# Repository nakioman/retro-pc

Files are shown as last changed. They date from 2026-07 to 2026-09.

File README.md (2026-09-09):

# RetroBox

RetroBox is a self-contained retro computer: a Debian appliance that boots
straight into [86Box](https://86box.net/) fullscreen and lets you choose
between three virtual PCs. It is designed to feel like a physical computer
from the 1980s and 1990s, with the flexibility of a modern emulator.

 Front  | Rear
:------------------:|:------------------:
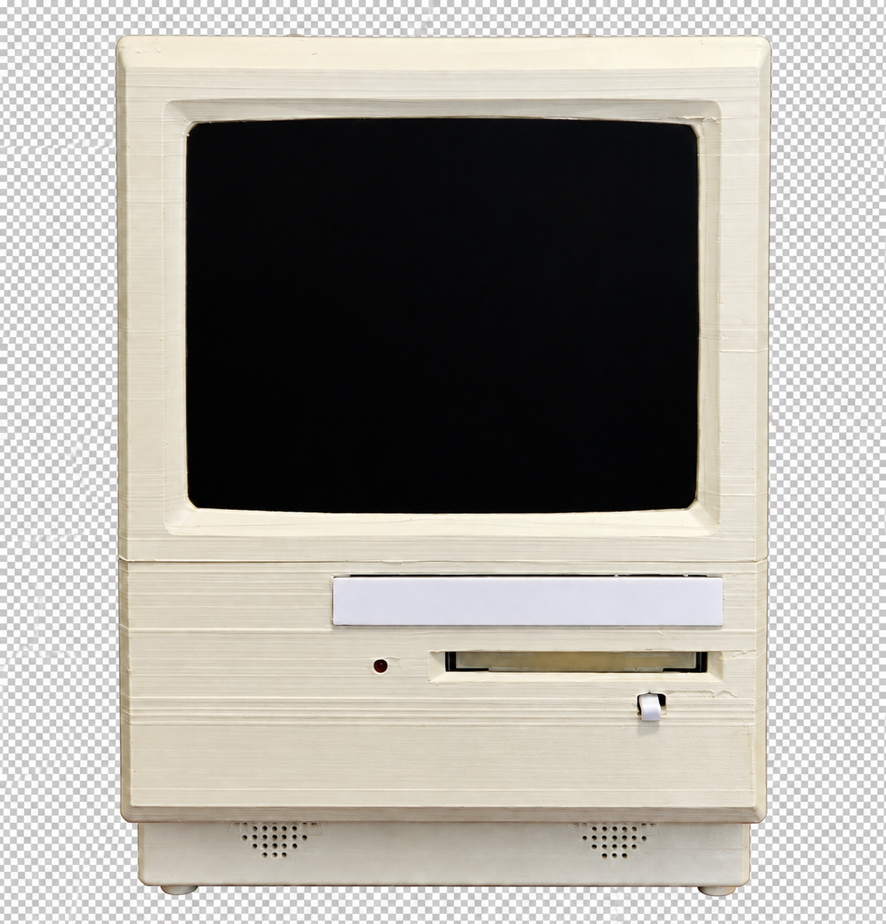
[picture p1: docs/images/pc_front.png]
RetroBox front view
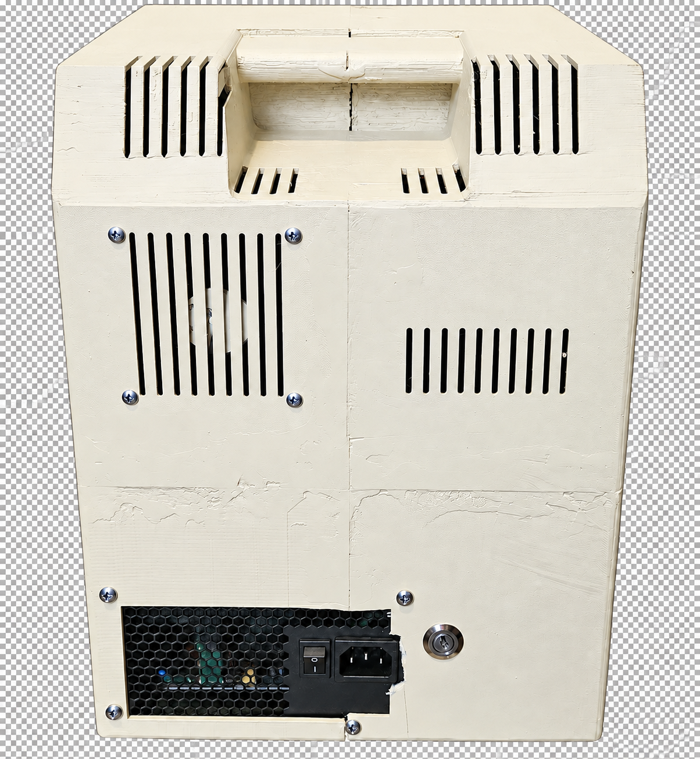
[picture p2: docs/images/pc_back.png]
RetroBox rear view
 | 

## The project at a glance

The reference build uses an Intel Core i3-14100, 8 GB of RAM, integrated
graphics, and an MSI PRO H610M-S DDR4 motherboard. Everything is installed in
a 3D-printed Macintosh Classic-style case, together with a real floppy drive,
an optical drive, and an LCD panel.

The appliance includes three 86Box profiles:

| Profile | Intended use |
| --- | --- |
| 386SX-16 | DOS and early software; 54 MB blank disk. |
| Pentium 100 | Mid-1990s games, Sound Blaster, and CD-ROM. |
| Pentium II 350 | Windows 98 SE, Voodoo3 3000 AGP, AWE64 Gold, and an approximately 20 GB disk. |

On startup, RetroBox launches the default VM fullscreen. Press F12 to open a
text-based selector and switch machines without rebooting. The modified floppy
drive uses an ESP8266 and a PN532 reader: each floppy contains an NFC tag with
the image identifier, so inserting it automatically mounts the matching image
in 86Box. The physical CD-ROM can also be passed through to the VMs.

Left | Right 
:----:|:----:
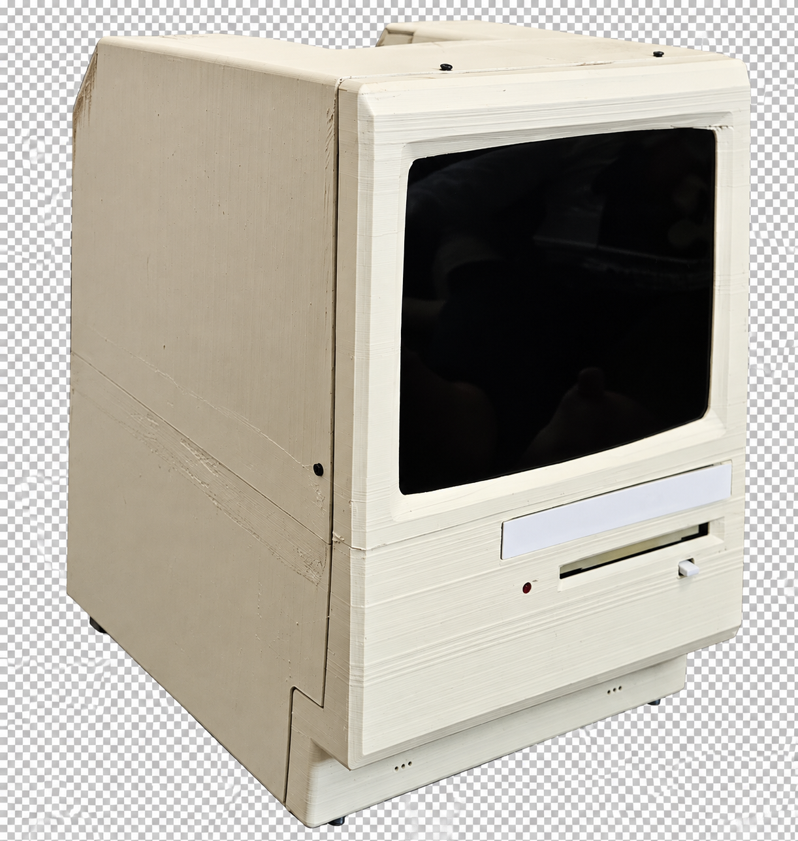
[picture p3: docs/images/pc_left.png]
Left side
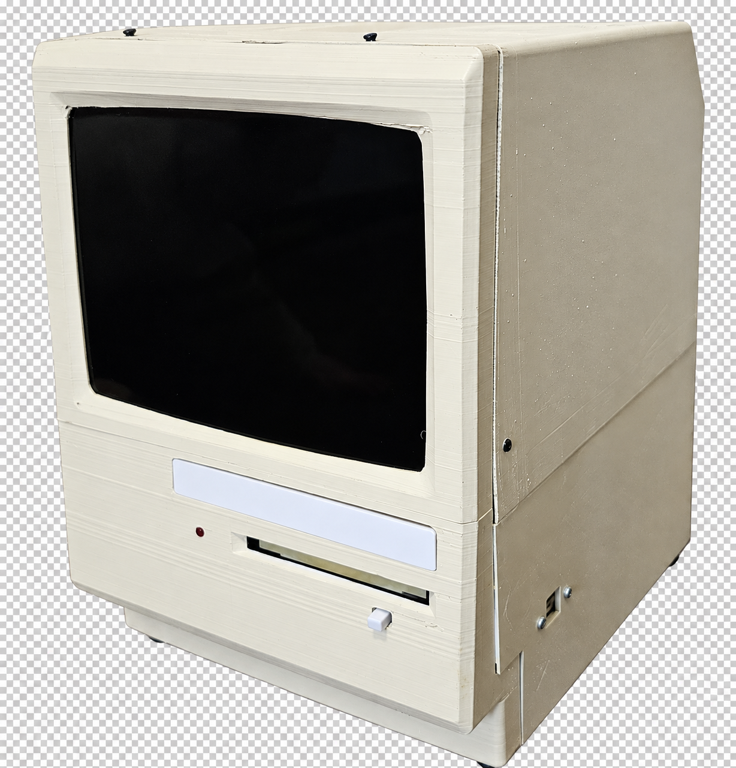
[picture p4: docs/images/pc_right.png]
Right side
 |  

## Use a prepared installation

Download the installer ISO from the [GitHub Releases](https://github.com/nakioman/retro-pc/releases)
page. Each release contains a hybrid installer that supports legacy BIOS and
UEFI.

1. Download `retropc-installer-*.iso` from the selected release.
2. Flash it to a USB drive with Raspberry Pi Imager, balenaEtcher, or an equivalent tool.
3. Boot the target computer from the USB drive and follow the installer.
4. Remove the USB drive and reboot when installation is complete.

The installer configures Wi-Fi when a compatible adapter is available and
detects the optical drive. The installed system uses a read-only root and
stores VMs, catalogs, and persistent configuration under `/data`.

> The installer may erase or repartition the selected disk. Use it on a
> dedicated machine and verify the target disk before confirming.

## Web panel

The appliance includes a web panel for managing the floppy library and game
catalog. Once the appliance is running, open this address from a computer on
the same network:

```text
http://<appliance-hostname-or-ip>:8080
```

The panel's main library view and cover-art workflow:

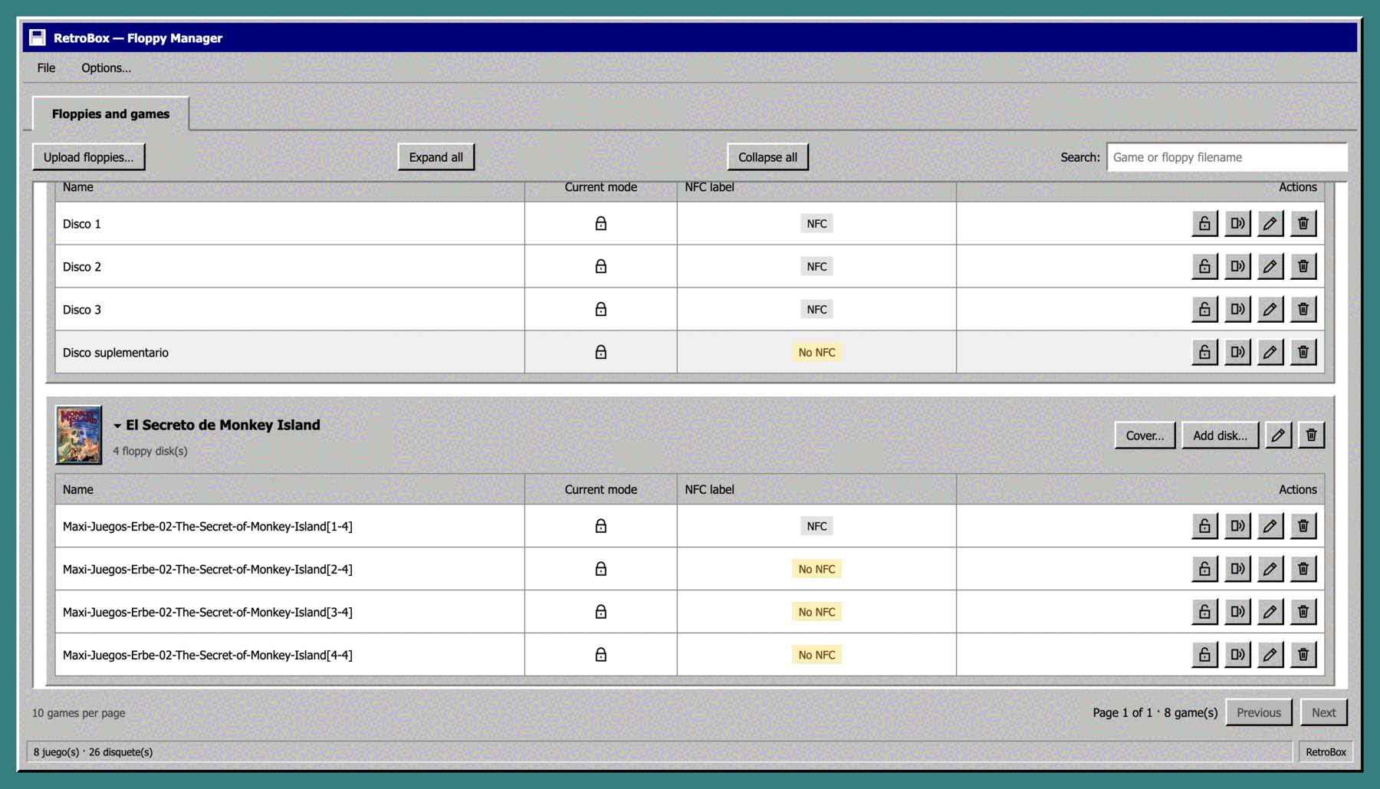
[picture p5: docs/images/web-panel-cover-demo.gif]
RetroBox web panel — cover art workflow


The panel can list, upload, rename, re-mode, group, and delete floppy images.
It also turns ZIP archives of DOS files into a 1.44 MiB FAT12 floppy image;
archives that exceed one disk or contain unsafe paths are rejected.
With the NFC controller connected, it can also show the current drive state and
write a catalog entry to the tag inside a floppy. The panel is hosted by the
daemon and remains available even when the floppy controller is disconnected;
the NFC actions are simply disabled in that case.

The default port is `8080` and can be changed with the daemon's `--web-port`
option. Set `WEB_PORT=0` in `/etc/retrobox/daemon.env` to disable the panel.
The panel intentionally has no authentication or TLS and is designed for a
trusted home LAN. Do not expose it directly to the internet.

## Build your own RetroBox

This repository contains the source code, 86Box profiles, and fabrication files
needed to reproduce the project. You can build the reference system or adapt
the motherboard, display, power supply, and floppy drive to your own hardware.

### Macintosh Classic case

[`hardware/mac-classic-case/`](hardware/mac-classic-case/) contains the
parametric OpenSCAD model, rendered STLs, bill of materials, assembly guide,
and parameters for adapting the motherboard, power supply, LCD, drives, and
floppy drive. Every part fits on a 250 × 250 × 250 mm print bed.

```bash
mise run case-stl                 # all parts
mise run case-stl -- front-upper  # one part
```

### NFC floppy

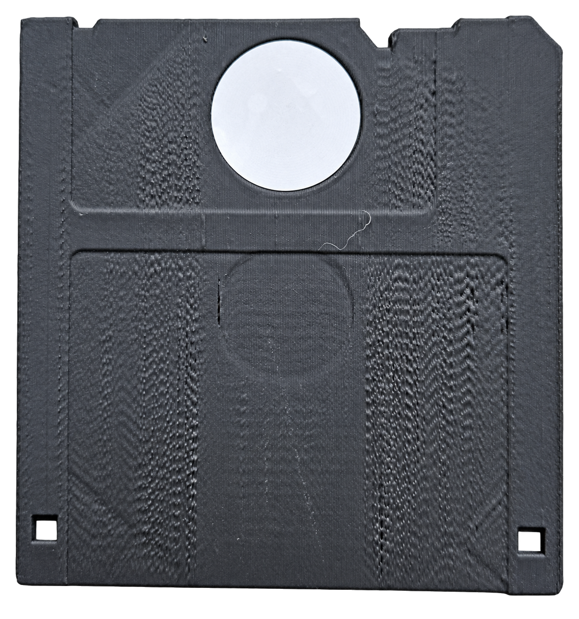
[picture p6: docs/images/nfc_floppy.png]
NFC Floppy


[`hardware/floppy-nfc-blank/`](hardware/floppy-nfc-blank/) contains the
printable floppy model, NFC tag seat, bill of materials, parameters, and read
tests. The tag stores raw bytes in the `<id>,<mode>` format; it does not use
NDEF.

```bash
mise run floppy-stl
```

The reader electronics and firmware are in
[`firmware/retrofloppy-esp8266/`](firmware/retrofloppy-esp8266/README.md).

## Development

### Requirements and commands

- [mise](https://mise.jdx.dev/), which pins the project tools.
- Docker to build the ISO on macOS or Linux.
- An ESP8266 connected when compiling or flashing firmware.

```bash
mise install
mise run restore
mise run test
mise run format-check
```

You do not need to invoke `dotnet` directly; supported workflows go through
`mise`.

| Area | Location | Responsibility |
| --- | --- | --- |
| Core | [`src/RetroBox.Core`](src/RetroBox.Core) | YAML catalogs, VM selection, NFC, serial, and the 86Box socket. |
| CLI | [`src/RetroBox.Cli`](src/RetroBox.Cli) | `boot`, `daemon`, `vm`, `floppy`, `import`, and `nfc` commands. |
| Daemon/web | [`src/RetroBox.Daemon`](src/RetroBox.Daemon) | Floppy events, 86Box mounting, and the web panel. |
| Frontend | [`src/frontend`](src/frontend) | React/Vite panel, packaged by `RetroBox.Web`. |
| Firmware | [`firmware/retrofloppy-esp8266`](firmware/retrofloppy-esp8266) | NFC read/write over USB serial. |
| Appliance | [`appliance`](appliance/README.md) | Debian 13, systemd, read-only root, and USB installer. |
| Tests | [`tests/RetroBox.Tests`](tests/RetroBox.Tests) | xUnit tests. |

### Development loop

```bash
mise run frontend-install
mise run frontend-lint
mise run frontend-format-check
mise run frontend-build
mise run test
mise run format-check
```

Build the Linux x64 runtime and firmware:

```bash
mise run publish-linux-x64
mise run firmware-compile
mise run firmware-upload -- /dev/cu.usbserial-XXXX
```

### Build the installer ISO

```bash
docker build --platform linux/amd64 -t retropc-builder appliance/installer
docker run --rm --platform linux/amd64 --privileged \
  -v "$PWD:/work" retropc-builder \
  /work/appliance/installer/build-usb-installer.sh
```

The result is written to `appliance/installer/out/retropc-installer.iso`. The
GitHub Actions workflow performs the same build, publishes the artifact, and
attaches the ISO to each release. See
[`appliance/installer/README.md`](appliance/installer/README.md) for detailed
flashing, installation, and validation instructions.

## Technical documentation

- [`docs/architecture.md`](docs/architecture.md) — architecture and runtime flow.
- [`docs/vm-profiles.md`](docs/vm-profiles.md) — the three VM configurations.
- [`docs/floppy-controller-wiring.md`](docs/floppy-controller-wiring.md) — electronics.
- [`docs/cdrom-passthrough.md`](docs/cdrom-passthrough.md) — physical CD-ROM.
- [`docs/86box-floppy-control-socket-contract.md`](docs/86box-floppy-control-socket-contract.md) — 86Box protocol.
- [`hardware/mac-classic-case/README.md`](hardware/mac-classic-case/README.md) — case fabrication.
- [`hardware/floppy-nfc-blank/README.md`](hardware/floppy-nfc-blank/README.md) — NFC floppy fabrication.
- [`CONTRIBUTING.md`](CONTRIBUTING.md) — contribution and style guidelines.

## Contributing

Create a branch, add or update tests, run `mise run test` and
`mise run format-check`, and follow Conventional Commits. Important
architectural decisions are recorded in [`docs/decisions/`](docs/decisions/).

## License

The code is licensed under MIT; see [`LICENSE`](LICENSE). The case and floppy
also include the attributions and licenses for their original models.

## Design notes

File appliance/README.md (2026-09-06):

# Retro PC Debian Appliance Base

This directory documents the base operating-system layout for the Retro PC
appliance. The target is Debian 13 (trixie), installed as a minimal physical
system and extended with the runtime packages listed in
[`debian/packages.txt`](debian/packages.txt).

The official `debian:13-slim` image is used as a reference for keeping the
package set small. It is not the appliance image: a container does not model
the physical machine's systemd boot, audio, USB/serial, CD-ROM, input, or
graphics devices. The final deployment is a normal Debian installation on the
appliance hardware.

## Runtime shape

The normal user experience is 86Box in fullscreen. Linux remains an
implementation detail and does not provide a desktop environment. 86Box is
deployed as `/opt/86Box/86box.AppImage` with ROMs in `/opt/86Box/roms`, while
`/opt/retrobox/retrobox` is the self-contained Native AOT Linux x64 binary
produced by the repository's publish task. Versions and checksums are pinned in
[`86box.env`](86box.env).
This document defines the base layout. The bootable USB installer that turns it
into an installed, read-only-root system on the appliance disk lives under
[`installer/`](installer/README.md); the installer is the authoritative source
for the systemd units, read-only-root enforcement, and account
setup described below until the standalone child issues (#28, #29, #30) land.

## Machine selector

Press F12 during the boot window to open the plain-text machine selector. Press
the VM's displayed number to start it, or press `D` and then a number to set
that VM as the default and start it immediately. `Esc` cancels; when a default
already exists, cancellation starts that default.

When a VM is closed, the selector returns so another VM can be started without
rebooting the appliance. `Esc` on that returned selector ends the session and
returns to the tty1 login; it does not restart the previous VM.

The Plymouth boot splash stays on screen until 86Box's first frame: `retrobox
boot` retains it right before launching a VM (so no boot or 86Box loading text
is visible) and quits it whenever the terminal selector is shown.

The floppy daemon re-syncs the drive whenever a VM starts: once the 86Box
floppy-control socket is ready it asks the floppy controller for the current
physical floppy (`STATUS` over serial) and applies it, so floppy swaps made
while the VM was off are loaded when it powers on.

## Web panel

The appliance hosts an unauthenticated floppy management panel on the LAN at
`http://<appliance>:8080`. The panel lists, uploads, renames, re-modes, and
deletes cataloged floppies, and creates, edits, and deletes game groups; it
runs whether or not the floppy controller is attached. A group records an
ordered set of cataloged floppies in `/data/retrobox/games.yaml`; a floppy can
be in one group or remain ungrouped. Deleting a group never deletes its
floppies or image files. Disable the panel by setting `WEB_PORT=0` in
`/etc/retrobox/daemon.env`; an unusable value there (empty, or not a port
number) disables the panel too and says so in the journal, rather than stopping
the daemon.

A floppy uploaded through the panel is listed but cannot be inserted until an
NFC tag is written for it: uploads always land untagged, and the daemon refuses
to mount an untagged floppy. The panel shows those with a "No NFC" badge.
Assigning a tag means putting the physical disk in the drive and using the
panel's drive section: it reads whatever tag is currently seated, offers the
catalog to assign it to, and writes it over the same serial connection the
daemon already holds — no stopping the service, no console command.

## Accounts and permissions

The appliance uses a single account, `retrobox`.

`root` is locked (`passwd -l root`): there is no interactive root login on the
console or over SSH. `retrobox` is both the service runtime user (it owns the
application state under `/data/retrobox`) and the maintenance login. It is a
member of the `sudo` and `gpio` groups. The installer creates the `gpio` group
and installs a udev rule granting `retrobox` access to GPIO chip devices.
There is no separate administrator account.

The `retrobox` password is set during installation (the installer prompts for
it) and is required for SSH login and `sudo`. Maintenance is performed over SSH
as `retrobox`; `PermitRootLogin` is disabled.

## WiFi

The appliance detects a `wl*` interface at boot (`retrobox-wifi-firstboot`).
With no WiFi NIC, wired DHCP is the only network path. When a WiFi NIC is
present the first boot prompts for the SSID and password on tty1 with
`dialog`, persists them to `/data/system/wifi.conf` (root:root, 0600), and
materializes wpa_supplicant + systemd-networkd config into `/run` so the
read-only root is never written at runtime. The prompt runs once; later
boots reconnect from the saved credentials.

Reconfiguring WiFi is manual: edit `/data/system/wifi.conf` and remove
`/data/system/wifi-configured`, then reboot. `firmware-realtek` is bundled
(from the `non-free-firmware` component), so Realtek USB dongles — including
the TP-Link 2.4GHz and similar rtw88/rtl8188/rtl8192 devices — work out of
the box without extra packages. `wpasupplicant` is the association backend
because systemd-networkd has no native `[WiFi]` support.

## Persistent and immutable state

The intended appliance model is a read-only root filesystem with persistent
application state below `/data`. This document records the target contract; it
does not implement the mounts or the required tmpfs/overlay configuration.

Persistent application data lives in the layout described in
[`filesystem-layout.md`](filesystem-layout.md). Runtime-generated state such as
`/run/retrobox/86box-floppy.sock`, logs, PID files, and temporary files must be
handled by the eventual systemd/read-only-root design rather than written into
the immutable application tree.

## Maintenance checklist

An administrator connecting over SSH should be able to:

1. Inspect `retrobox` YAML catalogs under `/data/retrobox`.
2. Use the web panel to upload and manage floppy images.
3. Inspect VM directories and snapshots without changing the base OS.
5. Collect service and hardware diagnostics once the systemd units exist.

No DOS, Windows, drivers, games, floppy images, or other copyrighted media are
included by this base layout.

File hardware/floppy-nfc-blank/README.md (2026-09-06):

# Floppy NFC disk (3D printable)

A printable 3.5" floppy for the RetroBox floppy controller: two shell halves
(`top.stl` + `base.stl`, made in Shapr3D) joined into one part, with a round
NFC tag seated in the middle of the head-window zone so the PN532 reads the
`<id>,<mode>` payload on insert.

Source: [`floppy-nfc.scad`](floppy-nfc.scad). The shells (`top.stl` +
`base.stl`) are ["3.5" Floppy Disk" by polymatt](https://www.printables.com/model/1380130-35-floppy-disk)
(CC BY 4.0), made for [this video](https://www.youtube.com/watch?v=TBiFGhnXsh8),
and are committed here under that licence. They arrive already positioned as an
assembly — the base's walls rise to z = 2.4 and the top sits exactly on that
plane — so the union produces the closed disk with no repositioning. The
rendered `floppy-nfc.stl` is committed; regenerate it with
`mise run floppy-stl` after changing the source.

## What the model does

- **Joins the halves as designed.** Head window (open, cut through), leading
  edge notches, write-protect/ID holes, hub recess, walls: all exactly as the
  source shells define them. Nothing is cut into the outline.
- **Adds the NFC tag seat, opening on the top face.** The shells are too thin
  in the window zone for a blind seat, so a short pedestal hangs from the top
  plate and the ⌀25.4 mm × 1.2 mm seat is sunk into it from above. The sticker
  ends up 0.4 mm below the label field with a 0.6 mm floor behind it, and the
  pedestal reaches no further down than that floor — its underside stays a full
  millimetre inside the bottom face, so nothing shows on the back: through the
  open window you only see it deep inside, like the media of a real disk. Seat
  centre is 16 mm behind the leading edge on the disk centreline — the
  placement the bench validated. `tag_face = "bottom"` mirrors the seat onto
  the back face; `tag_seat = false` gives the raw union.

## Bill of materials

| Part | Notes |
| --- | --- |
| Round NTAG21x / MIFARE Ultralight sticker, 25 mm | Payload is raw `<id>,<mode>` bytes in pages 4–11 (ADR 0004). |
| ~10 g of PLA or PETG | **Not** carbon-filled or metallic filament — the filler shields the antenna and the tag stops reading. |

## Render and print

```bash
mise run floppy-stl
```

- Flat on the bed, tag seat up (back face on the bed), no supports, 0.15 mm
  layers.
- The shell is hollow like a real floppy (1.2 mm internal gap), so the top
  plate prints as a bridge anchored on the walls and the pedestal. Enable good
  bridging/cooling; a slight sag inside is cosmetic only.
- Elephant-foot compensation on — a splayed first layer is the usual reason a
  print that measures right still binds in the slot.

## First print

The seat is blind, so it matters which face the antenna looks at. Stick the tag
in, insert the disk, and watch the firmware:

```bash
mise run nfc-test -- monitor
```

`INSERT <id>,<mode>` is a good read; `ERROR TAG not read` is not. If it does
not read, set `tag_face = "bottom"` and print again — the seat mirrors onto the
back face.

Fit checklist:

- [ ] Slides in and out by hand; the tag reads only once the blank is fully
      seated (`INSERT` fires), and stops reading when it is pulled out
      (`EJECT` follows after the ~⅓ s polling hysteresis).
- [ ] The drive's shutter mechanism runs free through the open window band.
- [ ] `mise run nfc-test -- cycles 10` reports 10 ok, 0 missed.

## Programming the tag

On the appliance, program the tag from the web panel: put the blank in the
drive and use the panel's drive section, which writes it over the serial
connection the daemon already holds and records the tag's UID in the catalog
alongside `nfc: true`.

The commands below are for a bench rig with no daemon running — they need the
serial port to themselves, and neither of them records the tag's UID, so a
floppy tagged this way is left without the UID the panel uses to spot a tag
that already belongs to another disk.

```bash
mise run cli -- nfc write <id>            # looks the id up in floppies.yaml
mise run nfc-test -- write <id>,<mode>    # raw payload, no catalog lookup
```

The id must be lowercase letters, digits, and single hyphens; the mode is `ro`
or `rw` — `RetroBoxArduinoSerialProtocol` rejects anything else on insert.

## Parameters worth knowing

| Parameter | Default | Why you would change it |
| --- | --- | --- |
| `tag_diameter` | `25` | Match your sticker. |
| `tag_offset_from_leading_edge` | `16` | Re-aim the tag at the antenna if the module is not over the head window. |
| `tag_face` | `"top"` | Which face the seat opens on — the face the antenna looks at. |
| `tag_seat` | `true` | `false` renders the raw union of the two shells. |
| `pedestal_margin` | `2` | How far the solid backing extends beyond the seat. |

## Known constraint: shielding

The drive chassis is all-metal and blocks the antenna, which is why the bench
unit runs with the drive's outer cover removed and the tag placed at the head
opening (`docs/floppy-controller-wiring.md`). This disk keeps that geometry.
Reinstalling the metal cover will break reads no matter how the disk is printed.

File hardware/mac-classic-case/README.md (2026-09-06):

# Macintosh Classic case (3D printable)

A full-size (1:1) Macintosh Classic style case that houses the RetroBox PC:
a micro-ATX motherboard, a standard ATX power supply, a real 3.5" floppy
drive and a slim tray-load DVD drive behind the classic front slots, a 9.7"
retina LCD behind the screen window, and a 2.5" drive on the rear wall.

Source: [`mac-classic-case.scad`](mac-classic-case.scad). The shell geometry
is Jeroen Domburg's 1:6 [mini Mac](https://spritesmods.com/?art=minimac)
(beer-ware license, notice retained in the file), rescaled to 1:1 and
reworked into a working PC case. Every part fits a 250 × 250 × 250 mm bed:
the shell splits into front/back halves (original design), each half splits
horizontally, and the back pieces additionally split vertically.

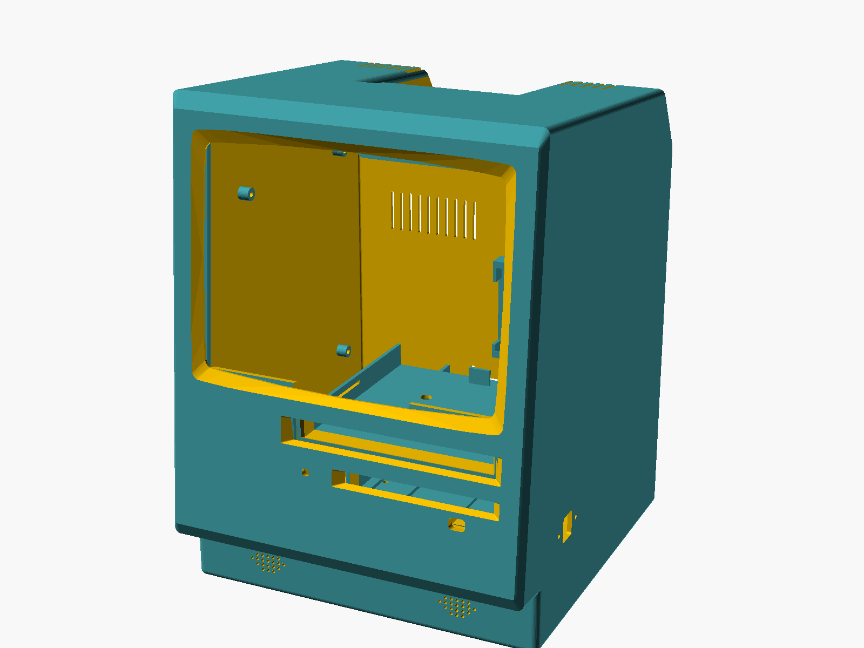
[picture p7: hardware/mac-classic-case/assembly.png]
Assembled case


## Layout

- **Motherboard** — micro-ATX (244 × 200) standing on edge against the left
  wall, components inward, IO shield facing the case front: IO block ends up
  top-front, expansion slots at the bottom. Printed standoffs with M3
  heat-set inserts.
- **PSU** — ATX (PS/2) on the floor, bottom right, tail against the rear
  wall: rear cutout + the real (asymmetric) ATX screw pattern. Floor stops
  keep it from shifting.
- **Drives** — a printed cage holds the floppy below and the slim DVD above,
  standing on two pedestals screwed to floor bosses. The drives slide in from
  the front and separate guide funnels bridge the gap to the sloped front
  slots. A printed cap replaces the floppy's eject button and a funnel-shaped
  cover glues to the DVD tray, with an invisible press-to-eject membrane.
- **Screen** — a 9.7" iPad 3/4 retina panel rests against the front's inner
  face, clamped by a printed frame that doubles as the structural bridge
  between the two front pieces. The HDMI driver board mounts on the right
  wall; its OSD button strip hides under the front chin, buttons pointing
  down.
- **Rear wall** — 2.5" drive in a printed cradle with a clip finger, 80 mm
  exhaust fan, passive vent slots, 16 mm power button.
- **Front details** — HDD activity LED next to the floppy slot, speaker
  grilles in the recessed bottom band (speakers glue behind them), dual USB-A
  on the right wall.

## Bill of materials

| Part | Notes |
| --- | --- |
| micro-ATX motherboard, 244 × 200 | Verified: Biostar H55 HD and MSI PRO H610M-S DDR4 (i3-14100, stock cooler). Check your board's holes against `mobo_hole_on`. |
| ATX (PS/2) power supply | Default fits up to 140 mm deep (`psu_depth` accepts more). Verified: EVGA 600W. |
| 3.5" PC floppy drive | Modeled on the NEC FD1231T **with its eject button removed** — the printed cap grips the bare eject lever (`fdd_latch`). |
| Slim SATA optical drive, 12.7 mm tray-load | Plus a slimline-SATA to SATA adapter cable. |
| 2.5" drive | HDD or SSD; the cradle takes 7–9.5 mm heights. |
| 9.7" iPad 3/4 retina panel (2048 × 1536) | Verified: Sharp LQ097L1JY01Z; LG LP097QX1 dimensions are the defaults. Measure `lcd_w/lcd_h/lcd_th/lcd_bottom_border` against your panel. |
| HDMI driver board kit for the LP097QX1 | The generic eDP kit with OSD button strip (107 × 16.5) and speaker output. |
| 2 × oval speakers, 20 × 30 mm | Driven by the LCD kit. Glued behind the front grilles. |
| 80 × 80 × 25 mm fan | Rear exhaust, 4 self-tapping M4 from outside. |
| Dual USB-A panel-mount connector | 30 mm screw centers; wired to a motherboard header. |
| 16 mm momentary panel-mount button | Power, wired to F_PANEL. |
| 5 mm red LED | HDD activity, wired to F_PANEL; press-fit + CA from behind. |
| 46 × M3 heat-set inserts | d4.0 × ≥6.5 (Ruthex/Voron standard). |
| M3 screws | ~24 pan head (cage, split joints, LCD frame), ~12 countersunk (front floor, HDD cradle, seam flaps), 2–4 into the floppy's threaded side holes. |
| M2 screws | 4, into the DVD drive's threaded side holes. |
| M2.5 self-tapping screws | 2–3 for the OSD strip. |
| #6-32 screws | 4 for the PSU (usually included with it). |
| Cyanoacrylate glue | Funnels, eject cap, DVD tray cover, speakers, LED, TPU feet, front seam. |
| PETG filament | Case parts. |
| TPU filament | The 4 feet. |

## Printed parts

Rendered STLs are committed under [`stl/`](stl/) — these are the exact files
the reference build was printed from. Regenerate any of them from the source
with `mise run case-stl -- <part> [...]` (no arguments renders all; the shell
pieces take a long time on OpenSCAD's CGAL backend).

Every part renders already oriented for printing. Reference build: PETG on an
Anycubic Kobra S1 (feet in TPU).

| Part | Piece | Print notes |
| --- | --- | --- |
| `front-lower` | Front shell, floor to z=146 | Supports: local, under the side-flap plates. |
| `front-upper` | Front shell with screen window and handle | Supports: local, under the top-flap plates (12 × 28, two spots) and the high side-flap plates. |
| `back-lower-left` / `back-lower-right` | Rear shell quarters with PSU cutout, floor bosses | Printed upright as rendered. |
| `back-upper-left` / `back-upper-right` | Rear shell quarters with vents, fan mount, handle | Lying on the flat rear wall. |
| `drive-cage` | Floppy + DVD bays | On its left face, no roof — bridges over the bays. |
| `cage-pedestals` | Both cage supports | Flat, no supports. |
| `fdd-funnel` / `dvd-funnel` | Front slot guides | Mouth down; supports touching the outside only, so the guiding interior stays clean. |
| `hdd-cradle` | 2.5" drive carrier with clip | Flat, no supports. |
| `lcd-frame` | Panel clamp frame | Flat, no supports. |
| `dvd-tray-cover` | Tray plug with eject membrane | Face down; the membrane prints as the first layers of the recess, no supports. |
| `eject-cap` | Floppy eject button | As rendered; the hook slot prints as an internal bridge. |
| `tpu-feet` | 4 floor feet | TPU, desk face on the bed. |

The `assembly`, `cutaway` and `cage-assembly` values of the `part` variable
are viewing modes for inspection (set `show_hardware = true` to preview ghost
hardware in place).

## Assembly

1. **Inserts.** Melt the 46 M3 inserts into every boss: motherboard
   standoffs, cage floor bosses, pedestal flanges, LCD frame bosses, split
   joints, seam flaps, HDD bosses, HDMI standoffs, front floor tabs.
2. **Back shell.** Join left/right lower quarters (vertical tongue + M3),
   the upper quarters the same way, then upper onto lower: the overlap ring
   seats and the L-tabs screw horizontally into the bosses from inside.
3. **Rear hardware.** Motherboard onto its standoffs, PSU (4 rear screws,
   floor stops locate it), fan, power button. Screw the HDD cradle over the
   split seam — it bridges the two rear pieces — and clip the drive in,
   SATA to the left.
4. **Drive cage.** Screw the pedestals to the floor bosses, then the cage
   base onto the pedestal flanges through the access holes in the DVD shelf.
   Slide both drives in from the front and fix them with their side screws
   (sliding slots let you set the depth). Glue the DVD funnel, then the
   floppy funnel, onto the bay mouths by their hug plates. With a diskette
   inserted, press the eject cap onto the bare eject lever and glue it. Glue
   the tray cover to the DVD tray by its two pads.
5. **Front shell.** Glue the two front pieces at the seam. Drop the panel
   into the LCD frame's centering pocket and screw the frame to the 6 bosses
   — it clamps the panel and bridges the front seam (the press bar also
   flattens any cage warp). Screw the OSD strip under the chin, glue the LED
   and the speakers.
6. **Close.** Route the PSU harness and USB cable through the left pedestal
   window, connect the panel, seat the front (the retainers center the cage)
   and screw it: 2 countersunk M3 from under the floor into the tabs, then
   the 6 seam flap screws (2 top, 2 low sides, 2 high sides).
7. **Feet.** Glue the TPU feet under the floor; the front pair pockets hide
   the floor screw heads.

## Parameters worth knowing

| Parameter | Default | Why you would change it |
| --- | --- | --- |
| `mobo_hole_on` | hole S off | Match your board's actual mounting holes. |
| `psu_depth` | `140` | Deeper PSUs exist (125–180). |
| `lcd_w/lcd_h/lcd_th/lcd_bottom_border` | LQ097L1JY01Z | Measure your panel before printing the front. |
| `hdd_sata_off` / `hdd_sata_from_bottom` | `10` / `true` | Align the cradle window with your drive's SATA block. |
| `fdd_latch` | FD1231T | Eject lever position; re-measure for another drive. |
| `odd_cover_gap` | `9.96` | Outer skin to DVD tray face; tune if the cover sits proud or sunken. |
| `odd_nub_gap` | `0.25` | Eject nub reach; lower if it doesn't click, raise if it self-triggers. |

## License

The case geometry derives from Jeroen Domburg's mini Mac and keeps its
beer-ware license notice in the source file.

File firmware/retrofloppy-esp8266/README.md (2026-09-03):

# retrofloppy-esp8266

ESP8266 firmware for the modified floppy drive: reads and writes the NFC tag
glued inside a floppy shell with a PN532 over I2C, and reports insert/eject
events to the Retro PC over USB serial.

The tag doubles as the disk-present sensor: the firmware polls the PN532
continuously, so a tag entering the field means a floppy was inserted and a
tag leaving the field means it was ejected. There is no mechanical
disk-present switch.

Target board: NodeMCU v2 (`esp8266:esp8266:nodemcuv2`).

## Hardware

### PN532 board mode

The firmware talks to the PN532 over **I2C only**, at 7-bit address `0x24`
(`0x48` shifted right by one). Set the board's mode selector to I2C before
wiring it up:

- Adafruit-style breakout: `SEL0 = ON`, `SEL1 = OFF`.
- Elechouse-style module: set the two DIP switches to the row silkscreened as
  I2C. Labels vary between clones, so follow the silkscreen rather than a
  remembered switch order.

Some boards ship with I2C pull-ups populated and some do not. If reads are
flaky, add 4.7 kΩ pull-ups from SDA and SCL to 3.3 V.

### Wiring

```text
NodeMCU 3V3       -> PN532 VCC
NodeMCU GND       -> PN532 GND
NodeMCU D1 (GPIO5) -> PN532 SCL
NodeMCU D2 (GPIO4) -> PN532 SDA
```

D1/D2 are the ESP8266 default `Wire` pins; the firmware calls `Wire.begin()`
with no arguments, so the pins are not configurable without a code change.

**Reset pin: not used.** The PN532 `RSTPD_N` / `RST` pad is left unconnected and
the module is reset only by power cycling the NodeMCU. This keeps every
boot-sensitive GPIO free and avoids the `D0`/GPIO16 limitations. If a hard reset
line turns out to be necessary on the bench, pick a pin from the safe list below
and update this section.

`IRQ` is also unconnected — the firmware polls the PN532 instead.

### Disk-present detection

There is no disk-present switch. The firmware polls the PN532 with fast-fail
activation (`setPassiveActivationRetries(0x01)`), and presence of the tag in
the field is what defines the drive state. The poll rate is asymmetric: every
100 ms while a disk is seated (`POLL_INTERVAL_INSERTED_MS`, a cheap presence
check) and every 250 ms while the drive is empty (`POLL_INTERVAL_EMPTY_MS`, a
full detect+read):

- A tag becoming readable emits `INSERT <payload>` — so the event fires only
  once the disk is seated well enough to actually read, never mid-insertion.
- A tag that is coupled but whose payload cannot be read for 4 consecutive
  polls (~1 s) emits `ERROR TAG not read` once.
- A seated tag missing **3 consecutive polls** (~300–400 ms) emits `EJECT`.
  The hysteresis absorbs the occasional single missed read of a seated tag.

The consequence to be aware of: a floppy without a tag (or with a dead tag
that does not couple at all) is indistinguishable from an empty drive.

### Pins to avoid

Do not move the PN532 onto these without checking boot behaviour:

| Pin | GPIO | Why |
| --- | --- | --- |
| `D0` | 16 | No interrupt and no internal pull-up; wired to RST for deep sleep. |
| `D3` | 0 | Must be HIGH at boot; LOW selects flash programming mode. |
| `D4` | 2 | Must be HIGH at boot; also the onboard LED. |
| `D8` | 15 | Must be LOW at boot; a module pulling it up blocks booting. |
| `TX`/`RX` | 1 / 3 | The USB serial link to the Retro PC. |

## Tag layout

Tags are NTAG21x / MIFARE Ultralight. The payload is written as **raw bytes into
pages 4 through 11** — 8 pages × 4 bytes = **32 bytes maximum** — zero-padded to
the end of the last page.

This is deliberately *not* an NDEF record, so the tags are not phone-readable as
text. Reads stop at the first `0x00` byte and trim trailing whitespace.

## Build and upload

The toolchain, the ESP8266 core, and every library are pinned in `sketch.yaml`
(profile `esp8266`), so no separate bootstrap step is needed — `arduino-cli`
installs what the profile asks for on the first compile. The PN532 and PN532_I2C
libraries are vendored under `lib/`.

```bash
mise install
mise run firmware-compile
```

Compile and upload in one command, replacing the port with the one used by the
connected board:

```bash
mise run firmware-upload -- /dev/cu.usbserial-XXXX
```

On macOS the port usually looks like `/dev/cu.usbserial-XXXX` or
`/dev/cu.SLAB_USBtoUART`.

## Serial protocol

115200 baud, 8N1, newline-terminated lines. On boot the firmware prints its
protocol version:

```text
INIT 1
```

### Commands accepted from the host

| Command | Success | Failure |
| --- | --- | --- |
| `WRITE <payload>` | `OK` | `ERROR not written` |
| `TAGID` | `Tag ID: <uid-hex>` | `ERROR no-tag-detected` |
| `STATUS` | `INSERT <payload>` (floppy present) / `EJECT` (drive empty) | `ERROR no-tag-detected` |

`WRITE` takes the payload verbatim — for RetroBox that is `<id>,<mode>`, e.g.
`WRITE monkey1-disk1,ro`. The firmware only rejects payloads longer than 32
bytes; it does not validate the `<id>,<mode>` shape, so the host is responsible
for sending a well-formed payload.

`STATUS` reports the drive's current state on demand, reusing the same event
lines as the unsolicited insert/eject notifications so the daemon can re-sync
a VM that just started without extra parsing. It answers from the state the
NFC polling loop already tracks — `INSERT <payload>` with the cached payload,
`EJECT` when empty, and `ERROR no-tag-detected` when a tag is coupled but
unreadable — so it costs no extra tag read.

Any other non-empty line is echoed back as `ERROR <line>`.

### Events emitted by the firmware

These are unsolicited, driven by the NFC presence-polling loop:

| Event | Meaning |
| --- | --- |
| `INSERT <payload>` | A tag entered the field and its payload read successfully. |
| `ERROR TAG not read` | A tag is coupled but stayed unreadable for ~1 s. |
| `EJECT` | The tag left the field for ~1 s (floppy removed). |

`INSERT`, `EJECT`, and `ERROR <message>` are the three lines the `retrobox`
daemon parses (`RetroBoxArduinoSerialProtocol`).

## Serial monitor test

```bash
arduino-cli monitor -p /dev/cu.usbserial-XXXX --config baudrate=115200
```

If `arduino-cli` is not on the shell path, run it through mise:

```bash
mise exec -- arduino-cli monitor -p /dev/cu.usbserial-XXXX --config baudrate=115200
```

Press the board's reset button after opening the monitor if the boot line does
not appear. Expected interaction with a tag held against the antenna:

```text
INIT 1
TAGID
Tag ID: 04A2B3C4D5E6F7
WRITE monkey1-disk1,ro
OK
HELLO
ERROR HELLO
```

And inserting/removing a tagged floppy (or just moving the tag in and out of
the antenna's range by hand):

```text
INSERT monkey1-disk1,ro
EJECT
```

The `EJECT` line arrives a few hundred milliseconds after the tag leaves the
field — that is the polling hysteresis, not a fault.

Use `Ctrl+C` to exit the monitor. Close it before running
`mise run firmware-upload`, since both need exclusive access to the port.

## Scripted bench test

`scripts/retrofloppy-nfc-test.sh` drives the same protocol from a plain shell,
which is the quickest way to tell a firmware/NFC problem apart from a daemon
problem: it warns when `retrobox-daemon` already owns the port, and it tallies
results instead of leaving them to be eyeballed in a monitor.

```bash
mise run nfc-test -- ping            # link and firmware alive
mise run nfc-test -- status          # on-demand read of the seated disk
mise run nfc-test -- tagid           # PN532 sees the tag at all
mise run nfc-test -- soak 30 0.5     # 30 on-demand reads, tallied
mise run nfc-test -- cycles 10       # 10 physical inserts, tallied
mise run nfc-test -- write monkey1-disk1,ro
```

The port is autodetected (`/dev/serial/by-id/*`, then `ttyUSB*`/`ttyACM*`, then
the macOS `cu.*` names); override it with `--port`.

`soak` and `cycles` measure two different paths: `soak` asks `STATUS`
repeatedly with the disk already seated (answered from the firmware's cached
state), while `cycles` exercises the unsolicited insert/eject events the
daemon consumes, driven by the NFC presence polling. A lossy `cycles` run now
points at antenna coupling — the tag not becoming readable in the seated
position — rather than at a timing race, since `INSERT` only fires once the
payload actually reads.

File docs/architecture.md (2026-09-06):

# RetroBox Architecture

## Overview

RetroBox is a retro PC appliance: a minimal Debian 13 host that boots into a
fullscreen 86Box virtual machine so it feels like a DOS-era console. Physical
hardware integrates through two channels:

- A **modified floppy drive** — a NodeMCU (ESP8266) reads/writes an NFC tag
  glued inside each floppy shell and reports insert/eject to the host over USB
  serial.
- A **physical CD-ROM** — passed through to the guest via `ioctl://` device
  paths configured at install time.

Everything else (Linux, systemd, the emulator) is an implementation detail the
user should never notice.

## Runtime flow

```text
power on
  -> Plymouth splash
  -> retrobox boot
       F12 pressed? -> terminal VM selector (start / set default / cancel)
       otherwise    -> default VM
  -> 86Box fullscreen (SDL, CRT shader)
       VM exit -> selector returns, so another VM can start without rebooting
  -> 86Box exits -> tty1 login
```

On the first boot with a USB WiFi NIC attached, `retrobox-wifi-firstboot`
prompts for the network credentials on tty1 before `retrobox boot` takes over;
every boot it materializes the wpa_supplicant config and a slim networkd
`/run/systemd/network/30-wifi.network` from `/data/system/wifi.conf`. The
supplicant does the WPA2-PSK association (systemd-networkd has no native
support); `firmware-realtek` (from the `non-free-firmware` component) is
bundled so Realtek USB dongles work without extra packages (see `0005`).

A long-lived daemon (`retrobox daemon`) supervises floppy hardware during the
session:

```text
NodeMCU/PN532 (USB serial, 115200)
  -> INSERT <id>,<mode> | EJECT | ERROR <msg>
  -> RetroBoxDaemon (RetroBox.Daemon)
  -> RetroBoxFloppyControlClient (RetroBox.Core)
  -> 86Box floppy control socket (JSON Lines over Unix socket)
```

When a VM starts, the daemon re-syncs the drive: it asks the firmware for the
current physical floppy (`STATUS` over serial) and applies it as soon as the
86Box socket is ready, so swaps made while the VM was off are loaded on power-on.

## Components

### src/RetroBox.Core (domain)

Flat, file-per-concern `RetroBox*` classes. No external dependencies except
YamlDotNet.

- `RetroBoxConfigStore` — reads/writes `config.yaml`, `vms.yaml`,
  `floppies.yaml`, and `games.yaml` under the catalog root (default
  `/data/retrobox`), with
  validation and backup-then-restore on failed saves.
- `RetroBoxCatalogModels` / `RetroBoxCatalogValidation` / `RetroBoxCatalogRules`
  — YAML data shapes and ID/mode/size validation rules.
- `RetroBoxBoot` / `RetroBoxBootSelector` / `RetroBoxBootHotkey` — resolve and
  launch the target VM; detect the F12 boot-window hotkey.
- `RetroBoxFloppyControlClient` / `RetroBoxEchoTransportStream` — client for the
  86Box floppy control socket; echo transport for `--echo`.
- `RetroBoxFloppyImporter` — moves scratch images into the catalog and updates
  `floppies.yaml`.
- `RetroBoxArduinoSerialProtocol` — parses `INSERT`/`EJECT`/`ERROR`/`INIT` and
  builds host commands (`WRITE`, `TAGID`, `PING`, `STATUS`); parses controller
  replies (`OK`, `PONG`, `Tag ID: <uid>`, `ERROR <msg>`).
- `RetroBoxNfcClient` / `RetroBoxNfcWriter` — `PING`/`PONG` connectivity and
  tag writing for a cataloged floppy.
- `RetroBoxVmSelection` — list VMs, get/set the default VM.

### src/RetroBox.Cli

System.CommandLine root command (`Program.cs` → `CliCommandFactory.cs`).
Subcommands: `boot`, `daemon`, `vm`, `floppy`, `import`, `nfc`. The factory
accepts injected runners/UIs so tests can drive commands in-process.

### src/RetroBox.Daemon

`RetroBoxDaemon` runs the event loop: it opens the serial device
(`RetroBoxSerialDeviceRunner`), watches the floppy controller, probes for the
86Box socket (`RetroBoxVmSocketProbe`), and applies floppy events through
`RetroBoxFloppyEventHandler`. Since a command reply and a floppy event can
arrive on the same serial line in either order, `RetroBoxSerialLineRouter`
splits the two apart; `RetroBoxSerialNfcCommandChannel` sits on top of it to
serialize controller commands (`WRITE`/`TAGID`/`STATUS`) behind a timeout, so
every caller on the one physical line — today the socket-poll loop, later a
web layer writing tags — shares one gate instead of racing each other on the
wire. `RetroBoxDriveStateTracker` tracks what is currently in the drive from
the events it observes.

### src/RetroBox.Web

The daemon hosts a floppy management panel (Minimal API with embedded static
assets, preserved in the AOT single-file binary) on the port specified by
`WEB_PORT` (default 8080), listening on every interface. It is hosted inside the
daemon process because the daemon owns the serial port exclusively. The panel
runs without a floppy controller attached, allowing catalog management with no
hardware dependencies. It is **unauthenticated and openly writable**: anyone on
the LAN can list, upload, rename, re-mode, and delete floppies, and create,
edit, or delete game groups. Authentication and TLS are explicitly out of
scope, consistent with the appliance being a LAN-trusted device and
the principle that the appliance is a LAN-trusted device.

Uploads always land untagged (`nfc: false`), and the daemon refuses to mount an
untagged floppy, so a floppy uploaded through the panel is listed but cannot be
inserted until a tag is written for it. The panel marks those with a "No NFC"
badge carrying that explanation; assigning one means putting the disk in the
drive and using the panel's drive section, which reads the tag through
`GET /api/drive`/`/api/drive/events` and writes it through `POST /api/nfc/write`
over the same serial connection the daemon already holds — no stopping the
service.

The panel uses `RetroBoxWatchingCatalogSource` to keep its catalog in sync with
the daemon: edits from the panel or over
SSH are picked up without restarting. A malformed catalog file at startup no
longer blocks the daemon — it starts with an empty catalog and reports the
validation error, allowing the panel to fix it. A catalog reload that fails
validation during runtime is discarded, leaving the daemon running with the
previous valid state.

### firmware/retrofloppy-esp8266

ESP8266 (NodeMCU v2) Arduino firmware. Talks to a PN532 over I2C (address
`0x24`), detects disk presence by polling the PN532 for the tag itself (no
mechanical switch), and reports events over 115200 baud serial. NFC tags carry raw `<id>,<mode>` bytes in pages
4–11 (32 bytes max), deliberately not NDEF. Vendored PN532 libraries are pinned
in `sketch.yaml`. See the
[firmware README](../firmware/retrofloppy-esp8266/README.md) and
[floppy controller wiring](floppy-controller-wiring.md).

### appliance/

Debian 13 base layout: read-only root, persistent `/data` for VMs, floppies,
catalogs, and snapshots; a single `retrobox` account (root locked, `sudo`
available. The bootable USB installer builds
a live installer rootfs plus the target appliance rootfs and installs offline.
See [`appliance/README.md`](../appliance/README.md) and
[`appliance/installer/README.md`](../appliance/installer/README.md).

## Key contracts

| Contract | Where | Notes |
| --- | --- | --- |
| Arduino serial protocol | `RetroBoxArduinoSerialProtocol` | `INIT`, `INSERT <id>,<mode>`, `EJECT`, `ERROR`; host `WRITE`/`TAGID`/`STATUS`/`PING`. |
| 86Box floppy control socket | `docs/86box-floppy-control-socket-contract.md` | JSON Lines over Unix socket; `floppy.insert/eject/status`. |
| VM hardware source of truth | `docs/vm-profiles.md` | The 86Box `.cfg` defines hardware; YAML is metadata only. |
| CD-ROM passthrough | `docs/cdrom-passthrough.md` | First active optical slot bound to `ioctl://<device>` at install. |

## Data model

The catalog is YAML metadata; it never duplicates emulator hardware state.

```yaml
# config.yaml
defaultVm: pentium100
floppyControlSocketPath: /run/retrobox/86box-floppy.sock
serialPort: /dev/ttyUSB0
serialBaud: 115200
```

```yaml
# vms.yaml
vms:
  pentium100:
    label: "Pentium 100"
    path: "/data/vms/pentium100"
```

```yaml
# floppies.yaml
floppies:
  monkey1-disk1:
    label: "Monkey Island 1 (disk 1)"
    image: /data/floppies/cataloged/monkey1-disk1.img
    mode: ro
    size: 3.5-1.44M
    nfc: true
```

```yaml
# games.yaml
games:
  monkey-island:
    label: "Monkey Island"
    floppyIds:
      - monkey1-disk1
```

`games.yaml` is optional; an absent file means there are no groups. A game
contains display metadata and an ordered list of floppy IDs. Each referenced
floppy must exist and may belong to only one game; floppies may remain
ungrouped. Covers and ScreenScraper IDs are metadata only in this phase and are
not served or validated. Deleting a game also removes its floppy entries and then attempts to
remove their image files. The catalog is saved first, so an image-cleanup failure leaves only an
orphaned file and does not fail the delete.

The panel exposes `GET /api/catalog`, which returns each game with its floppy
views and a separate `ungroupedFloppies` list. `POST /api/games` creates a game
from `{ id, label }`; `PATCH /api/games/{id}` replaces its label and/or complete
floppy membership with `{ label, floppyIds }`; `DELETE /api/games/{id}` removes
the group and its floppies. Game mutations save the catalog atomically and reload the
watching source before the next catalog response.

The `nfc` field tracks whether a physical NFC tag has been assigned to this floppy. When `true`, the daemon accepts inserts for this floppy ID. When `false`, the daemon refuses any insert attempt (without touching the 86Box socket) because no tag has been written for this catalog entry yet. Assign one by putting the floppy in the drive and using the web panel's drive section, which writes the tag over serial.

## Deployment model

- The `retrobox` binary is published as a **Native AOT Linux x64** single file
  (`mise run publish-linux-x64`) and installed at `/opt/retrobox/retrobox`.
- 86Box runs as `/opt/86Box/86box.AppImage` with ROMs in `/opt/86Box/roms`.
- Systemd units under `appliance/installer/payload/units/` supervise boot and
  the daemon; the daemon runs whether or not the floppy controller is attached,
  serving the LAN panel in either case.
- Root filesystem is read-only; `/data` is the persistent, writable partition.

## Releases

The USB installer workflow tags releases `appliance-YYYYMMDD-<run>` and
generates release notes from `git log --no-merges <previous-tag>..HEAD`, grouped
by conventional-commit type. See `CONTRIBUTING.md` and the release job in
`.github/workflows/build-usb-installer.yml`.

## Architectural decisions

Recorded in [`docs/decisions/`](decisions/README.md). Notable entries:

- `0001` — publish the CLI as a single Native AOT binary.
- `0002` — appliance uses a read-only root with persistent `/data`.
- `0003` — the 86Box `.cfg` is the hardware source of truth; YAML is metadata.
- `0004` — NFC tags carry raw bytes, not NDEF.
- `0005` — appliance supports WiFi via `wpa_supplicant` + systemd-networkd (DHCP) and a first-boot dialog.

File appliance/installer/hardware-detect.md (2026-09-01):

# Hardware detection contract

The installer detects appliance-specific hardware while installing to the target
disk and records what it found (or did not find) in the install report at
`/data/retrobox/install-report.txt`. Detection never aborts the install: when a
device is absent, the installer writes a clearly marked placeholder and a
`status=NOT_DETECTED` line so a technician can fix it later without reinstalling.

Implemented by [`lib/hardware-detect.sh`](lib/hardware-detect.sh).

## Target disks

- Enumerated with `lsblk -J -o NAME,TYPE,SIZE,MODEL,TRAN` (type `disk` only).
- The live USB installer device is **excluded by default** — its parent block
  device is resolved from the live medium mount (`/run/live/medium`) and removed
  from the candidate list. See [`lib/disk-select.sh`](lib/disk-select.sh).
- Removable/USB-transport disks are de-prioritised but still listed, so an
  install to a USB SSD is possible with explicit confirmation.
- The chosen disk is referenced by `/dev/disk/by-id/*` where available and by
  filesystem **UUID** in `/etc/fstab` — never by a transient `/dev/sdX` name.

## CD-ROM

Probed in this order; the first stable match wins:

1. `/dev/disk/by-id/*` entries whose name contains `cd`/`dvd` (preferred, stable).
2. `/dev/sr0`.
3. `/dev/cdrom` symlink.

When a drive is detected, the installer updates every installed
`/data/vms/**/86box.cfg` that has an active optical slot. It selects the
lowest-numbered enabled `cdrom_XX_parameters` entry whose bus is not `none`,
then writes `cdrom_XX_image_path = ioctl://<detected-device>`. Other optical
slots are left untouched. A malformed or unreadable profile is warned about and
skipped without failing installation.

When no drive is found, installed profiles are unchanged. `/dev/sr0` remains
only the diagnostic placeholder in `hardware.env` and the install report;
it is never written into a profile. Payload profile templates are likewise
host-neutral. Follow [the physical CD-ROM validation procedure](../../docs/cdrom-passthrough.md)
on the target appliance.

## ESP8266 / NodeMCU floppy controller (serial)

Probed in this order:

1. `/dev/serial/by-id/*` (preferred, stable across reboots and USB ports).
2. Fallback: `/dev/ttyUSB*` then `/dev/ttyACM*` — **only** used when no
   `by-id` link exists, and recorded as a fallback in the report because these
   names are not stable.

The resolved path and baud rate are written to the RetroBox daemon config. When
no serial device is present the daemon config keeps a placeholder
(`serial_device=/dev/ttyUSB0`, `baud=115200`) and the report records
`serial.status=NOT_DETECTED`. Electronics validation is out of scope (tracked in
#22 / #35); the installer only records/consumes the path and baud.

## HDMI audio

Audio is configured at boot by `retrobox-audio-setup.service`, after the
runtime ALSA devices and connected HDMI endpoints are available. The installer
does not detect or configure audio.

## Install report format

`/data/retrobox/install-report.txt` is a simple `key=value` text file, for
example:

```text
generated=install-retropc.sh
target.disk=/dev/sda
target.disk.by_id=/dev/disk/by-id/ata-CT500MX500SSD1_...
target.root.uuid=...
target.data.uuid=...
cdrom.device=/dev/sr0
cdrom.status=DETECTED
serial.device=/dev/serial/by-id/usb-1a86_USB_Serial-if00-port0
serial.baud=115200
serial.status=DETECTED
retrobox.binary=installed
box86.appimage=installed
```

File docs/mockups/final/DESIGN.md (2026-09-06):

# RetroBox mockup visual reference

This document applies only to `docs/mockups/final`. The approved Windows 3.1 mockups are the visual authority for this artifact. The repository-root `DESIGN.md` describes the existing dark frontend and must not override this mockup's explicitly confirmed appearance.

The surface is an operational desktop utility: compact task controls, readable tables, an observable running-VM state, and dialogs for edits and confirmations. Preserve the user's existing Windows 3.1 composition when migrating to React.

| Element | Implementation |
| --- | --- |
| Desktop | Teal `#008080`, 18px outside the main window. |
| Window and controls | Gray `#c0c0c0`, rectangular, white top/left bevels and black or gray bottom/right bevels. |
| Title bars | Navy `#000080`, white text, compact close button on dialogs. |
| Content | White inset scrolling workspace; gray game/VM groups and white data rows. |
| Tables | Collapsed 1px gray `#808080` borders on every cell; gray headers. |
| Typography | MS Sans Serif / Tahoma / Geneva / sans-serif, 13px base; 15px item titles; 11–12px supporting information. |
| CFG editor | Courier New / monospace, 13px with 1.5 line height, preserved whitespace. |
| Status | Dark green `#006400` with white text for running; pale yellow `#fff0b3` and dark brown for missing NFC. Labels always explain state. |
| Navigation | Two rectangular section tabs; selected tab joins the gray workspace frame. |
| Dialogs | Native modal semantics with custom Windows-style chrome; vertical action column at right. |
| Focus | Black dotted outline; standard keyboard operation. |

The typographic cover samples use Georgia inside small bounded book-cover-shaped rectangles. They are placeholders marked “MUESTRA”, not branding or genuine cover artwork. Their navy, red, and gray backgrounds are limited to sample cover content. A user-selected local image replaces them.

Do not add mobile adaptations, rounded cards, gradients, power controls, hardware selectors, or a bulk-backup action. Running status is informational. Preserve full backup-table borders and independently editable VM names. All CSS lives in `styles.css`; dialogs and repeated data rows share that visual system.

Floppy names are editable through a dedicated rename dialog. The current write mode is a closed/open lock with hover/focus tooltip and accessible label. All disk action buttons are in the right-aligned Actions column. NFC values are centered synthetic Tag IDs for assigned disks. Action groups and table action headers align right. Trash and download controls use consistent 16px outlined SVG icons (trash can and floppy disk), with accessible labels and hover titles.

Game title buttons disclose the disk table and expose expanded state. The bottom paginator shows 10 games per page, current page, matching game count, and previous/next controls. Expand/collapse-all controls remain in the library toolbar.

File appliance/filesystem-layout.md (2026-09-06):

# Debian Appliance Filesystem Layout

## Mount and mutability model

The appliance is designed around a read-only root filesystem. The operating
system, installed packages, `/opt/retrobox/retrobox`, 86Box's AppImage, and
`/opt/86Box/roms` and `/opt/86Box/shaders` are part of the deployed system image
and are not application state.

`/data` is the persistent writable filesystem for Retro PC state:

```text
/data/
  retrobox/
    vms.yaml
    install-report.txt
  vms/
    386sx16/
      86box.cfg
      hdd.raw
    pentium100/
      86box.cfg
      hdd.raw
    pentium2-350/
      86box.cfg
      hdd.raw
      syncmaster3.edid
  floppies/
    scratch/
    cataloged/
  snapshots/
    386sx16/
    pentium100/
    pentium2-350/
  system/
    wifi.conf        # SSID/PSK from the WiFi first-boot prompt (root:root 0600)
    wifi-configured  # marker set after the first successful WiFi prompt
    var/             # overlay upperdir for /var
    .var.work/       # overlay workdir for /var
  swapfile        # disk swap backstop (see below)
```

`/data/retrobox/install-report.txt` is written by the USB installer and records
the detected target disk, CD-ROM, and ESP8266 serial device (or explicit
diagnostic placeholders when a device is absent). When a CD-ROM is detected,
the installer writes its `ioctl://` path only to the first active optical slot
of each applicable installed `/data/vms/*/86box.cfg`; it leaves profiles
unchanged when no drive is found.

`/data/system/` holds the writable overlay upperdirs that make a read-only root
usable — see [Read-only root exceptions](#read-only-root-exceptions). It is
system state produced by the installer and the running OS, not user-facing
application data, and network shares never expose it.

### WiFi credentials

`/data/system/wifi.conf` — plain-text `SSID=`/`PSK=` lines (root:root, 0600),
written by `retrobox-wifi-firstboot.service` on the first boot that detects a
`wl*` interface. `/data/system/wifi-configured` (0644) marks that the prompt has
run; removing it re-arms the prompt. The same unit materializes the
wpa_supplicant config, the transient `wpa-wifi.service`, and the networkd
config into `/run` every boot, so `/etc` is never written at runtime.

The current `retrobox` code uses these paths directly:

- `/data/retrobox` is the YAML catalog root.
- `/data/floppies/scratch` is the import source directory.
- `/data/floppies/cataloged` stores imported floppy images.
- VM paths are under `/data/vms`.
- The immutable runtime is `/opt/retrobox/retrobox`, `/opt/86Box/86box.AppImage`,
  `/opt/86Box/roms`, and `/opt/86Box/shaders`.
- `config.yaml` is optional runtime state. The installer seeds only `vms.yaml`
  and does not choose a default VM.

The directories may be created during appliance provisioning. The `retrobox`
system user/group should own `/data/retrobox` and the cataloged application
state. Network users do not receive write access to appliance data;
network users must not be granted write access to catalogs, VM disks, or
snapshots.

## Read-only root exceptions

The following paths are runtime locations and must not be treated as persistent
application storage:

```text
/run/retrobox/86box-floppy.sock
/run/systemd/network/30-wifi.network
/run/
/tmp/
/var/log/
/var/lib/
```

The USB installer implements this contract as follows:

- `/` is mounted `ro,errors=remount-ro`.
- `/tmp` is `tmpfs` (volatile).
- `/var` is an `overlay` mount whose writable upperdir lives under
  `/data/system/var` (see the `/data` tree above), so logs, DHCP
  leases, and ALSA state persist across reboots without a writable root.
- `/etc` stays **read-only**. The few files that must exist per machine — the
  SSH host keys and the machine-id — are generated into the image at install
  time. Maintenance edits use `sudo mount -o remount,rw /`.
- Swap for the low-RAM machine: **zram** (compressed RAM swap, preferred) plus a
  modest **`/data/swapfile`** as a lower-priority OOM backstop. The root stays
  read-only; the swapfile lives on writable `/data`.

`/etc` is deliberately **not** an fstab overlay: `/etc` is read during early
boot, before an fstab-mounted overlay could apply, which would split-brain the
config (early boot sees the read-only layer, later reads see the overlay). Doing
an `/etc` (or whole-root) overlay correctly means assembling it in the initramfs
before `switch_root` — the immutable squashfs-root approach tracked in #43 (and
the read-only-root prototype #30). Until then the appliance must always keep
`/data` writable and the OS image root effectively read-only.

The following system areas remain read-only after deployment unless a future
maintenance workflow deliberately remounts or replaces the system image:

```text
/
/usr/
/bin/
/sbin/
/lib/
/opt/
```

`/etc` contains installed system configuration and should be treated as image
configuration for this stage. Any future changes required while the root is
read-only must be represented by the image build or an explicitly documented
overlay; they must not be silently written into `/data` without defining the
corresponding contract.

## Runtime ownership and access

The eventual services should run with the least privilege compatible with the
hardware:

- `retrobox` owns and edits its YAML catalogs under `/data/retrobox`.
- `retrobox` reads VM and cataloged floppy assets under `/data` and belongs to
  Linux's `cdrom` group for physical optical-drive access.
- `retrobox` writes imported assets to `/data/floppies/cataloged` only through
  the import workflow.
- administrators use SSH and `sudo` for maintenance and diagnostics.
- the 86Box control socket is created at
  `/run/retrobox/86box-floppy.sock` by the eventual runtime service.

Audio, input, serial/USB, and graphics device access still depends on the
physical hardware and runtime integration. `cdrom` group membership is the
baseline for physical optical-drive access; add a device-specific rule only if
target validation proves it necessary.

## Backup boundary

Back up `/data` as application state. At minimum this includes the YAML files,
VM disks, cataloged floppy images, and snapshots. The immutable root image,
package manifest, and AppImage are deployment artifacts and should be
reproducible or copied separately from the mutable data backup.

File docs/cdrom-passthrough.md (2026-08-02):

# Physical CD-ROM passthrough validation

Use this procedure on the installed Linux appliance with the RetroBox 86Box
fork that supports Linux ioctl CD-ROM paths. The installer only writes a host
path after it detects a physical drive; the payload templates remain portable.

## Record the installed configuration

1. Read `/data/retrobox/install-report.txt` and record `cdrom.device` and
   `cdrom.status`. The status must be `DETECTED` for automatic configuration.
2. For each installed profile, inspect its optical entries:

   ```bash
   grep -H -E '^cdrom_[0-9][0-9]_(parameters|image_path) =' /data/vms/*/86box.cfg
   ```

   Confirm that only the first active slot (the lowest-numbered enabled slot
   whose bus is not `none`) has
   `cdrom_XX_image_path = ioctl://<cdrom.device>`. Profiles without an active
   optical slot and all later slots must be unchanged. With
   `cdrom.status=NOT_DETECTED`, no profile should gain an `ioctl://` path.

## Confirm permissions

The baseline is membership of the `retrobox` user in Linux's `cdrom` group:

```bash
id retrobox
getent group cdrom
ls -l "$(sed -n 's/^cdrom.device=//p' /data/retrobox/install-report.txt)"
```

Record the group membership and device owner/group/mode. If 86Box cannot open
the detected device despite that membership, capture the error and add the
narrowest device-specific udev or systemd permission rule that resolves it.
Record the rule's path and contents, reboot or reload it as appropriate, and
repeat every check below. Do not weaken permissions for unrelated block devices.

## Exercise real media

Use an existing DOS or Windows guest in an installed profile with the configured
drive.

1. Insert a known data CD, start 86Box, and verify that the guest can list and
   read a file from the CD. Record the guest, disc identification, command or
   application used, and result.
2. Boot or reset with no media inserted. Record the observed guest behavior
   (for example, no drive, empty drive, or a guest-visible read error).
3. While 86Box is running, eject the disc and insert a different data CD.
   Refresh or remount from the guest as required, then verify that the new
   disc is visible. Record whether the change was detected automatically and
   any guest action needed.

Keep the resulting evidence with the appliance test record: detected Linux
device, installed `ioctl://` configuration, permission result, inserted-disc
read result, no-media behavior, eject/change behavior, and any required narrow
udev/systemd rule.

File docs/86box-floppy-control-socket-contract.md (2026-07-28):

# 86Box Floppy Control Socket Contract

## Purpose

This document defines the first runtime control contract exposed by the Retro PC 86Box fork. The contract is intentionally narrow: it controls mounted floppy media for an already running 86Box process.

The supported commands are:

- `floppy.insert`
- `floppy.eject`
- `floppy.status`

The socket does not launch virtual machines, edit persistent emulator configuration, or create disk images.

## Socket Path

86Box creates one Unix stream socket per running VM process:

```text
/run/retrobox/86box-floppy.sock
```

Runtime rules:

- The parent directory is created by the service manager before 86Box starts.
- The socket is owned by the same runtime user that runs 86Box.
- The socket mode is `0600` unless the deployment explicitly grants access to a dedicated local control group.
- 86Box removes any stale socket at the same path immediately before binding.
- 86Box unlinks the socket during normal shutdown.
- If the socket cannot be created, 86Box may continue running, but control clients must treat the control interface as unavailable.

Only local Unix socket clients are supported. TCP is not part of this contract.

## Framing

The protocol uses JSON Lines over the Unix stream socket.

- Each request is one UTF-8 JSON object followed by `\n`.
- Each response is one UTF-8 JSON object followed by `\n`.
- Clients may keep a connection open for multiple sequential requests.
- Requests on a single connection are processed in received order.
- A request must fit in 64 KiB including the trailing newline.
- 86Box closes the client connection after a malformed JSON frame or an oversized frame.

## Request Format

Every request has this shape:

```json
{
  "id": "req-001",
  "command": "floppy.status",
  "params": {}
}
```

Fields:

- `id`: required string. It is opaque to 86Box and is echoed in the response.
- `command`: required string. It must be one of the supported command names.
- `params`: required object. Its schema depends on `command`.

Unknown top-level fields are ignored. Unknown fields inside `params` are ignored.

## Success Response Format

Every successful response has this shape:

```json
{
  "id": "req-001",
  "ok": true,
  "result": {}
}
```

Fields:

- `id`: copied from the request.
- `ok`: always `true`.
- `result`: command-specific object.

## Error Response Format

Every failed response has this shape:

```json
{
  "id": "req-001",
  "ok": false,
  "error": {
    "code": "invalid_drive",
    "message": "Drive must be an integer from 0 through 3.",
    "details": {
      "drive": 4
    }
  }
}
```

Fields:

- `id`: copied from the request when the request id can be parsed, otherwise `null`.
- `ok`: always `false`.
- `error.code`: stable machine-readable string.
- `error.message`: human-readable diagnostic text.
- `error.details`: optional object with non-sensitive diagnostic values.

## Drive Addressing

Drive numbers are zero-based and match 86Box's internal floppy drive array.

| Contract drive | 86Box drive |
| --- | --- |
| `0` | first floppy drive |
| `1` | second floppy drive |
| `2` | third floppy drive |
| `3` | fourth floppy drive |

Any other value returns `invalid_drive`.

## `floppy.insert`

Mounts a floppy image into one drive.

Request:

```json
{
  "id": "req-002",
  "command": "floppy.insert",
  "params": {
    "drive": 0,
    "path": "/data/floppies/disk-1.img",
    "read_only": true
  }
}
```

Parameters:

- `drive`: required integer from `0` through `3`.
- `path`: required absolute filesystem path visible to the 86Box process.
- `read_only`: optional boolean. Defaults to `false`.

Behavior:

- 86Box validates `drive` before touching emulator state.
- 86Box rejects an empty, relative, or missing `path`.
- 86Box rejects image formats that the configured floppy code cannot mount.
- 86Box rejects insertion while the target drive is actively transferring data.
- On success, 86Box closes any currently mounted image in that drive, applies the requested write-protect state, loads the new image, marks the drive as changed, and reports the resulting status.
- This command affects runtime state. Persistence to the VM configuration file is implementation-defined and must not be required by clients.

Success response:

```json
{
  "id": "req-002",
  "ok": true,
  "result": {
    "drive": 0,
    "inserted": true,
    "path": "/data/floppies/disk-1.img",
    "read_only": true,
    "busy": false,
    "changed": true
  }
}
```

## `floppy.eject`

Ejects any mounted image from one drive.

Request:

```json
{
  "id": "req-003",
  "command": "floppy.eject",
  "params": {
    "drive": 0
  }
}
```

Parameters:

- `drive`: required integer from `0` through `3`.

Behavior:

- 86Box validates `drive` before touching emulator state.
- 86Box rejects eject while the target drive is actively transferring data.
- Ejecting an already empty drive is successful and idempotent.
- On success, 86Box closes the mounted image, clears the runtime path, marks the drive empty, and reports the resulting status.
- Pending image writeback must be completed before the command returns success. If writeback fails, the command returns `internal_failure`.

Success response:

```json
{
  "id": "req-003",
  "ok": true,
  "result": {
    "drive": 0,
    "inserted": false,
    "path": null,
    "read_only": false,
    "busy": false,
    "changed": true
  }
}
```

## `floppy.status`

Reports runtime floppy state.

Request for one drive:

```json
{
  "id": "req-004",
  "command": "floppy.status",
  "params": {
    "drive": 0
  }
}
```

Request for all drives:

```json
{
  "id": "req-005",
  "command": "floppy.status",
  "params": {}
}
```

Parameters:

- `drive`: optional integer from `0` through `3`. When omitted, all drives are returned.

Success response for one drive:

```json
{
  "id": "req-004",
  "ok": true,
  "result": {
    "drive": 0,
    "inserted": true,
    "path": "/data/floppies/disk-1.img",
    "read_only": true,
    "busy": false,
    "changed": false
  }
}
```

Success response for all drives:

```json
{
  "id": "req-005",
  "ok": true,
  "result": {
    "drives": [
      {
        "drive": 0,
        "inserted": true,
        "path": "/data/floppies/disk-1.img",
        "read_only": true,
        "busy": false,
        "changed": false
      },
      {
        "drive": 1,
        "inserted": false,
        "path": null,
        "read_only": false,
        "busy": false,
        "changed": false
      }
    ]
  }
}
```

Status fields:

- `drive`: zero-based drive number.
- `inserted`: `true` when a runtime image path is mounted.
- `path`: mounted image path, or `null` when the drive is empty.
- `read_only`: current runtime write-protect state.
- `busy`: `true` when the drive is actively reading, writing, formatting, seeking, or flushing image state.
- `changed`: current runtime disk-change flag as observed by the emulator.

## Error Codes

| Code | Commands | Meaning |
| --- | --- | --- |
| `missing_image` | `floppy.insert` | The requested image path is empty, relative, does not exist, is not readable by 86Box, or cannot be opened. |
| `busy_drive` | `floppy.insert`, `floppy.eject` | The target drive is actively transferring data or flushing image state, so media cannot be changed safely. |
| `invalid_drive` | all commands | The drive parameter is missing, not an integer, or outside `0..3`. |
| `unsupported_mode` | `floppy.insert` | The requested image cannot be mounted by the configured floppy image loaders, or the request asks for an unsupported access mode. |
| `internal_failure` | all commands | 86Box encountered an unexpected runtime failure after the request passed validation. |

Malformed JSON, missing `command`, unknown `command`, missing `params`, or invalid parameter types also return `internal_failure` unless a more specific code above applies.

## Read-Only Behavior

`read_only` controls the runtime write-protect state requested for the mounted image.

Rules:

- `read_only: true` means guest writes to the mounted image must be rejected through the emulator's floppy write-protect path.
- `read_only: false` means guest writes may be allowed when the image format and host file permissions allow writes.
- If the host file or image format is read-only, 86Box may report `read_only: true` even when the request used `read_only: false`.
- `floppy.status` reports the effective runtime state, not merely the last requested value.
- Ejecting a drive clears the requested runtime write-protect state for that drive.

The contract does not guarantee copy-on-write snapshots. Clients that need image preservation must request `read_only: true`.

## 86Box Implementation Notes

The contract maps onto existing 86Box floppy runtime concepts:

- 86Box exposes four floppy slots through `FDD_NUM`.
- Runtime image paths are held in `floppyfns`.
- The user-requested write-protect state is represented by `ui_writeprot`.
- Effective image write-protect state is represented by `writeprot` and `fwriteprot`.
- Empty state is represented by `drive_empty` and an empty runtime path.
- Existing frontends mount media by closing the current image, setting write-protect intent, then calling `fdd_load`.
- Existing frontends eject media by calling `fdd_close`.

The socket implementation should use the same main-thread or emulator-thread serialization rules as existing media UI actions. It must not mutate floppy state concurrently with active floppy operations.

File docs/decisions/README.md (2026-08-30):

# Architecture Decision Records

Substantial design decisions are recorded here as ADRs so that future agents
and maintainers can reconstruct *why* the code works the way it does.

## Conventions

- One file per decision: `NNNN-slug.md`, where `NNNN` is the next free
  four-digit number starting at `0001`.
- Keep each ADR short: context, decision, and consequences. Status is one of
  `Accepted`, `Superseded by NNNN`, `Proposed`, or `Deprecated`.
- When a new decision changes behavior that agents should understand, add it
  here and link it from `AGENTS.md` / `docs/architecture.md`.

## Index

- [0001-native-aot-binary.md](0001-native-aot-binary.md) — single Native AOT Linux binary.
- [0002-read-only-root-and-data.md](0002-read-only-root-and-data.md) — read-only root, persistent `/data`.
- [0003-yaml-metadata-not-source-of-truth.md](0003-yaml-metadata-not-source-of-truth.md) — 86Box config is authoritative.
- [0004-nfc-raw-bytes-not-ndef.md](0004-nfc-raw-bytes-not-ndef.md) — tags carry raw bytes.
- [0005-add-wifi-support.md](0005-add-wifi-support.md) — WiFi via systemd-networkd + first-boot dialog.
- [0007-uefi-boot.md](0007-uefi-boot.md) — UEFI GPT/ESP target with hybrid BIOS/UEFI installer image.

## Template

```markdown
# NNNN. Title

Date: YYYY-MM-DD
Status: Accepted

## Context

The problem or constraint that forced the decision.

## Decision

What was decided, in concrete terms.

## Consequences

Positive and negative outcomes, and anything this decision rules out.
```

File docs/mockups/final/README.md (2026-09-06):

# RetroBox desktop mockup

This folder is the consolidated UX reference for the future React / TypeScript / Vite application with routing and i18n. It combines the seven sibling HTML mockups, including their later fixes. It is a standalone, interactive prototype, not the production web application.

## Open and share

Open `index.html` in a current desktop browser. No installation, build, server, API, or network connection is required. Keep all four runtime files together:

| File | Responsibility |
| --- | --- |
| `index.html` | Application shell, navigation, forms, and dialogs. |
| `styles.css` | Windows 3.1 visual tokens, layouts, tables, controls, and states. |
| `data.js` | Disposable game, floppy, VM, backup, and settings fixtures. |
| `app.js` | In-memory state, list rendering, navigation, and simulated interactions. |

Give the next agent this entire folder, including this README and `DESIGN.md`. The original mockups remain alongside it for provenance. All presentation rules are in CSS; there are no inline styles or inline event handlers. Dynamic list HTML is rendered by JavaScript; it is not a React component implementation.

## Confirmed scope

- Desktop only, with a Windows 3.1 gray window, navy title bars, teal desktop, beveled controls, and bordered tables. The application name is **RetroBox**.
- Two main sections: floppy/game library and virtual machines. Settings and individual operations use dialogs, matching the original mockups.
- Create a VM by entering its name and pasting an existing `86box.cfg`. There are no hardware selectors or generated hardware configurations.
- Edit a VM's name and CFG without recreating it. The stable ID, execution indicator, and backups survive a rename.
- Show which VM is running, if any. No power controls and no bulk backup action.
- Manage backups individually for each VM: list, create, download, and delete. Restore was not part of the supplied flow.
- Settings include Spanish/English selection and the existing ScreenScraper developer/user configuration. No COM port or WebNFC settings.
- Actions are simulated. Changes last only until reload. Translation behavior is intentionally omitted; all UI copy remains Spanish even when English is selected.

## Source reconciliation

| Original mockup | Included in this consolidation |
| --- | --- |
| `initial-mockup.html` | Grouped floppy tables, upload, read/write mode, NFC, disk deletion, adding disks. |
| `settings-dialog-addition.html` | Application menu and settings dialog; serial settings replaced with the existing ScreenScraper settings per user direction. |
| `cover-art-view.html` | Cover thumbnail, local image selection, search, preview, selection, accept/cancel. |
| `vms-tab-addition.html` | Main section navigation and VM execution status. Hardware selectors, power actions, and bulk backups explicitly excluded. |
| `vms-tab-creation-fix.html` | Name plus pasted CFG creation workflow. |
| `vms-backup-administration-fix.html` | CFG editing and per-VM backup administration. |
| `fix-backup-tables-borders.html` | Full table borders, including backup headers and cells. |

The name-editing workflow is the additional feature requested for this consolidation.

## UX walkthrough

1. **Library:** search by game or floppy filename. The matching game remains visible with its disks for context. “Modo actual” shows a closed/open lock with an accessible label and hover/focus tooltip for read-only/read-write. All disk buttons live in Actions: change mode, write NFC, rename, and delete. “Renombrar…” changes the display name while retaining the stable disk ID, mode, and NFC association. This does not rename an image file on disk. Delete asks for confirmation; deleting the last disk keeps the group with an empty-state message.
2. **Upload:** choose “Subir disquetes…”, enter a game/software name, choose one or more `.img`, `.ima`, or `.dsk` files, and confirm. Files create a new group. “Agregar disco…” attaches files to an existing group. New disks start read/write and without an NFC assignment, consistent with the supplied mocks.
3. **NFC:** choose “Escribir NFC…”, simulate disk detection, then write. Writing stays disabled until detection. The centered NFC column shows a synthetic Tag ID for assigned disks and “Sin NFC” otherwise. Tag IDs are demo fixtures, not readings from physical hardware. No actual serial or NFC operation occurs.
4. **Covers:** open “Carátula…”, choose a local PNG/JPEG/WebP or run a simulated search, select a result, and accept. Cancel/Escape discards the draft. Local images remain in browser memory. Typographic cover samples are deliberate offline placeholders, not real artwork or scraper results.
5. **VM creation:** switch to VMs, choose “Crear VM…”, supply a nonempty name and CFG, and create. The mockup checks required text only; it does not validate 86Box syntax or allocate disks.
6. **VM editing:** choose “Editar nombre / CFG…”. Change either field, then save or cancel. Editing the name preserves the VM's ID and backup list. CFG fixture contents are illustrative, not guaranteed bootable 86Box profiles.
7. **Backups:** choose “Administrar backups…”. An empty VM has an explicit empty state. “Crear backup…” opens an inline workflow dialog for a label; its confirmation inserts a synthetic timestamp and size. The floppy-disk icon downloads; trash icons delete. Icon buttons have accessible labels and hover titles, and action groups align right. Download creates a clearly named `*-DEMO.txt` receipt, not a backup archive. Deletion requires confirmation and affects only that VM's demo list.
8. **Settings:** open “Opciones…”. Use dummy developer ID/password and ScreenScraper ID/password. “Probar credenciales” checks that all four fields are populated, then reports simulated success. Region and metadata-language arrows reorder priorities. Accept retains settings for the page session; Cancel/Escape discards edits.

Navigation uses `#/floppies` and `#/vms`, including browser back/forward. The initial view is the library. Dialogs use native `showModal()` for keyboard containment and Escape behavior. Confirmation dialogs initially focus Cancel. Data is escaped before insertion into dynamic HTML.

## Production handoff

Preserve the visual flows, but replace the demo store and DOM rendering with typed React components and real services. Suggested component boundaries are `AppShell`, `LibraryPage`, `GameGroup`, `FloppyTable`, `VmPage`, `VmEditorDialog`, `VmBackupsDialog`, `CoverDialog`, `NfcWriteDialog`, `SettingsDialog`, and `ConfirmDialog`. These are organizational suggestions, not committed architecture or a mandated router library.

Use stable entity IDs as route parameters and React keys; labels must be independently editable. Keep form drafts separate from persisted state. Map the two section URLs to the selected router; decide dialog URL behavior during implementation. Do not copy global active IDs, event delegation, HTML strings, or fixture-only state flags into production architecture.

For i18n, move static labels, notifications, validation errors, accessible names, counts, and dialog titles into message catalogs. Use interpolation, plural rules, and locale-aware date/number formatting. Maintain an extensible UI locale registry starting with `es` and `en`. UI language and ScreenScraper metadata language priority are separate concepts. Do not translate filenames, VM IDs, user-entered names, or CFG contents. No i18n library is selected by this mockup.

### Existing repository integration points

Check the actual contracts before implementation; this prototype calls none of these endpoints.

| Concern | Existing source / route |
| --- | --- |
| Catalog | `src/RetroBox.Web/RetroBoxCatalogEndpoints.cs`, `GET /api/catalog`. |
| Game groups | `RetroBoxGameEndpoints.cs`: `POST /api/games`, `PATCH` / `DELETE /api/games/{id}`. |
| Floppies | `RetroBoxLibraryEndpoints.cs`: `POST /api/floppies`, `PATCH` / `DELETE /api/floppies/{id}`. |
| Physical disk state | `RetroBoxDriveEndpoints.cs`: `GET /api/drive`, drive events. |
| NFC write | `RetroBoxNfcEndpoints.cs`: `POST /api/nfc/write`. |
| Cover selection/upload | `RetroBoxCoverEndpoints.cs`: `POST /api/games/{id}/cover` and `/cover/upload`. |
| Scraper | `RetroBoxScraperEndpoints.cs`: `GET` / `PUT /api/settings/scraper`, `POST /api/settings/scraper/test`, `GET /api/scraper/search?q=…`. |
| Current settings form | `src/RetroBox.Web/wwwroot/index.html`, `src/RetroBox.Web/wwwroot/app.js`. |
| Settings rules | `src/RetroBox.Core/RetroBoxScraperSettings.cs`. |

ScreenScraper field names match the current settings shape: `devId`, `devPassword`, `ssId`, `ssPassword`, `regionPriority`, `languagePriority`, `requestTimeoutSeconds`, and `maxDownloadMegabytes`. Initial region order is `sp, wor, eu, us`; metadata languages are `es, en`; timeout is 60 seconds (5–600); maximum download is 16 MB (1–64). Production credential test behavior must follow the real endpoint, which tests saved settings. The mockup tests the current form for flow demonstration only. Never prepopulate secrets by copying this fixture approach; respect the backend's credential-presence flags and update semantics.

The production catalog can include ungrouped disks even though the source mockups demonstrate game groups. Plan that real-data state during implementation. The production NFC contract stores `nfc` and `mode: ro|rw`; the demo's `tagged` and `readOnly` are presentation-only fixtures. Tags contain `<id>,<mode>` bytes; the displayed `tagId` represents the separate physical UID. The current catalog does not establish persistent per-floppy UID storage; confirm the backend contract for this display during implementation. A real mode change must follow the existing backend/hardware rules, rather than simply toggling this demo boolean.

VM/backups HTTP contracts are **not established by this mockup**. Before connecting them, confirm name-update semantics, CFG application timing for a running VM, backup consistency during execution, deletion behavior for a running VM and its backups, archive format, and progress/error reporting. The simulated operations do not settle these product/backend decisions. In particular, deleting a VM removes its synthetic backups here only to keep the disposable demo state coherent; it does not authorize that production deletion policy.

Refer to `docs/architecture.md`, `docs/vm-profiles.md`, and the root `AGENTS.md` for domain rules. The mockup does not change the appliance or its current frontend.

## Verification and limitations

The prototype targets desktop windows at least 1000 CSS pixels wide. The library scrolls inside the application window; large dialogs scroll when the viewport height is limited. No mobile layout is included.

Browser checks covered library/VM navigation, local floppy selection and upload into a new group, VM creation, rename with existing backups preserved, backup creation/deletion, NFC detection/write, simulated cover search/selection, and missing-credential feedback. JavaScript syntax and the repository's `mise run format-check` were checked. These are prototype checks, not evidence that the production API or 86Box integrations work.

No external image dependencies, web fonts, browser storage, network requests, React dependencies, or installed packages are needed. There is no connection failure simulator, real backup generation, hardware access, or actual translation. Reload restores the sample data.

## Large-library navigation

The library paginates by game (10 per page), never splitting a game's disks. Search filters the entire library before pagination and resets to page one. The last page and empty results clamp correctly; previous/next buttons disable at the boundaries. Twelve groups, including ten explicitly synthetic software samples, make the second page available immediately.

Click a game title to collapse/expand its disk table. Cover, title, disk count, and group actions stay visible. “Expandir todo” and “Colapsar todo” affect all games across pages. Individual collapse state survives page changes and searches for this session. Settings includes “Iniciar con los juegos colapsados”; changing it applies to the current library on Accept, while Cancel discards the draft. Groups start expanded. As with all mockup settings, reload resets the preference. Production should persist that UI preference separately from ScreenScraper settings.

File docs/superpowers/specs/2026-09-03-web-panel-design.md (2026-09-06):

# Web panel for floppy library and NFC assignment

Date: 2026-09-03
Status: Approved — ready for implementation planning

## Context

Today the only ways to get a floppy image onto the appliance are the Samba
scratch share plus `retrobox import` over SSH, and the only way to assign a
disk to a physical NFC floppy is `retrobox nfc write` on the console. Both
require a terminal on a machine whose primary display is occupied by a
fullscreen 86Box VM.

This spec designs a LAN-reachable web panel that manages the floppy library
(upload, delete, organize by game, fetch box art) and assigns cataloged
floppies to physical NFC tags.

### Constraints discovered during design

These are properties of the existing system that shape the design. Each one
was verified against the code, not assumed.

1. **The daemon owns the serial port exclusively.**
   `RetroBoxSerialDeviceRunner.OpenAsync` opens the `SerialPort`, and
   `retrobox nfc write` opens *the same port* through `RetroBoxNfcSerialClient`.
   With `retrobox-daemon.service` running, a second process cannot write tags.
   Anything that writes NFC must go through the daemon.

2. **Native AOT rules out Blazor and SignalR.**
   `mise run publish-linux-x64` uses `-p:PublishAot=true -warnaserror`.
   ASP.NET Core supports Minimal APIs under AOT; Blazor Server, Razor
   components, MVC and SignalR are not supported. See ADR
   [0001](../../decisions/0001-native-aot-binary.md).

3. **A missing file in the catalog bricks the boot path.**
   `RetroBoxConfigStore.Validate` throws when any floppy's `image` does not
   exist on disk, and `Load()` is called by both `retrobox daemon` and
   `retrobox boot`. Deleting an image before removing its catalog entry leaves
   the appliance unbootable except through the `retropc.norun=1` GRUB entry.

4. **The daemon's read loop cannot currently see command responses.**
   `RetroBoxDaemon.RunAsync` parses every incoming line with `ParseEvent`.
   `OK` and `PONG` are not valid events, so they raise
   `RetroBoxArduinoSerialProtocolException` and set `exitCode = 1`. Worse,
   `ERROR ` is a prefix for both an event and a response
   (`RetroBoxArduinoSerialProtocol.cs:47` and `:95`).

5. **`WRITE` produces no follow-up event.**
   The firmware answers `OK` or `ERROR not written`, then calls
   `refreshInsertedPayload()`, which updates a cached value and emits nothing
   (`RetroFloppyApp.cpp:96-105`). The daemon is not notified that the tag
   changed.

6. **A blank tag never produces an `INSERT` event.**
   `readTag` returns `READ_FAILED` for an unwritten tag, and the firmware
   settles into `UNREADABLE` state. Assigning a *new* floppy to a *new* tag —
   the primary use case — is therefore invisible to the event stream.

7. **`TAGID` does report the tag UID.**
   The verb is in the firmware parser table and answers `Tag ID: <HEXUID>`
   (uppercase hex, no separators) or `ERROR no-tag-detected`
   (`RetroFloppyCommandHandler.cpp:22-30`). `RetroBoxArduinoSerialProtocol`
   does not know this response yet.

8. **The appliance may have no internet.**
   WiFi is optional and configured on first boot. Anything fetched from the
   network must be cached locally, and the panel must be fully usable offline.

## Decisions

| # | Decision | Rationale |
| --- | --- | --- |
| D1 | The web panel is hosted **inside the daemon process** | Constraint 1: one owner of the serial port, no IPC to design |
| D2 | **Minimal API + embedded static HTML/JS**, no Blazor | Constraint 2: keeps the AOT pipeline and the single-binary deployment |
| D3 | The serial port becomes **optional** for the daemon | Without a floppy controller the panel must still work |
| D4 | Tag assignment writes the **catalog id**, not a UID lookup | Preserves the existing tag format; no firmware or protocol change to the payload |
| D5 | The **tag UID is recorded** in the catalog | Enables the "this tag is already assigned" warning |
| D6 | Cover art is **downloaded and cached**, never hotlinked | Constraint 8 |
| D7 | **No authentication.** The panel is LAN-trusted | Explicit owner decision; see Assumptions |
| D8 | Cover art may also be uploaded manually as JPG, PNG, or WebP | Keeps the panel useful when ScreenScraper has no matching cover |

## Non-goals

- Authentication, TLS, or user accounts (D7).
- Replacing the Samba scratch share. It keeps working unchanged.
- Managing VM profiles, CD-ROM passthrough, or boot configuration.
- Editing floppy image *contents*.
- Any change to the NFC tag payload format (see ADR
  [0004](../../decisions/0004-nfc-raw-bytes-not-ndef.md)).
- Automatic cover matching without user confirmation.
- Animated GIF cover uploads.

## Architecture

One process, three assemblies, with the dependency direction arranged so the
web layer never reaches the hardware:

```
RetroBox.Cli   (Microsoft.NET.Sdk + FrameworkReference Microsoft.AspNetCore.App)
  │   retrobox daemon --serial-port … --web-port 8080
  ├──► RetroBox.Web    (new)  ──► RetroBox.Core
  └──► RetroBox.Daemon        ──► RetroBox.Core
```

- **`RetroBox.Core`** gains the abstractions: `IRetroBoxDriveState` (what is in
  the drive right now) and `IRetroBoxNfcCommandChannel` (`ReadTagIdAsync`,
  `WriteTagAsync`).
- **`RetroBox.Daemon`** implements them. It remains the sole owner of the
  serial port.
- **`RetroBox.Web`** depends only on the abstractions. With no controller
  attached it receives a null implementation and the panel disables its NFC
  affordances.
- `Program.cs` wires the three together.

`RetroBox.Cli` keeps `Microsoft.NET.Sdk` and `IsAotCompatible`; it only adds
`<FrameworkReference Include="Microsoft.AspNetCore.App" />`.
`mise run publish-linux-x64` is unchanged.

`retrobox daemon` gains `--web-port`, defaulting to **8080**. `--web-port 0`
disables the panel entirely, which keeps the pre-existing headless behaviour
available. The listener binds to all interfaces: the panel is useless if it is
not reachable from a phone on the LAN.

### Static assets

`index.html`, `app.js` and `app.css` are **embedded resources** in
`RetroBox.Web`, served by dedicated endpoints. This preserves the
single-binary deployment at `/opt/retrobox/retrobox` and means the installer
copies no `wwwroot`.

The source mockup loads Tailwind from `cdn.tailwindcss.com` and falls back to
`via.placeholder.com` for missing covers. **Both are removed**: on an offline
appliance the panel would render unstyled with broken images. The styling is
reimplemented as hand-written CSS — it is a small palette and a grid, which
does not justify adding a Node build step to `mise.toml`.

### systemd

`appliance/installer/payload/units/retrobox-daemon.service` changes in two
places:

- Remove `ExecCondition=/bin/sh -c 'test -e "$SERIAL_DEVICE"'`. The unit must
  start without a floppy controller so the panel is reachable (D3).
- Add `--web-port` to `ExecStart`, sourced from `/etc/retrobox/daemon.env`.

**This paragraph originally claimed the optional-serial path needed no daemon
logic, on the grounds that `ResolveSerialDeviceOptions` returns `null` for a
blank port. That was false and it shipped a crash loop.** The installer never
writes a blank port: `appliance/installer/lib/hardware-detect.sh:130` writes
`SERIAL_DEVICE=/dev/ttyUSB0` with `SERIAL_STATUS=NOT_DETECTED` when nothing is
found. So removing `ExecCondition` made the daemon open a device that does not
exist, throw, and exit 1 — and because the serial open ran before the web host
started, the panel was never reached. `Restart=on-failure` turned that into an
indefinite loop. The blank-port path failed differently: systemd gives the unit
`/dev/null` on stdin, so the read loop hit EOF and the process exited 0, which
`Restart=on-failure` does not retry.

What the optional-serial path actually needs: start the web host **before**
opening the serial device, degrade a failed open to a warning rather than an
exit, keep the process alive while a host is running, and retry the open in the
background so a device that appears late — a boot-time USB enumeration race — or
one that is re-plugged is picked up without a restart.

## Serial line routing

Constraint 4 means the daemon's read loop must distinguish *events* from
*command responses*. A router is added inside the existing loop; no second
reader is opened on the port.

```
                  ┌─ command in flight? ──┐
line from serial ─┤                        │
                  │ OK / ERROR … / Tag ID: ┼──► response → TaskCompletionSource
                  │ INSERT / EJECT / INIT  ┼──► RetroBoxFloppyEventHandler
                  └────────────────────────┘
                     no command in flight:
                     every line goes to the handler (today's behaviour)
```

- A `SemaphoreSlim(1)` serializes commands. Only one is physically meaningful:
  there is one drive.
- A timeout (5 s) fails the pending command and releases the slot, so a wedged
  controller cannot hang an HTTP request forever.
- `INSERT` and `EJECT` are **never** diverted, even mid-command. The disk can
  be pulled at any moment.

### Protocol additions

`RetroBoxArduinoSerialProtocol` gains:

- `BuildTagIdCommand()` returning `TAGID`.
- `NfcResponse.TagId(string Uid)`, parsed from the `Tag ID: ` prefix.

The tag payload format is unchanged.

### Mounting after a write

Because the firmware emits nothing after `WRITE` (constraint 5), a successful
write is followed by `STATUS`. The firmware answers `INSERT <new payload>`,
which flows through the normal event path and mounts the newly assigned image
in 86Box. Assigning a tag from a phone leaves the disk mounted without
ejecting and reinserting it. This reuses the mechanism already present in
`RetroBoxDaemon.WatchSocketAsync`.

### Drive state for the UI

The daemon tracks the last `INSERT`/`EJECT` seen and exposes it through
`IRetroBoxDriveState`. Because a blank tag produces no event (constraint 6),
the panel additionally issues `TAGID` to detect a tag that is present but
carries no valid payload. The UI therefore distinguishes three states:

| State | Detected by | Panel shows |
| --- | --- | --- |
| Empty | `EJECT`, or `TAGID` → `ERROR no-tag-detected` | "No disk" |
| Known floppy | `INSERT <id>,<mode>` | The cataloged floppy |
| Unassigned tag | `TAGID` → UID, no valid payload | "Blank tag, ready to assign" |

State is published over SSE at `GET /api/drive/events`, with 2 s polling as a
fallback. SignalR is not an option (constraint 2).

## Data model

Three new files under `/data/retrobox/`. None is mandatory; an absent file
means empty, matching how `floppies.yaml` behaves today.

### `games.yaml`

```yaml
games:
  monkey-island:
    label: The Secret of Monkey Island
    cover: monkey-island.jpg      # relative to /data/retrobox/covers/
    screenScraperId: 12345        # re-fetch without searching again
    floppyIds: [mi-d1, mi-d2, mi-d3, mi-d4]
```

`RetroBoxGame` (currently dead code at `RetroBoxCatalogModels.cs:39`) is
activated with these changes:

- Add `Cover` and `ScreenScraperId`, both nullable.
- **Remove `DefaultVm`.** A VM is chosen at boot, not per disk. The property is
  read by nobody today.
- Change `init` accessors to `set` to match the other catalog records; the
  YamlDotNet static generator needs settable properties.
- Register `RetroBoxGame` and `RetroBoxGameCatalog` in `RetroBoxYamlContext`.
  Omitting this fails the AOT publish, which is the intended guard rail.

Validation rules, added to the existing `Validate`:

- Game id satisfies `RetroBoxCatalogRules.IsValidId`; label is non-empty.
- Every referenced `floppyId` exists in `floppies.yaml`.
- A floppy belongs to at most one game. Floppies in no game are valid and are
  grouped under "Ungrouped" in the UI.

**Covers are deliberately not validated.** A missing cover file renders a
placeholder. Validating it would give a decorative asset the power to throw
from `Load()` and take down both the daemon and `retrobox boot`
(constraint 3).

### `floppies.yaml`

One new field:

```yaml
floppies:
  mi-d1:
    label: Monkey Island - Disk 1
    image: /data/floppies/cataloged/mi-d1.img
    mode: ro
    nfc: true
    nfcUid: 04A13BFE      # new: UID of the physical tag
```

### `scraper.yaml` (mode 0600)

```yaml
devId: xxxx
devPassword: xxxx
ssId: xxxx
ssPassword: xxxx
regionPriority: [sp, wor, eu, us]
languagePriority: [es, en]
```

Credentials are **write-only over HTTP**: `GET /api/settings/scraper` returns
`{ "configured": true, "developerConfigured": true,
"userConfigured": true, "regionPriority": [...], "languagePriority": [...] }`
and never the secrets. It also returns `developerConfigured` and
`userConfigured` separately. The four credentials are required before search or
cover download is enabled. A `PUT` omits unchanged secret fields; an
explicitly empty secret clears it.

### Covers

Downloaded to `/data/retrobox/covers/<game-id>.<ext>`.

## HTTP API

| Method | Route | Purpose |
| --- | --- | --- |
| `GET` | `/api/catalog` | Games with their disks, ungrouped floppies, NFC flags |
| `GET` | `/api/drive/events` | SSE stream of drive state |
| `GET` | `/api/drive` | Current drive state (polling fallback) |
| `POST` | `/api/floppies` | Multipart upload |
| `PATCH` | `/api/floppies/{id}` | Label and `ro`/`rw` mode |
| `DELETE` | `/api/floppies/{id}` | Transactional delete |
| `POST` | `/api/nfc/write` | Write the seated tag |
| `POST` | `/api/games` | Create a game |
| `PATCH` | `/api/games/{id}` | Label and membership |
| `DELETE` | `/api/games/{id}` | Ungroup; does not delete floppies |
| `GET` | `/api/scraper/search?q=` | `jeuRecherche.php`, `systemeid=135` |
| `POST` | `/api/games/{id}/cover` | `jeuInfos.php` → download `box-2D` |
| `POST` | `/api/games/{id}/cover/upload` | Upload a local JPG, PNG, or WebP cover |
| `GET` `PUT` | `/api/settings/scraper` | Scraper settings, write-only secrets |
| `POST` | `/api/settings/scraper/test` | Credential check |

### Upload

The uploaded file is written to `/data/floppies/scratch/` and handed to
`RetroBoxFloppyImporter.Import(...)` unchanged — the same path the Samba share
already uses, including its move to `cataloged/` and its rollback on failure.

- Extension allowlist: `.img`, `.ima`, `.dsk`.
- Request size cap enforced by Kestrel.
- The catalog id is derived from the filename, slugified to satisfy
  `RetroBoxCatalogRules.IsValidId` (lowercase, digits, single hyphens), with a
  numeric suffix on collision.

### Delete — order is load-bearing

1. Remove the floppy from `games.yaml`.
2. Remove it from `floppies.yaml`.
3. `Save()` — which validates.
4. **Only then** delete the `.img`.

A failure at step 4 leaves an orphaned file: untidy but harmless. The reverse
order leaves `Validate` throwing on a nonexistent `image`, which stops both the
daemon and `retrobox boot` (constraint 3).

### Changing mode invalidates the tag

The tag stores `<id>,<mode>`. A floppy written as `ro` and later changed to
`rw` still mounts read-only until the tag is rewritten. A `PATCH` that changes
`mode` therefore sets `nfc: false` and clears `nfcUid`, and the UI marks the
floppy as needing a rewrite. Without this the panel would claim `rw` while the
VM behaves `ro`, with no visible cause.

### Writing a tag

`POST /api/nfc/write { floppyId, confirm? }`

1. `TAGID`. `ERROR no-tag-detected` → `409 no-tag-present`.
2. If the returned UID is already recorded on a **different** floppy → `409
   tag-already-assigned` with the current owner, unless `confirm: true`.
3. `WRITE <id>,<mode>` → expect `OK`.
4. Set `nfc: true` and `nfcUid` on the target floppy, and **clear `nfc` and
   `nfcUid` on the previous owner of that UID**. The tag is physical: once
   reassigned, the old floppy genuinely has no tag and the catalog must say so.
5. `STATUS`, which mounts the newly assigned image.

### Refusing to mount an unassigned floppy

A new guard in `RetroBoxFloppyEventHandler.HandleInsertAsync`, shaped like the
existing check that rejects an `rw` tag on an `ro` floppy:

```csharp
if (!floppy.Nfc) → Failed: "Floppy '<id>' has no assigned tag; rewrite it from the panel."
```

A tag claiming `mi-d1` while the catalog says `mi-d1` has no tag is a stale tag
from a floppy that was reassigned or deleted. Mounting it would mount a lie.

The guard checks `nfc` only, **not** `nfcUid`. `INSERT` events carry no UID
(constraint 7 — only `TAGID` reports it), and issuing a `TAGID` round trip on
every insertion would add serial traffic and latency to the hot path for a
case the `nfc` flag already covers. `nfcUid` is consulted at write time only.

### Cover lookup

Search is explicit and confirmed by the user; nothing is auto-matched. On
confirmation, `jeuInfos.php` returns the media list, and the `box-2D` entry is
chosen by walking `regionPriority`, then `languagePriority`, then falling back
to the first available. The image is downloaded and `screenScraperId` is
persisted so the cover can be re-fetched without searching again.

ScreenScraper requires `devid`/`devpassword` (a developer account requested
from their forum) and this panel requires `ssid`/`sspassword` as well before
enabling search or cover download. PC DOS is `systemeid=135`. Search results
without a usable `box-2D` image are filtered out before returning them to the
frontend.

### Manual cover upload

`POST /api/games/{id}/cover/upload` accepts a multipart image upload with a
`.jpg`, `.jpeg`, `.png`, or `.webp` extension and a bounded request size. The
server validates the image before replacing the existing cached cover. The
stored path remains `/data/retrobox/covers/<game-id>.<ext>`. A successful manual
upload clears `screenScraperId`, because the active cover no longer represents
the ScreenScraper result. The old cover is removed only after the catalog and
new file are safely in place; a failed upload leaves the existing cover
unchanged. Manual covers are not overwritten by later searches unless the user
explicitly confirms a new ScreenScraper cover.

## Localization

The panel ships in **Spanish (default) and English**. No dependencies: a
per-key JS dictionary, `data-i18n` attributes in the HTML, initial selection
from `navigator.language`, and a manual override persisted immediately in
`localStorage`. The language selector lives in a full-screen Settings view,
reachable through a gear button in the library and navigable back with a
“Volver” button. Settings also contains the ScreenScraper credentials and
priority lists. Secret fields are write-only: the API never returns their
values, and the frontend omits untouched secrets from updates.

API errors travel as **codes**, not prose — `no-tag-present`,
`tag-already-assigned`, `catalog-invalid`, `scraper-not-configured` — and the
frontend supplies the text. The backend keeps no message catalog.

## Error handling

Responses are flat JSON: `{ "code": "...", "message": "..." }`. Every DTO is
registered in a `JsonSerializerContext`; with `-warnaserror` the AOT publish
fails on any that is missed.

The case that matters most: **an invalid catalog must not take the panel down
with it.** `store.Load()` throws `RetroBoxCatalogException` on any
inconsistency. The web host starts regardless and serves a "catalog broken"
view carrying the validation message. Otherwise a malformed YAML leaves the
owner with neither the CLI nor the panel, and the only route back is the GRUB
recovery entry.

Other cases:

| Situation | Response |
| --- | --- |
| No scraper credentials | `409 scraper-not-configured` |
| No internet | Bounded timeout, never a hang |
| ScreenScraper quota exhausted | Surface the API's own message |
| Drive empty on write | `409 no-tag-present` |
| Controller not attached | NFC endpoints `503`, panel disables them |

## Testing

xUnit, TDD, no network and no hardware.

- **Line router** — `OK`/`ERROR` with and without a command in flight; an
  `INSERT` arriving mid-`WRITE`; the timeout path. Built on the existing
  `RetroBoxEchoTransportStream`.
- **`TAGID` parsing** — `Tag ID: 04A13BFE` and `ERROR no-tag-detected`.
- **Tag reassignment** — the previous owner is cleared; `confirm` is required.
- **Mount guard** — `nfc: false` refuses to mount.
- **Transactional delete** — a failure deleting the file leaves a consistent
  catalog, and no ordering leaves `Load()` throwing.
- **Mode change** — sets `nfc: false` and clears `nfcUid`.
- **Upload** — rejected extensions, id collisions, slugging of messy names.
- **Cover selection** — behind `IRetroBoxCoverSource` with a fake, asserting
  the `regionPriority`/`languagePriority` walk without touching the network.
- **Endpoints** — `WebApplicationFactory`.
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

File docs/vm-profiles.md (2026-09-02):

# VM Profiles

Retro PC VM profiles are native emulator profiles. For 86Box VMs, the 86Box
configuration file is the hardware source of truth. RetroBox YAML catalogs may
refer to a profile for display or selection, but YAML is metadata only and is
not required by 86Box.

The appliance installs the catalog at `/data/retrobox/vms.yaml` and profiles at
`/data/vms/<id>`. The catalog intentionally has no `defaultVm`; `retrobox boot`
selects a VM when needed. 86Box is launched with the selected profile as its
working directory, so relative disk paths remain valid; shader paths use the
absolute `/opt/86Box/shaders/crt/crt-easymode.glslp` form and monitor EDID (when
used) uses `/data/vms/<id>/syncmaster3.edid`.

## 386SX-16

Path: `profiles/386sx16`

This is the RTM modest DOS VM profile: a 386SX-16 class machine with a blank
54 MB hard disk and no installed operating system or bundled media.

Profile files:

- `86box.cfg`: native 86Box configuration.
- `hdd.raw`: blank disk (created dynamically from `hdd_01_parameters`).
- `README.md`: setup notes and hardware summary.
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

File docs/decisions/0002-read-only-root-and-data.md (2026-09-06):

# 0002. Read-only root with persistent /data

Date: 2026-07-28
Status: Accepted

## Context

The appliance should behave like an embedded console, not a general-purpose
Linux box. Users must not be able to break the base OS while playing, and
install-time configuration (SSH and users) should be reproducible across
reinstalls.
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

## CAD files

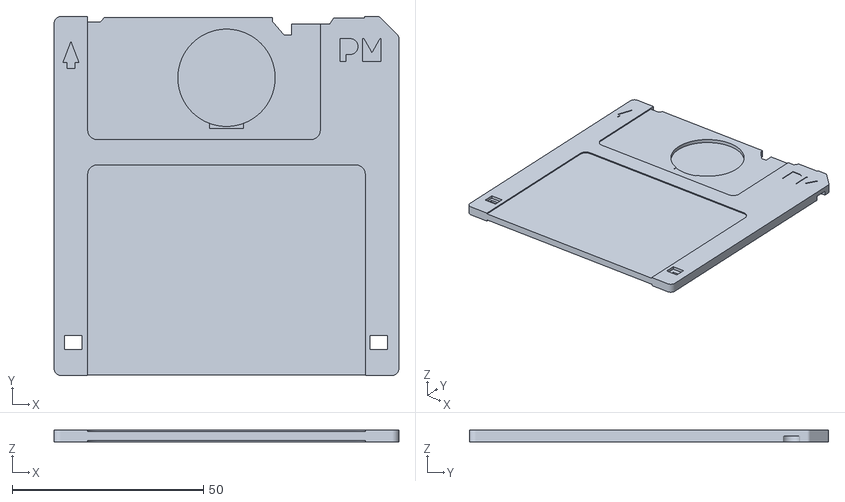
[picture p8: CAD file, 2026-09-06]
hardware/floppy-nfc-blank/floppy-nfc.stl
90.0 x 93.8 x 3.20

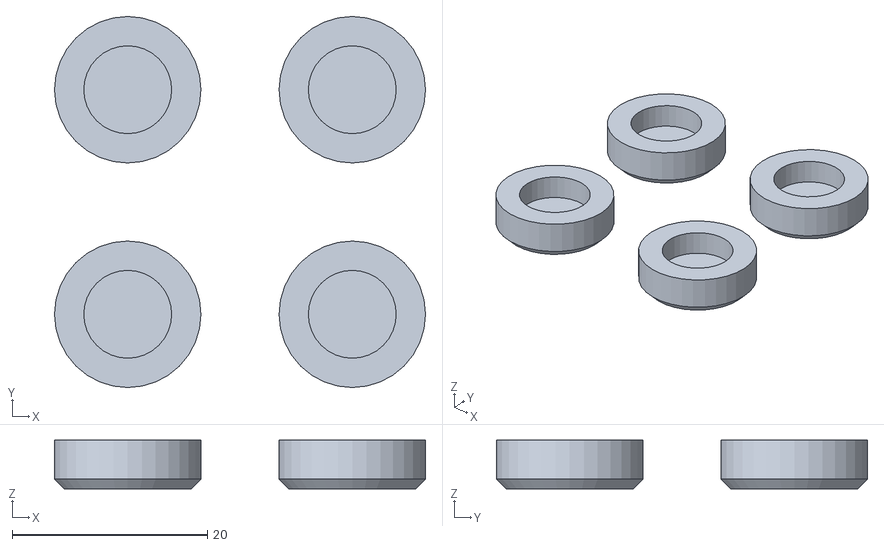
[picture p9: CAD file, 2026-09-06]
hardware/mac-classic-case/stl/tpu-feet.stl
38.0 x 38.0 x 5.00

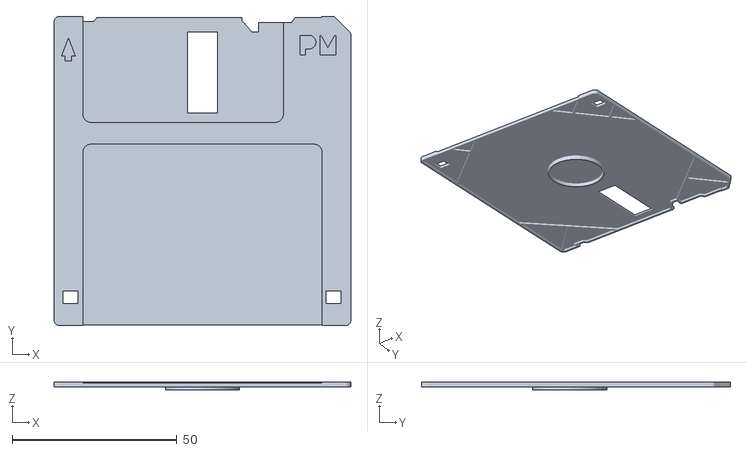
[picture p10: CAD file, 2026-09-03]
hardware/floppy-nfc-blank/top.stl
90.0 x 93.8 x 2.50

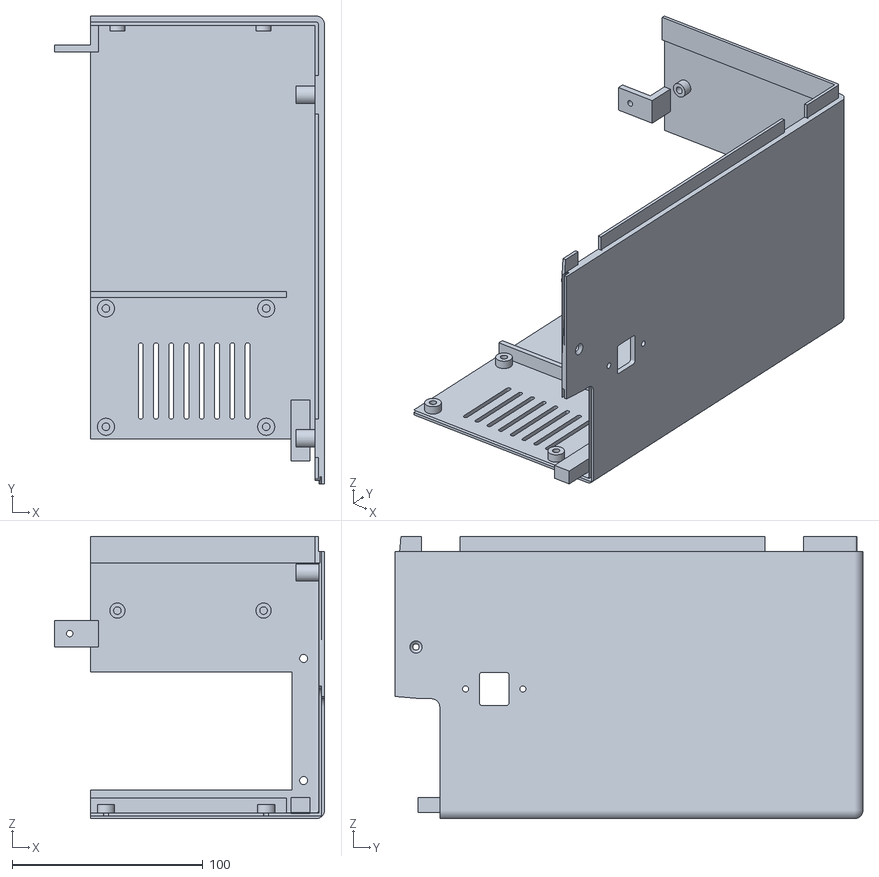
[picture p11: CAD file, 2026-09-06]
hardware/mac-classic-case/stl/back-lower-right.stl
141.6 x 245.3 x 148.0

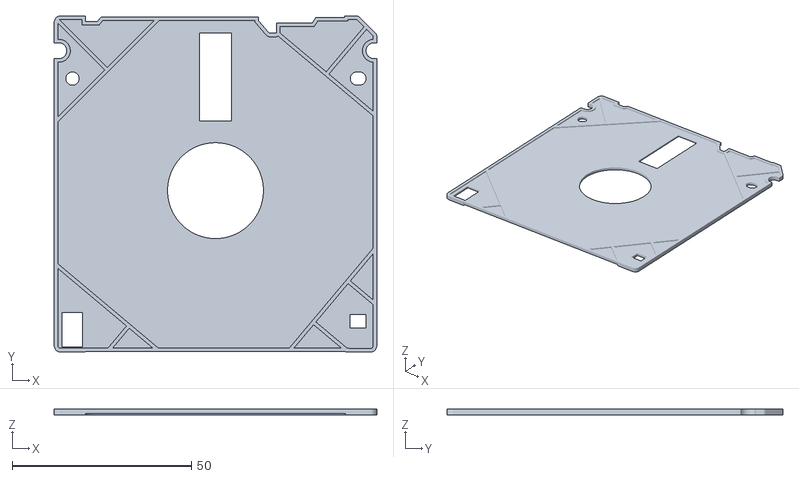
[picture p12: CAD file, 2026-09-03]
hardware/floppy-nfc-blank/base.stl
90.0 x 93.8 x 1.60

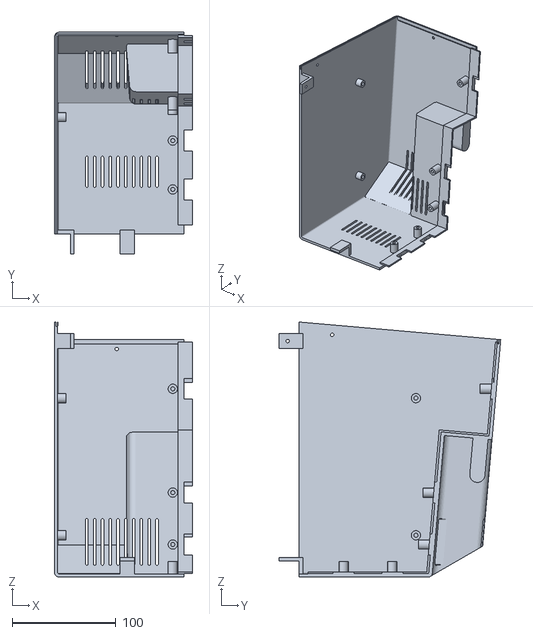
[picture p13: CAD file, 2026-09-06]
hardware/mac-classic-case/stl/back-upper-left.stl
133.0 x 213.4 x 245.6

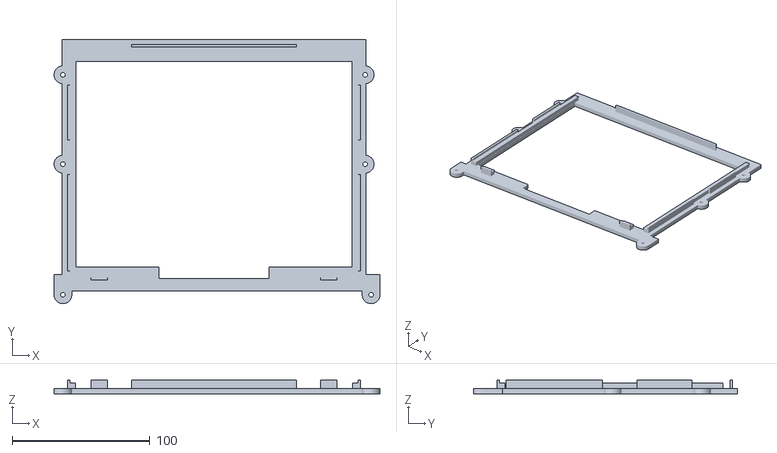
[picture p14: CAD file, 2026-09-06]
hardware/mac-classic-case/stl/lcd-frame.stl
237.1 x 192.3 x 10.3

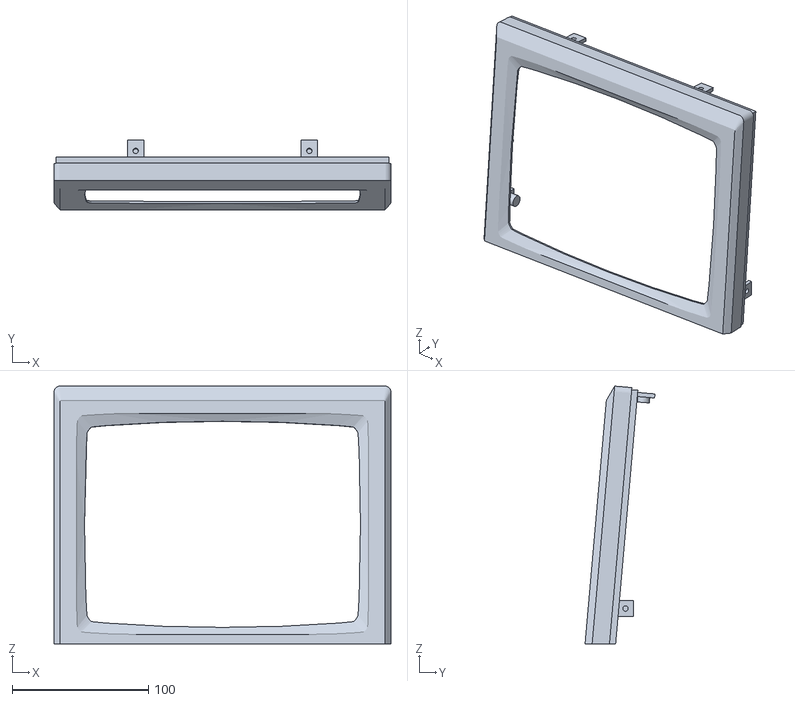
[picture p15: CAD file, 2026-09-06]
hardware/mac-classic-case/stl/front-upper.stl
247.6 x 51.4 x 189.5

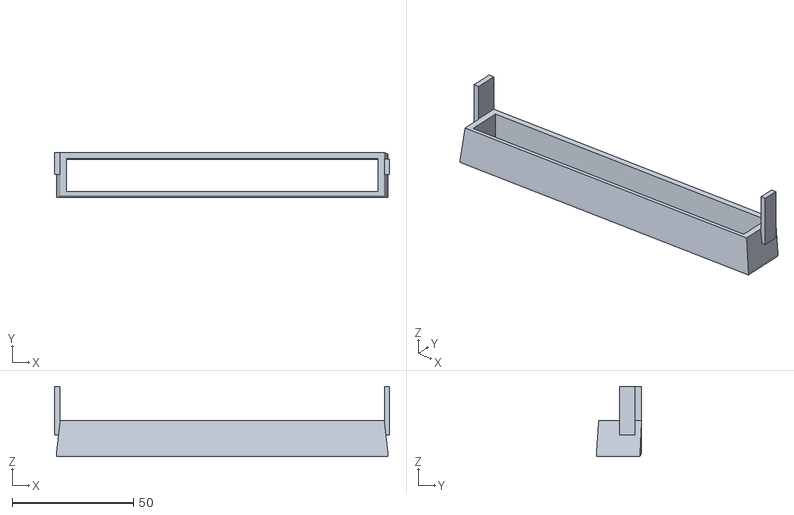
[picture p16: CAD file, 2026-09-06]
hardware/mac-classic-case/stl/dvd-funnel.stl
138.3 x 18.7 x 29.0

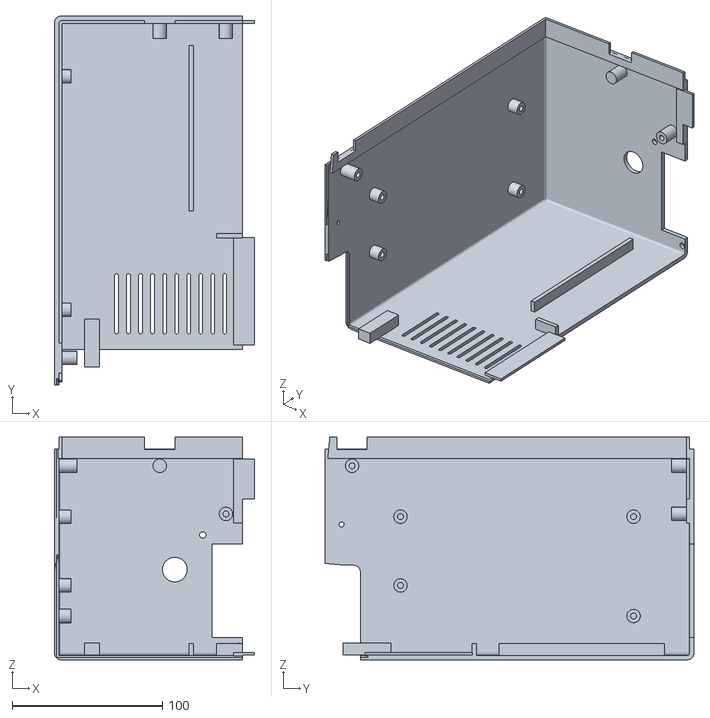
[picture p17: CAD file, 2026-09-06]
hardware/mac-classic-case/stl/back-lower-left.stl
133.0 x 245.3 x 148.0

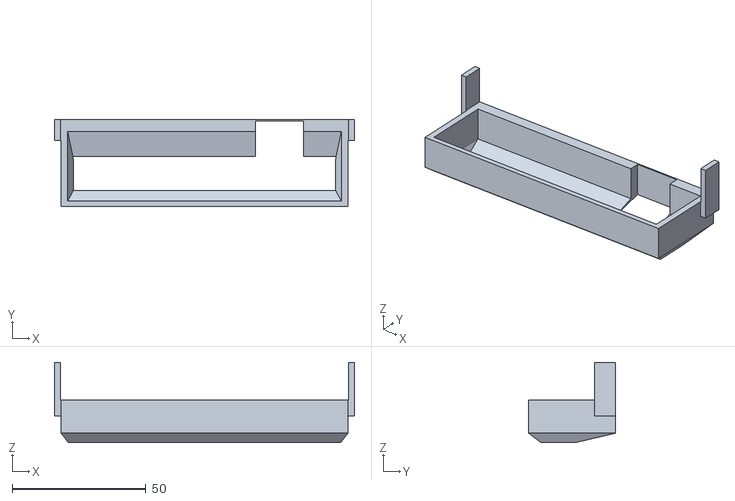
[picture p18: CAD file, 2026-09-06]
hardware/mac-classic-case/stl/fdd-funnel.stl
112.3 x 32.5 x 30.0

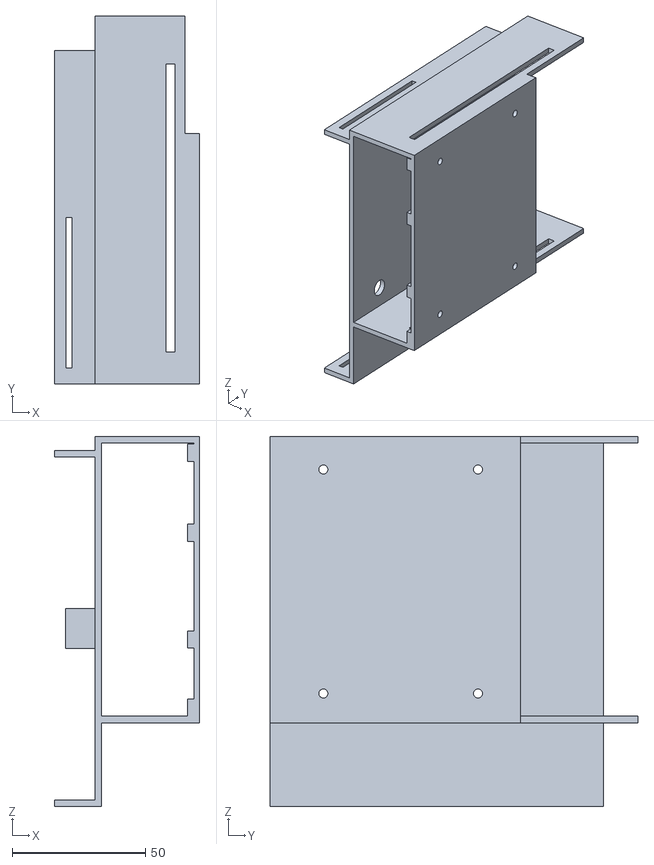
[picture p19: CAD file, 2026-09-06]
hardware/mac-classic-case/stl/drive-cage.stl
54.4 x 138.0 x 138.8

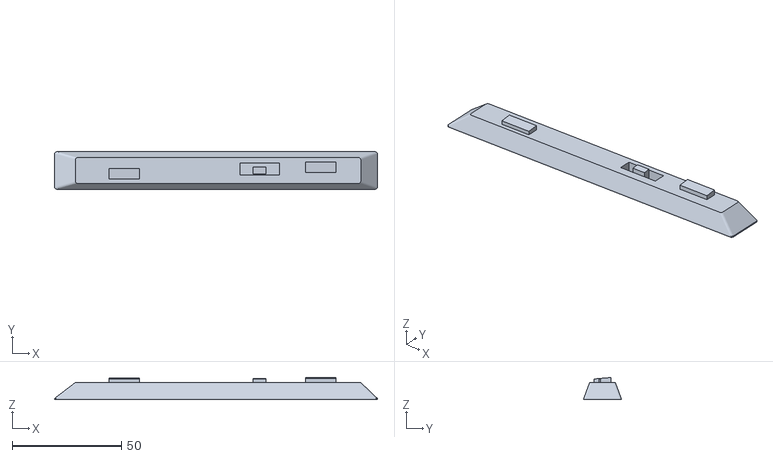
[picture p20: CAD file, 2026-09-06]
hardware/mac-classic-case/stl/dvd-tray-cover.stl
147.8 x 17.2 x 10.1

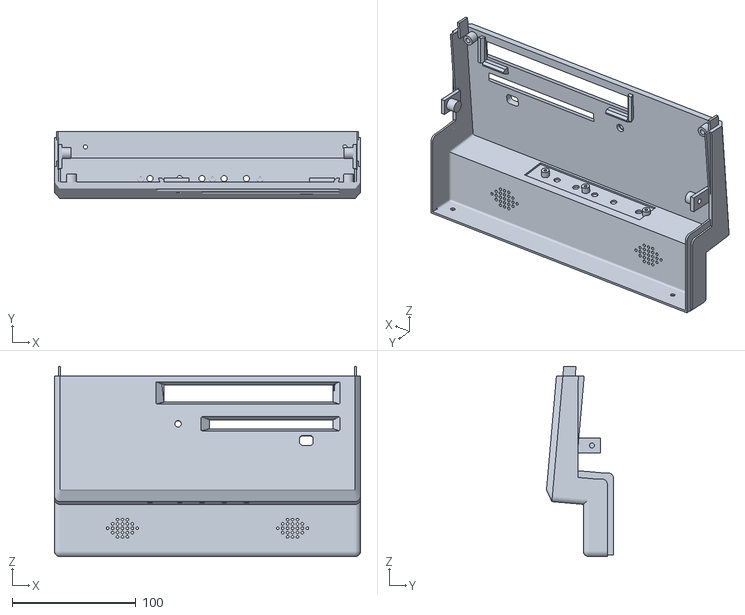
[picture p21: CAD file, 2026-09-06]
hardware/mac-classic-case/stl/front-lower.stl
247.6 x 54.3 x 154.0

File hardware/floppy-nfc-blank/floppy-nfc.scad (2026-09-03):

// RetroFloppy NFC disk — top + base shells joined into one printable part.
//
// top.stl and base.stl are two halves of a 3.5" floppy shell (made in Shapr3D,
// third-party files, not committed) that arrive already positioned as an
// assembly: the base's walls rise to z = 2.4 and the top sits exactly on that
// plane, so a plain union produces the closed disk. Both halves already model
// the open head window (cut through) and their own leading-edge notch profile,
// which is kept exactly as designed — nothing is cut into the outline here.
//
// The one addition is the NFC tag seat. The top shell is only 0.6 mm thick in
// the head-window zone, far too thin to hold a blind seat, so a pedestal is
// raised from the base plate, up through the open window, to carry the seat
// floor; the seat is then sunk into it. The tag ends up 0.4 mm below the label
// field with solid material underneath — nothing through, nothing proud.
//
// Render: mise run floppy-stl
// Print:  flat, tag seat up, no supports. PLA or PETG, never carbon-filled or
//         metallic filament: the filler shields the antenna, the tag stops
//         reading.

$fa = 1;
$fs = 0.3;

/* [Source shells] */
top_file = "top.stl";
base_file = "base.stl";
// Measured off the shells, in mm: X 0..90, Y 0..93.75 with the leading edge at
// the high-Y end, assembly z 0.8..4.0, top label field at z = 3.6, bottom face
// at z = 0.8.
source_width = 90;
source_leading_edge_y = 93.75;
field_z = 3.6;
bottom_z = 0.8;

/* [NFC tag] */
// Round NTAG21x sticker, 25 mm is the common size.
tag_diameter = 25;
tag_thickness = 0.8;
// Added to the diameter so the sticker drops in without being forced.
tag_fit = 0.4;
// Extra depth, so the sticker sits below the label field and nothing in the
// drive can scrape it.
tag_recess = 0.4;
// Distance from the leading edge to the tag centre: 16 mm is the placement the
// bench unit validated, centred on the head-window zone.
tag_offset_from_leading_edge = 16;
tag_offset_x = 0;
// Which face the seat opens on — the face the PN532 antenna looks at.
tag_face = "top"; // [top, bottom]
// Set false for the raw union of the two shells, exactly as designed.
tag_seat = true;

/* [Pedestal] */
// How far the solid backing extends beyond the seat, and how thick the floor
// under the sticker is. The pedestal hangs from the top plate and reaches no
// further down than it must, so nothing shows on the opposite face: through
// the open window on the back you see its underside a full millimetre inside,
// like the media of a real disk, never a plug at the surface.
pedestal_margin = 2;
pedestal_floor = 1.2;

seat_diameter = tag_diameter + tag_fit;
seat_depth = tag_thickness + tag_recess;
// Both variants hang the pedestal from the top plate (fused 3.0..3.4) and keep
// it clear of the opposite face. Top seat: floor just under the seat, cut from
// above. Bottom seat: floor above the cut, cut from below.
seat_floor_z = tag_face == "top" ? field_z - seat_depth : bottom_z + seat_depth;
pedestal_from_z = tag_face == "top" ? seat_floor_z - pedestal_floor : seat_floor_z;
pedestal_to_z = field_z - 0.2;

tag_x = source_width / 2 + tag_offset_x;
tag_y = source_leading_edge_y - tag_offset_from_leading_edge;

module shells() {
    import(top_file, convexity = 10);
    import(base_file, convexity = 10);
}

module pedestal() {
    translate([tag_x, tag_y, pedestal_from_z]) {
        cylinder(h = pedestal_to_z - pedestal_from_z, d = seat_diameter + 2 * pedestal_margin);
    }
}

// Cut well past the face it opens on, so raised details inside the circle go too.
module seat_cut() {
    if (tag_face == "top") {
        translate([tag_x, tag_y, seat_floor_z]) cylinder(h = 5, d = seat_diameter);
    } else {
        translate([tag_x, tag_y, seat_floor_z - 5]) cylinder(h = 5, d = seat_diameter);
    }
}

difference() {
    union() {
        shells();
        if (tag_seat) pedestal();
    }
    if (tag_seat) seat_cut();
}

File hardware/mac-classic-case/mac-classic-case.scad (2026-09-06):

/*
 * ----------------------------------------------------------------------------
 * "THE BEER-WARE LICENSE" (Revision 42):
 * Jeroen Domburg <jeroen@spritesmods.com> wrote this file. As long as you retain
 * this notice you can do whatever you want with this stuff. If we meet some day,
 * and you think this stuff is worth it, you can buy me a beer in return.
 * ----------------------------------------------------------------------------
 *
 * mac-classic-case.scad — 1:1 Macintosh Classic style PC case for RetroBox.
 * Shell geometry based on the 1:6 mini Mac by Jeroen Domburg (spritesmods.com).
 *
 * Houses a micro-ATX motherboard mounted sideways against the left wall, a
 * standard ATX (PS/2) power supply on the floor, a 3.5" floppy drive and a
 * slim tray-load optical drive behind the classic front slots, a 9.7" iPad
 * 3/4 retina panel behind the screen window, and a 2.5" drive on the rear
 * wall. Every printable piece fits a 250 x 250 x 250 mm bed: the shell splits
 * into front/back halves, each half splits horizontally, and the back pieces
 * additionally split vertically. See the README for the bill of materials,
 * print notes and assembly order.
 */

//All dimensions in mm

$fa=8; //segments/360 degrees
$fs=0.1; //min size of fragment
$fn=32; //override amount of facets

//1 = full size. The motherboard/PSU/drive mounts are real-world dimensions;
//do not change without reworking every mount.
case_scale=1;

wall=3; //shell wall thickness

overlap=5; //overlap between front/back halves
overlapth=1.5; //material thickness at the overlap

cw = 247.6*case_scale; //outer case width
cd = 241.3*case_scale; //outer case depth

// ========================= Fasteners =========================
//Every M3 anchor takes a heat-set threaded insert: d4.0 hole, >=6.5 deep
//(Ruthex/Voron standard; adjust for your inserts). Self-tapping exceptions:
//the OSD strip (M2.5, thin bosses) and the speakers (M2, if not glued).
insert_d = 4.0;

// ========================= Part selection =========================
//Views (for inspection, not printing):
//  assembly       - complete case with the internal printed parts in place
//  cutaway        - same, sectioned through the middle
//  cage-assembly  - drive cage + pedestals + HDD cradle in position
//Printable parts (each renders in its print orientation):
//  front-lower, front-upper, back-lower-left, back-lower-right,
//  back-upper-left, back-upper-right, drive-cage, cage-pedestals, hdd-cradle,
//  lcd-frame, dvd-tray-cover, fdd-funnel, dvd-funnel, eject-cap, tpu-feet
part = "assembly";

show_hardware = false; //ghost motherboard/PSU/drives in the views (preview only)


// ========================= Motherboard (micro-ATX) =========================
//244 x 200 board standing on edge: the IO edge (244) vertical, the board
//depth (200) horizontal toward the back. Components face inward, IO shield
//faces the case front, so the IO block ends up top-front and the expansion
//slots at the bottom. Verified with a Biostar H55 HD and an MSI PRO H610M-S.
mobo_w        = 244;   //length of the IO edge
mobo_d        = 200;   //board depth
mobo_pcb      = 1.6;   //PCB thickness
standoff_h    = 8;     //printed standoff height
standoff_d    = 9;     //standoff outer diameter
standoff_drill= insert_d; //M3 insert hole
mobo_y_io     = 36;    //Y of the IO edge (connectors overhang toward y-)
mobo_z_top    = 259;   //Z of the board's top edge (IO-side corner up)

//micro-ATX mounting holes (Intel spec) present on 244 x ~200 boards:
//[u, v] with u = distance along the IO edge from the IO-block corner,
//v = depth from the IO edge.
mobo_holes = [
    [  6.35,  33.02],  //0: behind the IO connector block
    [163.83,  10.16],  //1: rear row, between slots
    [209.55,  10.16],  //2: rear row, between slots (Datum B)
    [  6.35, 165.10],  //3: middle row, IO side
    [163.83, 165.10],  //4: middle row
    [209.55, 165.10],  //5: hole S
    [229.87, 165.10],  //6: hole R
];
//Disable the holes your board lacks: a standoff pressed against the solder
//side can short it. Hole S (index 5) is absent on both boards tested.
mobo_hole_on = [true, true, true, true, true, false, true];


// ========================= 3.5" PC floppy drive =========================
//Sits level behind the classic front slot (the front leans -5 degrees; the
//guide funnel bridges the difference). Dimensions: NEC FD1231T.
fdd_w = 101.6; fdd_h = 25.4; fdd_d = 146;
fdd_y_front = -12;         //front face of the drive. Limit ~-12.5: the eject
                           //button (~6 mm proud) plus the cap wall must stay
                           //>=1 mm off the sloped front's inner face. The
                           //funnel and eject cap derive from this value.
fdd_slot_cx = 175.7;       //slot center X (129 + 93.4/2)
fdd_slot_z  = 107.5;       //slot center Z, fixed by the classic front
fdd_slot_below_top = 8.7;  //FD1231T: disk door axis 8.7 below the drive top
fdd_top_z = fdd_slot_z + fdd_slot_below_top;
//Eject button hole (below-right of the slot, own mini-bevel):
//[x from the slot's left end, z from the slot axis (negative=down), w, h]
fdd_eject = [74.8, -13.5, 11, 8];
//Physical button position on the drive, relative to the disk slot (used by
//the ghost and the cage channel only; the cap uses fdd_latch)
fdd_button = [74.8, -10.1];
//This FD1231T has its original button removed: the face keeps a 19.5 wide x
//8 high x ~5 deep pocket with the bare eject lever inside — a 7 x 1 hook,
//vertically centered, starting 5 from the pocket's left edge. Flush with the
//face when empty; protrudes 5 (the eject travel) with a disk in.
fdd_latch = [73.4, 16];   //[hook left edge from the slot, hook top face from
                          //the drive top]

// ========================= Slim optical drive (SATA, tray-load) =========================
//Mounted ABOVE the floppy slot: below it the drive body (126 deep) hits the
//PSU (which reaches z=89 and starts at y=98).
odd_w = 128; odd_h = 12.7; odd_d = 126.1;
odd_y_front = -13;         //front face of the drive. Limit ~-14.9: the top
                           //front corner (z=138.2) meets the sloped front at
                           //y~-16.9; the printed tray face clears the inner
                           //face by ~2 mm.
odd_slot_cx = 157.4;       //center X: chosen so the RIGHT end of mouth and bevel aligns with the floppy's
odd_slot_z  = 132.5;       //slot center Z (25 above the floppy slot; lower hits the classic bezel)
odd_slot_w = 130; odd_slot_h = 12;  //narrow through mouth (128 x ~10 tray + printed face)
odd_bezel_h = 18;                   //bevel height; widths reuse the floppy margins (10.4/8.5)
odd_bottom_z = odd_slot_z - 7;      //the tray axis sits ~7 above the drive base
//Side M2 screws into the drive's threaded side holes (2 per side). Instead of
//fixed holes, ONE sliding slot per bay wall at this z lets the drive move in
//depth. y = odd_y_front + measured hole-to-face distances (24 and 104).
odd_side_screw_d = 2.3;                                       //M2 free pass (= slot height)
odd_side_screws  = [[odd_y_front+24, odd_bottom_z+9.6], [odd_y_front+104, odd_bottom_z+9.6]];
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

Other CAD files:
hardware/mac-classic-case/stl/eject-cap.stl
hardware/mac-classic-case/stl/cage-pedestals.stl
hardware/mac-classic-case/stl/hdd-cradle.stl
hardware/mac-classic-case/stl/back-upper-right.stl

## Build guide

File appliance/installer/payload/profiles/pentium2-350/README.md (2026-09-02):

# Pentium II 350 86Box Profile

This directory contains the native 86Box profile for the Retro PC Pentium II 350 VM.
The 86Box config file is the source of truth for hardware selection.

## Hardware

- Machine: `p2bls`
- CPU: `pentium2_deschutes`, 350 MHz (3.5x multiplier), dynarec `new`, internal FPU
- RAM: 128 MB
- Video: 3dfx Voodoo3 3000 AGP (`voodoo3_3k_agp`) with SyncMaster EDID (`syncmaster3.edid`)
- Sound: Sound Blaster AWE64 Gold (`sbawe64_gold`)
- Input: PS/2 keyboard + PS/2 mouse (4 buttons)
- GPIO: HDD activity on `/dev/gpiochip0` pin 360 (active-low)
- Storage: IDE, hard disk `hdd.raw` with ~20 GB geometry (63, 255, 2434), 5400 RPM (`1998_5400rpm`)
- Floppy: one 3.5-inch 1.44 MB drive with `alps_df354h148f_80t` audio
- CD-ROM: one ATAPI 72x DVD slot; its portable template has no host path. When an appliance detects a physical drive, its installed copy receives an `ioctl://<detected-device>` path for this first active slot
- Network: none (all slots disabled)
- Expected OS: Windows 98 SE, installed manually later

## Launch

Copy or import this directory as an ordinary 86Box VM profile. Keep
`86box.cfg` and `hdd.raw` in the same directory because the hard disk path in
the config is relative:

```text
hdd_01_fn = hdd.raw
```

The SDL graphics configuration enables the bundled CRT shader:

```text
shader0 = /opt/86Box/shaders/crt/crt-easymode.glslp
```

with per-profile tuning:

```text
[GL3 Shaders - crt-easymode.glslp]
SCANLINE_CUTOFF = 700
SCANLINE_BRIGHT_MIN = 0.55
SCANLINE_BRIGHT_MAX = 0.75
MASK_SIZE = 2
MASK_STRENGTH = 0.30
MASK_STAGGER = 3
MASK_DOT_HEIGHT = 2
SHARPNESS_H = 1.0
GAMMA_INPUT = 2.4
BRIGHT_BOOST = 1.25
```

The monitor EDID is loaded from the installed path:

```text
monitor_edid_path = /data/vms/pentium2-350/syncmaster3.edid
```

Launching the template should reach BIOS and then an empty/non-system disk
state. Install Windows 98 SE manually later if the VM needs to become bootable.
The appliance installer, not this portable template, configures a detected
physical drive. Validate installed passthrough with
[`docs/cdrom-passthrough.md`](../../../../docs/cdrom-passthrough.md).

## Blank Disk

`hdd.raw` is intentionally blank and is not committed to Git. The appliance
installer (and `appliance/installer/payload/scripts/retrobox-hdd-creation`)
creates it on first install from the geometry declared in the 86Box profile:

```text
hdd_01_parameters = 63, 255, 2434, 0, ide
```

This is approximately 20 GB (18.6 GiB). Do not replace this file with an
installed OS image in the repository.

## Generated State

86Box may create an `nvr/` directory after the VM boots. That BIOS/NVR state is
runtime-generated and is not part of the profile template.

## Media Policy

This profile includes no DOS, Windows, drivers, games, floppy images, CD-ROM
images, or other copyrighted media.

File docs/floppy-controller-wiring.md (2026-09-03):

# Floppy Controller Wiring

Physical wiring and mechanical validation for the modified floppy drive that
hosts the NodeMCU + PN532 NFC reader. The NFC tag doubles as the disk-present
sensor, so there is no mechanical switch to wire.

The firmware side is documented in
[`firmware/retrofloppy-esp8266/README.md`](../firmware/retrofloppy-esp8266/README.md);
this file records the physical build inside the drive and the bench results.

## Bill of materials

| Part | Role |
| --- | --- |
| NodeMCU v2 (ESP8266) | USB serial bridge to the Retro PC host and PN532 controller. |
| PN532 NFC module (I2C) | Reads the NTAG21x / MIFARE Ultralight tag glued inside a floppy shell. |
| NTAG21x / MIFARE Ultralight tag | Carries the `<id>,<mode>` payload for the disk it is glued to, and doubles as the disk-present sensor. |
| 4.7 kΩ resistors (optional) | I2C pull-ups on SDA/SCL to 3.3 V, only if reads are flaky. |

## NodeMCU pin assignment

| NodeMCU pin | GPIO | Function |
| --- | --- | --- |
| `D1` | 5 | `Wire` SCL to PN532. |
| `D2` | 4 | `Wire` SDA to PN532. |
| `3V3` | — | PN532 VCC. |
| `GND` | — | Common ground for the PN532. |
| `TX` / `RX` | 1 / 3 | USB serial to the Retro PC host (115200 baud, 8N1). |

`D0`, `D3`, `D4`, and `D8` are deliberately avoided because of ESP8266 boot
strapping constraints (see `firmware/retrofloppy-esp8266/README.md`).

## PN532 interface and board settings

- **Interface:** I2C only, 7-bit address `0x24` (`0x48` >> 1).
- **Board mode selector:**
  - Adafruit-style breakout: `SEL0 = ON`, `SEL1 = OFF`.
  - Elechouse-style module: both DIP switches to the row silkscreened as I2C.
    Labels vary between clones, so follow the silkscreen, not a remembered
    switch order.
- **Reset (`RSTPD_N` / `RST`):** left unconnected. The module is reset only by
  power-cycling the NodeMCU. If a hard reset line turns out to be necessary
  on the bench, pick a safe GPIO and update this section before changing the
  firmware.
- **`IRQ`:** unconnected. The firmware polls the PN532 instead of using the
  interrupt line.
- **I2C pull-ups:** some boards ship with populated pull-ups and some do not.
  If reads become flaky, add 4.7 kΩ pull-ups from SDA and SCL to 3.3 V. The
  bench unit did not need them.

## Disk-present detection

There is no mechanical disk-present switch. An earlier build used the drive's
repurposed media-sensor lever on `D6`, but the switch never actuated reliably
in the modified drive, so it was removed. Instead the firmware polls the
PN532 — every 100 ms with a disk seated, every 250 ms with the drive empty —
and derives the drive state from tag presence:

- Tag becomes readable → `INSERT <payload>`. The event fires only once the
  disk is seated well enough to actually read, so there is no race between
  "detected" and "readable".
- Tag absent for 3 consecutive polls (~300–400 ms) → `EJECT`. The hysteresis
  absorbs single missed reads of a seated tag.

The mechanical consequence for tag placement is stricter than before: the tag
must couple with the antenna **only when the disk is fully seated**. If a
half-inserted disk already reads, move the antenna deeper into the drive or
increase the tag–antenna distance. A floppy without a tag is invisible — it
reads as an empty drive.

## Recommended NFC tag placement

The tag is glued **inside the floppy shell, against the inner face of the
sliding shutter, with the shutter held open when the
disk is inserted — i.e. the tag sits where the magnetic read/write head
originally was, not over the magnetic media and not under the closed shutter.

This placement was reached by elimination after the metal of the drive
interfered with the PN532 antenna:

1. Over the centre of the floppy disk: the drive chassis is all-metal and
   shields the antenna, so the PN532 cannot read the tag.
2. On the inner face of the open shutter (head area): reads reliably, and the
   shutter stays open while the disk is in the drive. This is the adopted
   placement.
3. With the external metal cover of the drive reinstalled: interference
   returns and reads fail again. The bench unit therefore runs with the
   drive's outer cover removed.

**Do not** reinstall the floppy drive's metal cover. The exposed PCB is the
known working condition; covering it reintroduces the NFC shielding failure
even with the correct tag placement.

## USB routing and power plan

| Rail | Path |
| --- | --- |
| NodeMCU 3V3 | Internal regulator from USB; also feeds the PN532 `VCC`. |
| PN532 VCC | NodeMCU `3V3` pin, so the PN532 boots when the NodeMCU is USB-powered. |
| Ground | NodeMCU `GND` is the common ground for the PN532. |
| USB cable | From the NodeMCU micro-USB port straight to the Retro PC host. The host provides both power and the 115200 baud serial link on `TX`/`RX`. |

The whole modified drive is powered through the NodeMCU's USB connection; no
separate 5 V rail is wired into the floppy chassis. The PN532 draws its
current from the NodeMCU `3V3` regulator, which is rated for the module's
standby and active current. Note the PN532 now polls continuously (RF field on
every 100–250 ms depending on state), so it sits at its active current more of
the time than the switch-triggered build did; the `3V3` regulator still has
headroom. If a future build adds pull-ups or a second I2C peripheral, re-check
the budget.

## Bench results

### 20 insert/eject cycles (switch-based build, historical)

These results predate the removal of the disk-present switch: they were run on
the switch-triggered firmware, after the 5 ms debounce fix, with the same
NTAG21x tag glued in the adopted position (open shutter, drive cover removed).
The NFC-polling build should be re-validated with a fresh 20-cycle run.

| Result | Count |
| --- | --- |
| `INSERT <payload>` emitted with correct tag read | 20 / 20 |
| `EJECT` emitted on removal | 20 / 20 |
| Missed reads (`ERROR TAG not read`) | 0 |
| False positives (spurious `INSERT` with no disk) | 0 |
| Bounce-induced phantom events | 0 |

All 20 cycles succeeded with no missed reads and no false positives.

### Tag position / orientation trials

Three positions were tested with the PN532 antenna before settling on the
final placement:

| # | Position | Result |
| --- | --- | --- |
| 1 | Tag over the centre of the floppy disk | **Fail** — the all-metal drive chassis shields the antenna; the PN532 cannot read the tag. |
| 2 | Tag on the inner face of the shutter, with the shutter open (head area) | **Pass** — reliable reads, adopted placement. |
| 3 | Same placement as #2 but with the floppy drive's external metal cover reinstalled | **Fail** — the cover reintroduces shielding; reads are lost again. |

### Issues observed

- **Disk-present switch (removed):** the initial build detected the floppy
  with a repurposed lever switch on `D6`. It first needed a 5 ms Bounce2
  debounce to stop phantom events, and later proved mechanically unreliable —
  the lever did not actuate consistently in the modified drive. The switch was
  removed entirely; presence is now derived from the NFC tag being readable
  (see “Disk-present detection”).
- **NFC shielding (ongoing design constraint):** the floppy drive chassis is
  all-metal and blocks the PN532 antenna. Tag placement had to be moved off
  the disk centre, onto the open metal shutter at the head opening, and the
  drive's outer metal cover had to be removed. Reinstalling the cover
  reintroduces the failure. This is the known working condition for the bench
  unit; any future enclosure (e.g. 3D-printed plastic) should be non-metallic
  on the antenna side.

## Printable floppy disk

Real floppies work, but the disks that carry a tag day to day are printed:
[`hardware/floppy-nfc-blank/`](../hardware/floppy-nfc-blank/README.md) joins a
pair of 3.5" shell halves into one part with an always-open head window and a
blind seat for a 25 mm round tag, placed where the trials above landed. It has
no shutter and no metal hub, so nothing can slide shut over the antenna and
nothing shields it.

## Acceptance checklist

- [x] Documents exact NodeMCU pins used.
- [x] Documents PN532 interface mode and jumper/switch settings.
- [x] Documents how disk presence is detected (NFC polling; no switch).
- [x] Documents recommended NFC tag placement inside a floppy shell.
- [x] Documents USB routing/power plan.
- [x] Records results of 20 insert/eject cycles.
- [x] Records at least three tag position/orientation tests.
- [x] Lists any false positives, missed reads, or mechanical issues.

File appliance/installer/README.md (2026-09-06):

# RetroBox USB appliance installer

This directory builds a **bootable USB installer** that installs the RetroBox
Debian appliance onto the target machine's internal HDD/SSD.

The installed system is a **writable-root** Debian 13 appliance with a mutable
`/data` partition, a GPT disk layout with a 512 MiB EFI System Partition, GRUB
installed as UEFI and SSH maintenance access — see
[`../README.md`](../README.md) and [`../filesystem-layout.md`](../filesystem-layout.md).

> **First functional slice.** This implements the end-to-end build → boot →
> safe install → read-only-root path. A few things are intentionally deferred
> and recorded rather than blocking the install — see
> [Scope & deferrals](#scope--deferrals).

## How it works

The build produces **two** root filesystems packed into one hybrid ISO:

1. A small **live installer** rootfs (`live/filesystem.squashfs`) that boots from
   USB and auto-runs [`install-retropc.sh`](install-retropc.sh) on tty1.
2. The **target appliance** rootfs (`install/target-rootfs.squashfs`), built from
   [`../debian/packages.txt`](../debian/packages.txt), carried on the USB and
   extracted onto the internal disk. The install is **offline** — no network is
   needed on the retro PC.

```text
Build USB installer image        (build-usb-installer.sh)
Write image to a USB stick       (dd)
Boot the retro PC from USB       (BIOS legacy OR UEFI; hybrid ISO)
Installer auto-starts on tty1    (install-retropc.sh)
Pick the internal disk           (USB device excluded; typed confirmation)
Partition + format               (fresh: GPT p1 ESP, p2 root ro, p3 /data rw)
Preserve existing /data          (reinstall: keep VMs/floppies, rewrite root+ESP)
Extract appliance rootfs         (offline, from the USB)
Write UUID fstab, users, GRUB    (UEFI: ESP + GRUB-EFI; root locked; password prompted)
Remove USB and reboot            (target boots the installed appliance)
```

## Build

### CI (recommended)

`.github/workflows/build-usb-installer.yml` runs shellcheck, calls the
`build-retrobox.yml` workflow as a reusable workflow to build and publish the
RetroBox Linux x64 binary, then builds the image on a native Linux runner and
uploads `retropc-installer.iso` as an artifact. Because the installer workflow
invokes the .NET build itself (instead of reusing an older published artifact),
the ISO always embeds the exact code at the tested commit.
Download it from the workflow run, then flash it (below).

### Local (macOS / Docker)

The Debian tooling needs Linux, so build in the privileged builder container.
The image is amd64 (the appliance target); on Apple Silicon add
`--platform linux/amd64` so mmdebstrap builds natively under emulation:

```bash
docker build --platform linux/amd64 -t retropc-builder appliance/installer
docker run --rm --platform linux/amd64 --privileged -v "$PWD:/work" \
    retropc-builder /work/appliance/installer/build-usb-installer.sh
# -> appliance/installer/out/retropc-installer.iso
```

On an amd64 host you can drop `--platform linux/amd64`.

### Local (native Linux)

```bash
sudo apt-get install -y mmdebstrap squashfs-tools xorriso \
    isolinux syslinux-common grub-efi-amd64-bin mtools dosfstools zstd e2fsprogs
sudo bash appliance/installer/build-usb-installer.sh
```

### Embedding the runtime

The build always embeds the published RetroBox binary and downloads the pinned
86Box AppImage, ROM tarball, and the pinned libretro GLSL shader archive from
`appliance/86box.env`, validating all three
SHA256 values. To build locally:

```bash
mise run publish-linux-x64   # produces the retrobox linux-x64 single-file binary
RETROBOX_BIN=path/to/retrobox BOX86_APPIMAGE=path/to/86box.AppImage \
    sudo bash appliance/installer/build-usb-installer.sh
```

The publish output also contains `libSystem.IO.Ports.Native.so` (NativeAOT cannot
statically link `System.IO.Ports`); the build stages it next to the binary and
installs it to `/opt/retrobox/` when the publish output provides it. The publish
workflow asserts it exists; an installer built from a stale runtime artifact
warns instead of failing.

The installer copies the runtime to `/opt`, the 86Box shaders to
`/opt/86Box/shaders`, and `vms.yaml` to
`/data/retrobox/vms.yaml`, and both complete profiles to `/data/vms`. It does
not create `config.yaml`; that file remains optional runtime state.

## Flash to USB

```bash
# macOS: find the disk with `diskutil list`, unmount, then (BE SURE of the disk):
sudo dd if=appliance/installer/out/retropc-installer.iso of=/dev/rdiskN bs=4m
# Linux:
sudo dd if=appliance/installer/out/retropc-installer.iso of=/dev/sdX bs=4M status=progress
```

## Install onto the retro PC

1. Set the firmware to boot from USB (legacy BIOS **or** UEFI — the same image
   supports both).
2. Boot; the installer starts on the primary display.
3. Choose the internal disk. **The USB installer device is excluded by default**,
   and you must type the exact `ERASE /dev/sdX` confirmation before anything is
   written.
4. Set the `retrobox` password when prompted (used for SSH and `sudo`).
5. Press Enter to reboot **with the USB still inserted** (the live installer runs
   from it). Remove the USB while the machine restarts — at the firmware/logo
   screen — so it boots from the internal disk.

## Reinstall & data preservation

Re-running the installer over an existing appliance asks whether to keep your data:

- The `/data` partition is **not** reformatted. Only the read-only root
  filesystem is rewritten (still gated by the typed `ERASE /dev/sdX` confirm).
- Everything on `/data` survives: VMs (`hdd.raw`), the VM catalog (`vms.yaml`),
  floppies and snapshots.
- OS-managed profile files (`86box.cfg`, EDID) **are** refreshed; `hdd.raw` and
  `.yaml` files are never overwritten.
- Answer `n` (or press Enter) to the "Preserve /data?" prompt to fully wipe and
  refresh the installation. Set `RETROPC_WIPE_DATA=1` for unattended installs.

## Accounts & maintenance

- `root` is **locked**. `retrobox` is the sole account — the service runtime user
  and the SSH maintenance login, with `sudo`.
- Maintenance over SSH: `ssh retrobox@<ip>` (DHCP; `PermitRootLogin no`).
- The root filesystem is writable, so system files can be edited normally.
  `/data` is also writable.

## Machine selector

Press F12 during the boot window to open the text selector on the appliance
console. Press a VM's displayed number to start it. Press `D`, then a VM number,
to save it as the default and start it immediately. `Esc` cancels; if a default
is already configured, cancellation starts that VM.

Closing a VM returns to the selector so another VM can be started without a
reboot. `Esc` on that returned selector ends the session and returns to the
tty1 login; it does not restart the VM that just closed.

The Plymouth splash stays up until 86Box's first frame: `retrobox boot`
retains it before launching a VM and quits it before the selector, so boot and
86Box loading text never flashes on the terminal.

The floppy daemon re-syncs the drive when a VM starts: once the 86Box
floppy-control socket is ready it sends `STATUS` to the floppy controller and
applies the reported physical floppy, so swaps made while the VM was off are
loaded on power-on.

## Recovery

- Hold **Shift** (or press **Esc**) during boot to reveal the hidden GRUB menu.
- Choose **"RetroBox — recovery (maintenance, no fullscreen VM)"**. It appends
  `retropc.norun=1`, so `retrobox-boot.service` skips the fullscreen VM path and
  leaves a normal login on tty1 (SSH still works).

## Verification

Automated (CI / local):

- `shellcheck -x` on all installer scripts.
- The build asserts the ISO is isohybrid (MBR boot sector for legacy BIOS
  boot); that the El-Torito catalog holds two entries and names the EFI image;
  that the EFI image (`boot/grub/efi.img`) is a real FAT filesystem containing
  `EFI/BOOT/BOOTX64.EFI` rather than a bare PE binary; that the ISO carries a
  GPT in its system area, which is what UEFI firmware reads once the image is
  `dd`'d to a USB stick; that `target-rootfs.squashfs` is valid; and that the
  expected package binaries (`sshd`, `plymouth`, `grub-install`,
  `grub-mkimage`) are present.

Manual (on real hardware / a spare disk):

- Installer auto-starts on tty1; the target list excludes the USB device.
- Installed disk boots without the USB; `ssh retrobox@<ip>` works.
- `/data` is writable; `/etc/fstab` uses UUIDs; root is read-only.
- CD-ROM and ESP8266 device choices are recorded in
  `/data/retrobox/install-report.txt`.
- With a detected CD-ROM drive, the installer configures the first active
  optical slot in each applicable installed profile with its `ioctl://` path;
  templates remain portable. See [`../../docs/cdrom-passthrough.md`](../../docs/cdrom-passthrough.md)
  for target-hardware validation.

## Scope & deferrals

Fully implemented: two-rootfs build + hybrid BIOS/UEFI ISO, safe disk
selection, GPT partitioning (ESP + root + /data) with safe MBR→GPT migration
for legacy installs, offline rootfs extract, UUID fstab (root, ESP, /data),
read-only root via `ro` + tmpfs + `/var` overlay on `/data`, `retrobox` account
(root locked) with prompted password, SSH, DHCP networking,
Plymouth boot splash, GRUB-EFI install with hidden menu + recovery
entry, zram + `/data` swapfile backstop for the low-RAM machine, the
`retrobox-daemon` / `retrobox-boot` systemd units, and reinstall data
preservation (existing `/data`, `hdd.raw`, and `.yaml` are kept unless
`RETROPC_WIPE_DATA=1`).

Deferred and recorded in `install-report.txt` rather than failing the install:

- **RetroBox binary / 86Box AppImage / ROMs** — required at build time; the
  AppImage and ROM tarball are downloaded and checksum-verified from
  `appliance/86box.env`.
- **ESP8266 serial** — detected when present; otherwise the daemon config
  keeps a documented placeholder path. Electronics validation is tracked in
  #22 / #35.
- **Fullscreen 86Box boot path** — `retrobox boot` is wired via
  `retrobox-boot.service` but the graphics stack lands with #26; until then tty1
  shows the placeholder boot service (use SSH or the recovery entry for a shell).
- **Network beyond DHCP** — static addressing / DNS tuning is out of scope.
- **Secure Boot** — the installer targets non-Secure-Boot UEFI; a signed shim
  is not staged. Machines with Secure Boot enforced will need it disabled in
  firmware or a shim added later.

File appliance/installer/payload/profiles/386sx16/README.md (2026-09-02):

# 386SX-16 86Box Profile

This directory contains the native 86Box profile for the Retro PC 386SX-16 VM.
The 86Box config file is the source of truth for hardware selection.

## Hardware

- Machine: `awardsx`
- CPU: `i386sx`, 16 MHz, dynarec disabled
- RAM: 2 MB
- Video: Trident TVGA 8900 ISA VGA, 512 KB
- Storage controller: ISA IDE
- Hard disk: `hdd.raw`, 54 MB blank disk with geometry 39, 4, 762
- Floppy: one 3.5-inch 1.44 MB drive with `alps_df354h148f_80t` audio
- Sound card: none; PC speaker only
- CD-ROM: none
- Expected OS: DOS, installed manually later

## Launch

Copy or import this directory as an ordinary 86Box VM profile. Keep
`86box.cfg` and `hdd.raw` in the same directory because the hard disk path in
the config is relative:

```text
hdd_01_fn = hdd.raw
```

The SDL graphics configuration enables the bundled CRT shader:

```text
shader0 = /opt/86Box/shaders/crt/crt-easymode.glslp
```

with per-profile tuning:

```text
[GL3 Shaders - crt-easymode.glslp]
SCANLINE_CUTOFF = 900
SCANLINE_BRIGHT_MIN = 0.30
SCANLINE_BRIGHT_MAX = 0.65
MASK_SIZE = 3
MASK_STRENGTH = 0.35
MASK_STAGGER = 3
MASK_DOT_HEIGHT = 2
SHARPNESS_H = 0.7
GAMMA_INPUT = 2.4
BRIGHT_BOOST = 1.3
```

Launching the profile should reach BIOS and then an empty/non-system disk
state. Install DOS manually later if the VM needs to become bootable.

## Blank Disk

`hdd.raw` is intentionally blank and is not committed to Git. The appliance
installer (and `appliance/installer/payload/scripts/retrobox-hdd-creation`)
creates it on first install from the geometry declared in the 86Box profile:

```text
hdd_01_parameters = 39, 4, 762, 0, ide
```

Do not replace this file with an installed OS image in the repository.

## Generated State

86Box may create an `nvr/` directory after the VM boots. That BIOS/NVR state is
runtime-generated and is not part of the profile template.

## Media Policy

This profile includes no DOS, Windows, drivers, games, floppy images, CD-ROM
images, or other copyrighted media.

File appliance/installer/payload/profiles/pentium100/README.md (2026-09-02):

# Pentium 100 86Box Profile

This directory contains the native 86Box profile for the Retro PC Pentium 100
VM. The 86Box configuration is the source of truth for hardware selection.

## Hardware

- Machine: `8500tuc`
- CPU: `pentium_p54c`, 100 MHz (1.5x multiplier), dynarec enabled
- RAM: 8 MB
- Video: Trident TGUI9440AGi PCI, 1 MB
- Sound: Sound Blaster 16
- Hard disk: `hdd.raw` with approximately 2.1 GB geometry (63, 16, 4092)
- Floppy: one 3.5-inch 1.44 MB drive with `alps_df354h148f_80t` audio
- CD-ROM: one ATAPI 4x slot; its portable template has no host path. When an
  appliance detects a physical drive, its installed copy receives an
  `ioctl://<detected-device>` path for this first active slot
- Expected OS: DOS and Windows 3.1, installed manually later

## Launch

Copy or import this directory as an ordinary 86Box VM profile. Keep
`86box.cfg` and `hdd.raw` in the same directory because the hard disk path in
the config is relative:

```text
hdd_01_fn = hdd.raw
```

The SDL graphics configuration enables the bundled CRT shader:

```text
shader0 = /opt/86Box/shaders/crt/crt-easymode.glslp
```

with per-profile tuning:

```text
[GL3 Shaders - crt-easymode.glslp]
SCANLINE_CUTOFF = 540 (scanlines en 640×480, apagadas de 800×600 para arriba)
SCANLINE_BRIGHT_MIN = 0.45
SCANLINE_BRIGHT_MAX = 0.70
MASK_SIZE = 2
MASK_STRENGTH = 0.35
MASK_STAGGER = 3
MASK_DOT_HEIGHT = 2
SHARPNESS_H = 0.9
GAMMA_INPUT = 2.4
BRIGHT_BOOST = 1.3
```

Launching the template should reach BIOS and then an empty/non-system disk
state. Install DOS and Windows 3.1 manually later if the VM needs to become
bootable. The appliance installer, not this portable template, configures a
detected physical drive. Validate installed passthrough with
[`docs/cdrom-passthrough.md`](../../../../docs/cdrom-passthrough.md).

## Blank Disk

`hdd.raw` is intentionally blank and is not committed to Git. The appliance
installer (and `appliance/installer/payload/scripts/retrobox-hdd-creation`)
creates it on first install from the geometry declared in the 86Box profile:

```text
hdd_01_parameters = 63, 16, 4092, 0, ide
```

This is in the spirit of a Quantum Bigfoot-era disk. Do not replace this file
with an installed OS image in the repository.

## Generated State

86Box may create an `nvr/` directory after the VM boots. That BIOS/NVR state is
runtime-generated and is not part of the profile template.

## Media Policy

This profile includes no DOS, Windows, drivers, games, floppy images, CD-ROM
images, or other copyrighted media.

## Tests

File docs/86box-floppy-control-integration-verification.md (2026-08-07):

# 86Box Floppy Control Integration Verification

This guide closes the parent verification loop for `nakioman/retro-pc#6`.
The protocol authority remains `docs/86box-floppy-control-socket-contract.md`; this guide records how to prove the RetroBox daemon path, the .NET socket client, and the merged 86Box socket server work together.

## Local Gates

Run the repository test suite through the project task interface:

```bash
mise run test
```

Confirm the daemon command is present:

```bash
mise run cli -- daemon --help
```

For development without serial hardware, feed controller events through stdin.
Use `--floppy-control-socket` to override the socket path for a local VM:

```bash
printf 'INSERT monkey1-disk1,ro\nEJECT\n' \
  | mise run cli -- daemon \
      --config-root /data/retrobox \
      --floppy-control-socket /Users/nacho/Games/86Box/86box.socket
```

The daemon uses this socket path precedence:

1. CLI `--floppy-control-socket`
2. `floppyControlSocketPath` in `config.yaml`
3. `/run/retrobox/86box-floppy.sock`

## Live 86Box Socket Check

Ask the operator to start the target 86Box VM before this section.
For the current local build, the socket path is:

```text
/Users/nacho/Games/86Box/86box.socket
```

Set a shell variable for the examples:

```bash
SOCK="/Users/nacho/Games/86Box/86box.socket"
```

### Status For All Drives

```bash
printf '{"id":"status-all","command":"floppy.status","params":{}}\n' | nc -U "$SOCK"
```

Expected: one JSON Lines response with `ok: true` and `result.drives` containing zero-based floppy drive status objects.

### Status For Drive 0

```bash
printf '{"id":"status-0","command":"floppy.status","params":{"drive":0}}\n' | nc -U "$SOCK"
```

Expected: one JSON Lines response with `ok: true` and one drive `0` status object.

### Insert

Choose a floppy image visible to the running 86Box process:

```bash
IMG="/path/to/test.img"
printf '{"id":"insert-0","command":"floppy.insert","params":{"drive":0,"path":"'"$IMG"'","read_only":true}}\n' | nc -U "$SOCK"
```

Expected: one JSON Lines response with `ok: true`, `inserted: true`, `drive: 0`, the image path, and effective `read_only`.
Also confirm the guest observes a disk insertion or media-change state.

### Eject

```bash
printf '{"id":"eject-0","command":"floppy.eject","params":{"drive":0}}\n' | nc -U "$SOCK"
```

Expected: one JSON Lines response with `ok: true`, `inserted: false`, `path: null`, and `changed: true`.
Also confirm the guest observes eject or media-change state.

## Error Probes

### Invalid Drive

```bash
printf '{"id":"bad-drive","command":"floppy.status","params":{"drive":4}}\n' | nc -U "$SOCK"
```

Expected: a structured error response with `ok: false` and stable error code `invalid_drive`.

### Missing Image

```bash
printf '{"id":"missing-image","command":"floppy.insert","params":{"drive":0,"path":"/missing/test.img","read_only":true}}\n' | nc -U "$SOCK"
```

Expected: a structured error response with `ok: false` and stable error code `missing_image` or a more specific contract-compatible failure.

### Unknown Command

```bash
printf '{"id":"unknown","command":"floppy.nope","params":{}}\n' | nc -U "$SOCK"
```

Expected: a structured error response with `ok: false`.

### Malformed JSON

```bash
printf '{"id":"malformed","command":"floppy.status","params":{}\n' | nc -U "$SOCK"
```

Expected: the server returns a structured failure when it can parse enough request context, or closes the client connection after the malformed JSON frame as allowed by the contract.
86Box must keep running.

## VM Start Floppy Re-sync

When the daemon runs against the real floppy controller (`--serial-port`), it
polls the 86Box socket and sends `STATUS` to the firmware as soon as the socket
becomes ready. The firmware replies with `INSERT <id>` or `EJECT`, which the
daemon applies like a normal event, so floppy swaps made while 86Box was off
are loaded when the VM powers on.

To verify:

1. Start the daemon with the serial device and the local socket.
2. Power on a VM and confirm, in the daemon journal, a status request followed
   by an insert/eject diagnostic matching the physical floppy in the drive.
3. Power the VM off, swap the floppy, and power it back on: the journal shows a
   second insert/eject applying the new floppy, and the guest sees it loaded.

## Closeout Evidence

Record these observations before closing `nakioman/retro-pc#6`:

- `mise run test` result.
- `mise run cli -- daemon --help` result.
- 86Box PR/server evidence: `nakioman/86Box#2` merged.
- Live socket path tested.
- Status-all response shape.
- Insert response and guest-observed media change.
- Eject response and guest-observed media change.
- Error-probe results for invalid drive, missing image, unknown command, and malformed JSON.
- Any unsupported read-only behavior, if observed.

## Evidence From 2026-07-28

- `mise run test` passed: 91 tests, 0 failures.
- `mise run cli -- daemon --help` passed and showed `--config-root` plus `--floppy-control-socket`.
- Live socket path tested: `/Users/nacho/Games/86Box/86box.socket`.
- Status-all returned `ok: true` with four zero-based drive status objects.
- Status for drive `0` returned `ok: true` with the mounted boot image.
- Invalid drive returned `ok: false` with `error.code: invalid_drive`.
- Unknown command returned `ok: false` with `error.code: internal_failure` and message `Unknown command.`
- Eject returned `ok: true`, `inserted: false`, and `changed: true`.
- Insert with `read_only: true` returned `ok: true`, `inserted: true`, `read_only: true`, and a `wp://`-prefixed effective image path.
- Missing image returned `ok: false` with `error.code: missing_image`.
- Malformed JSON returned `ok: false`, `id: null`, and `error.code: internal_failure`.
- Guest-visible media change was confirmed by the operator after a slow eject/insert sequence with 5-second pauses.

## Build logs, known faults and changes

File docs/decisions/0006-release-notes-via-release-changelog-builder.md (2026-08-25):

# 0006. Release notes via release-changelog-builder, drop hand-maintained CHANGELOG.md

Date: 2026-08-25
Status: Accepted

## Context

The hand-maintained `CHANGELOG.md` drifted because `[Unreleased]` discipline
wasn't enforced on PRs; releases were tagged but the `CHANGELOG.md` had to be
hand-edited to move `[Unreleased]` to a dated section, which got missed.

## Decision

Delete `CHANGELOG.md`. Release notes for the GitHub Release are generated by
`mikepenz/release-changelog-builder-action@v6` in COMMIT mode against the
previous tag, grouped by Conventional Commit type. No PR check, no
`[Unreleased]` discipline.

## Consequences

- Contributors no longer need to update `CHANGELOG.md`. Conventional Commit
  messages become the source of truth.
- Historical releases before this change are still discoverable as GitHub
  Releases (the tag → release mapping is unchanged). The `CHANGELOG.md` file is
  deleted, breaking any deep-link references — none exist in this repo outside
  the doc map / process rules, all of which are updated in this PR.
- The release job gains an external dependency
  (`mikepenz/release-changelog-builder-action@v6`). It is well-maintained
  (v6.2.3 in June 2026, 863 stars) and read-only in COMMIT mode.
- If we ever adopt semver tags, the same action can switch to default tag
  resolution.

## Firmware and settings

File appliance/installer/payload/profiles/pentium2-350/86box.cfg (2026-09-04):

[General]
vid_renderer = sdl
emu_build_dynarec_type = new
floppy_control_socket_enabled = 1
floppy_control_socket_path = /run/retrobox/86box-floppy.sock
mouse_auto_capture = 1
start_in_fullscreen = 1
gpio_active_low = 1
gpio_enabled = 1
gpio_hdd_pin = 360
gpio_device = /dev/gpiochip0

[GL3 Shaders]
shaders = 1
shader0 = /opt/86Box/shaders/crt/crt-easymode.glslp

[GL3 Shaders - crt-easymode.glslp]
SCANLINE_CUTOFF = 700
SCANLINE_BRIGHT_MIN = 0.55
SCANLINE_BRIGHT_MAX = 0.75
MASK_SIZE = 2
MASK_STRENGTH = 0.30
MASK_STAGGER = 3
MASK_DOT_HEIGHT = 2
SHARPNESS_H = 1.0
GAMMA_INPUT = 2.4
BRIGHT_BOOST = 1.25

[Machine]
cpu_family = pentium2_deschutes
cpu_multi = 3.5
cpu_speed = 350000000
cpu_use_dynarec = 1
fpu_type = internal
machine = p2bls
mem_size = 131072
pit_mode = 1

[Video]
gfxcard = voodoo3_3k_agp
monitor_edid = 1
monitor_edid_path = /data/vms/pentium2-350/syncmaster3.edid

[Input devices]
keyboard_type = keyboard_ps2
mouse_type = ps2
tablet_type = none

[PS/2 Mouse]
buttons = 4

[Sound]
sndcard = sbawe64_gold

[Network]
net_01_link = 0
net_02_link = 0
net_03_link = 0
net_04_link = 0

[Hard disks]
hdd_01_fn = hdd.raw
hdd_01_ide_channel = 0:0
hdd_01_parameters = 63, 255, 2434, 0, ide
hdd_01_speed = 1998_5400rpm

[Floppy and CD-ROM drives]
cdrom_01_ide_channel = 1:0
cdrom_01_parameters = 1, atapi
cdrom_01_speed = 72
cdrom_01_type = 86dvd
fdd_01_audio = alps_df354h148f_80t
fdd_01_type = 35_2hd
fdd_02_type = none
fdd_host_buffering = 1

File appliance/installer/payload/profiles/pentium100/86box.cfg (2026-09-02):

[Trident TGUI 9440AGi PCI #1]
memory = 1

[Logitech Serial Mouse]
buttons = 3

[General]
vid_renderer = sdl
mouse_auto_capture = 1
start_in_fullscreen = 1
floppy_control_socket_enabled = 1
floppy_control_socket_path = /run/retrobox/86box-floppy.sock
gpio_active_low = 1
gpio_enabled = 1
gpio_hdd_pin = 360
gpio_device = /dev/gpiochip0

[GL3 Shaders]
shaders = 1
shader0 = /opt/86Box/shaders/crt/crt-easymode.glslp

[GL3 Shaders - crt-easymode.glslp]
SCANLINE_CUTOFF = 540
SCANLINE_BRIGHT_MIN = 0.45
SCANLINE_BRIGHT_MAX = 0.70
MASK_SIZE = 2
MASK_STRENGTH = 0.35
MASK_STAGGER = 3
MASK_DOT_HEIGHT = 2
SHARPNESS_H = 0.9
GAMMA_INPUT = 2.4
BRIGHT_BOOST = 1.3

[Machine]
cpu_family = pentium_p54c
cpu_multi = 1.5
cpu_speed = 100000000
cpu_use_dynarec = 1
fpu_type = internal
machine = 8500tuc
mem_size = 8192

[Video]
gfxcard = tgui9440_pci

[Input devices]
keyboard_type = keyboard_at
mouse_type = ltserial

[Sound]
sndcard = sb16

[Network]
net_01_link = 0
net_02_link = 0
net_03_link = 0
net_04_link = 0

[Hard disks]
hdd_01_fn = hdd.raw
hdd_01_ide_channel = 0:0
hdd_01_parameters = 63, 16, 4092, 0, ide
hdd_01_speed = BF25A011

[Floppy and CD-ROM drives]
cdrom_01_ide_channel = 1:0
cdrom_01_parameters = 1, atapi
cdrom_01_speed = 4
cdrom_01_type = 86dvd
fdd_01_audio = alps_df354h148f_80t
fdd_01_type = 35_2hd
fdd_02_type = none
fdd_host_buffering = 1

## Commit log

2026-07-28 docs: define 86Box floppy control socket contract
    Closes #1
2026-07-28 feat(core): connect floppy control socket
2026-07-28 feat(daemon): wire NFC floppy events (#32)
    Translate parsed Arduino insert/eject/error events into catalog-aware 86Box floppy control calls for drive 0. Preserve the serial-port and socket-server boundaries for later integration.
2026-07-28 feat(daemon): wire floppy control socket (#33)
2026-07-29 feat(profiles): add 386sx16 86Box profile (#36)
    [86box.cfg]
2026-07-29 feat(profiles): add Pentium 100 86Box profile (#37)
    [86box.cfg]
2026-07-30 feat(graphics): enable SDL fullscreen CRT shader profiles (#39)
    [86box.cfg]
2026-08-02 fix(appliance): package runtime and VM profiles (#46)
    * fix(appliance): package runtime and VM profiles
    Fixes #28
    * fix(appliance): satisfy shellcheck binary guard
    * fix(appliance): discover VM profiles dynamically
    * Did some cleanup
    * Added missing opengl package
    * fix(appliance): configure C.UTF-8 locale
    * fix(appliance): pin SSH locale
    * Added missing packages
    * fix(profiles): use absolute shader paths
    * feat(appliance): configure connected HDMI audio
    * Updated 86Box release
    * fix(appliance): add console selector and native AOT
    * fix(installer): use passwd home for ALSA config
    [86box.cfg]
2026-08-05 feat(firmware): wire PN532 NFC read/write on ESP8266 (#50)
    * Firmware nfc/serial first draft
    * Performance fixes
    * Implemented eject and nfc read
    * docs(firmware): document PN532 wiring and the real serial protocol
    The README still described the PING/PONG skeleton and the removed
    firmware-bootstrap task, so its build instructions were broken.
    Replace it with what the firmware actually does: PN532 I2C mode and
    jumpers, the D1/D2 wiring, the unconnected RSTPD_N/IRQ decision, the D6
    disk-present switch and its polarity, boot-sensitive pins to avoid, the
    raw NTAG page 4-11 payload layout, and the INIT/WRITE/TAGID/INSERT/
    EJECT/ERROR contract.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
    [RetroFloppyApp.cpp, RetroFloppyCommandHandler.cpp]
2026-08-06 Added floppy wiring doc
2026-08-06 feat(daemon): open floppy controller serial port and echo socket payload (#35) (#52)
2026-08-07 fix(appliance): gate daemon service on serial device and pass --serial-port (#53)
    * fix(appliance): gate daemon service on serial device and pass --serial-port
    The daemon unit now skips itself (ExecCondition) when no floppy controller
    serial device is attached instead of running the daemon with stdin=/dev/null.
    ExecStart passes --serial-port/--serial-baud so the daemon opens the port
    itself; .NET SerialPort sets raw mode via cfmakeraw, so the stty ExecStartPre
    is no longer needed.
    * fix(appliance): ship libSystem.IO.Ports.Native.so next to the AOT binary
    NativeAOT cannot statically link System.IO.Ports: the runtime only provides
    libSystem.IO.Ports.Native as a shared .so (runtime.linux-x64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
    [86box.cfg]
2026-08-07 fix: boot selector return, splash handoff, and floppy re-sync on VM start (#55)
    * fix: resolve boot selector, boot splash, and floppy re-sync bugs
    - boot: return to the VM selector when a VM closes instead of leaving tty1
    blank; Esc on the post-VM selector ends the session back to the login
    - splash: keep Plymouth up until 86Box's first frame (retain before launch,
    quit before the selector) and discard 86Box stdout so no boot text flashes
    - daemon: re-sync the floppy drive when a VM starts via a new firmware STATUS
    command that reports the current physical floppy
    * fix(firmware): reply EJECT from STATUS when the floppy detector is unavailable
    * refactor(firmware): handle STATUS in t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
    [RetroFloppyApp.cpp]
2026-08-18 feat(appliance): first-boot WiFi via wpa_supplicant + systemd-networkd (#57)
    * feat(appliance): first-boot WiFi configuration via systemd-networkd
    The appliance now detects a USB WiFi NIC at boot and prompts for SSID
    and password on first boot with dialog, persisted under /data/system/.
    The systemd-networkd [WiFi] config is materialized into /run every
    boot so the read-only root is never written at runtime. linux-firmware
    is bundled so Realtek (rtw88) and Atheros USB dongles work out of the
    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
2026-08-24 fix(ci): detect previous release tag for installer changelog (#59)
    The release job used `gh release list --limit 2 --jq '.[1].tagName'` to
    find the previous release, which always skipped the most recent prior
    release (and returned null when only one release existed), so every
    release published since the job was added came out with an 'Initial
    release' changelog.
    Use `.[0]` with `--limit 1` instead, and tighten the git-tag fallback
    to only consider appliance-* tags so orphan tags from failed runs do not
    poison the result.
2026-09-01 fix(installer): improve system partition and reinstall flow (#66)
    * fix(appliance): keep system partition writable
    * fix(installer): allow full reinstall from prompt
    * fix(installer): center installer banner title
    * fix(installer): remove BIOS to UEFI migration step
    * fix(installer): set initial GRUB video mode
    * fix(installer): persist SSH host keys across updates
    * fix(installer): fall back to available ALSA playback
    * fix(appliance): configure ALSA output at boot
    * fix(appliance): retry runtime audio detection
    * fix(appliance): log runtime audio setup
    * fix(appliance): read ALSA PCM metadata from info
    * fix(installer): remove install-time audio detection
2026-09-02 feat(appliance): grant retrobox GPIO device access (#70)
2026-09-02 feat(appliance): create VM HDD images dynamically (#63)
    * feat(appliance): create VM HDD images dynamically
    * fix(appliance): avoid proc fd in HDD creation
    [86box.cfg]
2026-09-02 feat(appliance): add Pentium II 350 VM profile (#71)
    * feat(appliance): add Pentium II 350 VM profile
    - Add pentium2-350 86box.cfg (p2bls, P2 Deschutes 350MHz, 128MB, Voodoo3,
    AWE64 Gold, GPIO, hdd.raw 63/255/2434 ~20GB, EDID SyncMaster,
    crt-easymode shader) + binary syncmaster3.edid (128B)
    - Update 386sx16/pentium100 to crt-easymode shader on /opt/86Box and
    hdd.raw dynamic generation (remove local syncmaster3.glsl)
    - Add/update READMEs: document hdd.raw generation, new shader path and
    per-profile params, EDID; create README for pentium2-350
    - Register VM in vms.yaml as pentium2-350
    * fix(appliance): update 86Box to v104 and enable GPIO on 386sx16/pentium100
    - Bump BOX86_VERSION 5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
    [86box.cfg]
2026-09-03 feat(firmware): detect floppy insert/eject by polling the NFC tag (#72)
    The mechanical disk-present switch never actuated reliably in the
    modified drive, so it is gone: the tag glued inside the floppy shell now
    doubles as the presence sensor. The firmware polls the PN532 with
    fast-fail activation (setPassiveActivationRetries) — every 100 ms with a
    disk seated (cheap presence check), every 250 ms while empty (full
    detect+read) — and a state machine with hysteresis emits the events:
    - INSERT fires only once the payload actually reads, removing the race
    where the tag was read the instant the switch flipped.
    - EJECT fires after 3 consecutive missed polls (~300-400 ms), absorbing
    single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
    [RetroFloppyApp.cpp]
2026-09-03 feat: NFC bench-test script and printable NFC floppy (#73)
    * feat(firmware): detect floppy insert/eject by polling the NFC tag
    - EJECT fires after 3 con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
    [base.stl, floppy-nfc.scad, top.stl]
2026-09-04 docs: web panel design spec and phase 1 implementation plan (#80)
    * docs: design for the web panel and NFC assignment
    Spec for a LAN-reachable web panel that manages the floppy library and
    assigns cataloged floppies to physical NFC tags.
    The panel is hosted inside the daemon process because the daemon owns the
    serial port exclusively, and is built as a Minimal API with an embedded
    static frontend so the Native AOT publish keeps working. Adds a line router
    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
2026-09-04 feat(daemon): refuse to mount a floppy with no assigned tag (#75)
    * feat(daemon): refuse to mount a floppy with no assigned tag
    * fix(daemon): update unassigned tag error message to reference CLI command
    The rejection message for floppies with no assigned tag now references the
    CLI command 'retrobox nfc write <id>' instead of a non-existent web panel.
    Updated the test assertion to verify the CLI command is mentioned in the error.
    * docs: document nfc field behavior in floppies.yaml
    Added explanation of the nfc field in the data model section:
    - describes what the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
2026-09-04 feat(daemon): add a serialized NFC command channel with a timeout (#78)
    * feat(daemon): add a serialized NFC command channel with a timeout
    IRetroBoxNfcCommandChannel lets a caller send TAGID and WRITE without
    knowing about serial ports. Commands are serialized behind a semaphore
    (there is one drive) and bounded by a 5s timeout so a wedged controller
    cannot hang a caller forever. SendAsync accepts an optional follow-up
    command to send while the gate is still held after an OK reply, so a
    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
2026-09-04 feat(daemon): track drive state and re-announce the tag after a write (#79)
    * feat(daemon): track drive state and re-announce the tag after a write
    The firmware stays quiet after a WRITE, so the daemon never learned the
    tag changed. WriteTagAsync now sends STATUS as SendAsync's followUpOnOk
    after a successful write, which makes the firmware re-announce the
    seated tag as an INSERT event and mounts the newly assigned image
    through the normal event path.
    Adds RetroBoxDriveState/RetroBoxDriveStateTracker so a later web layer
    can read what is in the drive; RunAsync feeds it from the event loop.
    ERROR events are left alone, since a failed read is not an eject.
    The socket watcher's background ST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
2026-09-04 docs: phase 2 implementation plan for the web panel (#81)
    Five stacked PRs: a live catalog source, the RetroBox.Web host with a
    read-only catalog API, the upload/delete/patch endpoints, the panel itself
    in Spanish and English, and the appliance wiring.
    Two deliberate departures from the spec's phase list, both recorded in the
    plan. The live catalog moves out of "Phase 2 prerequisites" and into phase 2,
    because phase 2's own endpoints create the staleness the prerequisite
    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
2026-09-04 test(daemon): replace fixed delay with bounded poll in watch socket test (#83)
    Replace the unreliable fixed 100ms delay with a bounded poll that waits
    for exactly 2 STATUS writes to appear, accommodating system load. Use
    Environment.NewLine instead of hardcoded \n for cross-platform compatibility.
2026-09-04 Move GL3 Shaders settings in Pentium2 profile (#89)
    [86box.cfg]
2026-09-04 feat(web): host a read-only catalog API inside the daemon (#85)
    * feat(web): host a read-only catalog API inside the daemon
    Adds RetroBox.Web: a Kestrel host built with WebApplication.CreateSlimBuilder,
    started inside the daemon process because the daemon is the sole owner of the
    serial port. Exposes GET /api/catalog (camelCase JSON via a source-generated
    JsonSerializerContext) and serves the panel shell from embedded resources so
    the appliance stays a single binary. The daemon command gains --web-port
    (default 8080, 0 disables it) and its action becomes async so the host's
    lifetime brackets the read loop.
    * fix(web): enable the RequestDelegateGenerator instead of suppressing AOT warnings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
2026-09-04 feat(web): add the floppy library panel in Spanish and English (#88)
    * feat(web): add the floppy library panel in Spanish and English
    * fix(web): recover from network failures and widen offline/parity tests
    Wrap patchFloppy, deleteFloppy and uploadFiles in try/catch/finally so a
    rejected fetch (server down, connection dropped) surfaces networkError and
    re-enables the button or clears the upload status, instead of leaving the
    UI stuck forever. Add networkError to both dictionaries.
    Widen The_panel_loads_nothing_from_the_network to scan app.css and app.js,
    not just index.html. Fix the key-parity regex to also match quoted,
    hyphenated error-code keys, which the previous pattern silently skip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
2026-09-04 feat(appliance): serve the web panel from the daemon unit (#90)
    * feat(appliance): serve the web panel from the daemon unit
    Make the serial device optional by removing the ExecCondition from the daemon
    unit, allowing the web panel to run without a floppy controller attached. Add
    --web-port to the daemon command, pass WEB_PORT from the installer environment,
    and document the panel in architecture.md and appliance/README.md.
    * fix(appliance): WEB_PORT fallback and corrected panel documentation
    Add Environment=WEB_PORT=8080 fallback in daemon.service to prevent crash-loop
    when daemon.env lacks WEB_PORT (e.g., older installat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
2026-09-05 docs: phase 3 plan, and two spec corrections (#91)
    * docs: split NFC assignment out of the games phase
    Nothing in NFC assignment depends on games, and until it ships a floppy
    uploaded through the panel cannot be inserted at all — the panel's own
    primary workflow produces something inert. Cover art does depend on games
    existing, so it keeps following them.
    Also records that localization is not a phase: Spanish and English shipped
    with the panel in phase 2, because the UI is written there and deferring the
    strings would have meant writing every one of them twice.
    * docs: correct the spec premise that shipped a crash loop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
2026-09-05 fix(cli): keep reopening the floppy controller until it appears (#92)
    * fix(cli): keep reopening the floppy controller until it appears
    The daemon used to open the serial device once and give up, so a
    controller-less appliance (the installer writes SERIAL_DEVICE even with
    no controller detected) or a boot-time USB enumeration race lost the
    floppy drive until someone restarted the unit. The daemon action now
    supervises the open through a retry loop, reporting an outage once per
    outage rather than once per attempt, and never exits over a missing or
    unplugged controller as long as the panel or the loop itself can keep
    going.
    The open is reached through an injectable opener seam
    (serialDeviceO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
2026-09-05 feat(web): report live drive state over server-sent events (#93)
    * feat(core): expose an atomic catalog snapshot
    Pair the catalog with its load error behind one Snapshot property so a
    reload landing between two separate reads can no longer show a fresh
    catalog next to a stale error banner. Current and LastError become
    default interface members derived from Snapshot for existing callers.
    * feat(web): report live drive state over server-sent events
    Expose /api/drive and /api/drive/events so the panel can tell an
    empty drive, a cataloged floppy from the event stream, and a blank
    tag the event stream can never see (a blank tag never raises an
    INSERT, so TAGID is the only way to ask) apart. Th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
2026-09-05 fix(daemon): quarantine late serial replies so they cannot answer the next command (#94)
    * feat(daemon): add router quarantine slot for orphaned replies
    Add RetroBoxSerialLineRouter.WaitForClearSlotAsync so a caller can wait
    out an outstanding orphan window before beginning a new command, and
    ExpectOrphanedReply so a window can be armed without cancelling a
    pending command. The window's closing is now signalled (not just timed
    out), so an absorbed straggler wakes a waiter immediately instead of
    riding out the whole window in tests and in production alike.
    * fix(daemon): quarantine the orphan window and the follow-up reply
    Wait for a clear orphan slot before beginning a command, so a retry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
2026-09-05 feat(web): add the drive panel and the assign-tag flow (#97)
    * feat(web): assign drive panel with tag reassignment confirmation
    Adds the drive section above the library, subscribed to /api/drive/events,
    with a picker and write button wired to POST /api/nfc/write. Localizes the
    new strings and the five nfc error codes in both es and en, with a parity
    test pinning each pair. A tag-already-assigned 409 always requires an
    explicit confirm before resending with confirm: true, per Ruling 27: a
    blankTag reading is never treated as proof the tag is free.
    * docs+fix(daemon): point the mount guard and docs at the web panel
    The untagged-insert guard and the appliance/architecture docs described
    stop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
2026-09-05 fix: close the seams the whole-branch review found (#98)
    * fix(web): catch a tag whose owner only the firmware knows
    AssignTag is the first and only writer of NfcUid, so on any appliance
    upgraded into this phase every already-tagged floppy carries Nfc: true with
    NfcUid: null. The tag-already-assigned guard matched owners by NfcUid alone,
    so it never fired for those tags: the first panel assignment onto a
    pre-existing tag overwrote it silently and left the old catalog entry showing
    a Tagged badge for a tag it no longer owned.
    A non-blank tag names its owner in the INSERT the firmware raises, so the
    drive tracker is authoritative regardless of what the catalog recorded. The
    ownership check n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
2026-09-06 feat(hardware): add 3D-printable Macintosh Classic case (#118)
    Add hardware/mac-classic-case: the full-size Macintosh Classic style case
    that houses the RetroBox PC (micro-ATX board, ATX PSU, floppy, slim DVD,
    9.7" retina LCD, 2.5" drive). The OpenSCAD source derives from Jeroen
    Domburg's 1:6 mini Mac (beer-ware notice retained), rescaled to 1:1 and
    reworked so every piece fits a 250 mm bed. Includes the rendered STLs the
    reference build was printed from, a README with BOM/print/assembly notes,
    and a `case-stl` mise task backed by scripts/render-case-stl.sh.
    Also commit the rendered floppy-nfc.stl (drop its .gitignore) so all
    printable hardware ships pre-rendered, and mark *.stl as binary.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
    [back-lower-left.stl, back-lower-right.stl, back-upper-left.stl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]
2026-09-08 feat(web): migrate RetroBox panel to React (#121)
    * feat(web): migrate panel to React
    * chore(web): ignore generated Vite assets
    * fix(core): use compact floppy IDs
    * fix(web): show cover search progress
    * fix(web): improve NFC write flow
    * fix(web): label NFC reassignment owner
    * fix(web): show cover save progress
    * fix(web): host message boxes in app shell
2026-10-30 feat: QEMU CD-ROM disc-change refresh and installer KVM host checks (#132)
    * docs: plan XP phase 4 CD-ROM and installer host checks
    * feat(core): add QEMU QMP client
    * feat(core): refresh the QEMU VM's CD-ROM after a disc change
    Reopen the installer-detected drive over QMP (blockdev-change-medium on ide1-cd0, raw, read-only) when a disc is present, or force-eject it when the drive is empty. The launcher now attaches the driv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
    * feat(cli): add cdrom refresh command
    * feat(appliance): trigger the CD-ROM refresh from udev media-change events
    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
2026-10-31 fix: appliance bring-up (no libicu, QEMU session without xset) (#133)
    * fix(cli): run without libicu via invariant globalization
    The installer now runs retrobox in the target chroot (vm create-disks), and
    the appliance root ships no libicu, so the binary aborted at startup.
    Enable InvariantGlobalization and smoke-test the published binary on a
    bare debian:trixie-slim in CI.
    * fix(appliance): name the QEMU binary in the installer's staging line
    Match the 86Box line, which names the staged AppImage.
    * fix(core): disable X blanking with server flags instead of xset
    The appliance ships no x11-xserver-utils, so qemu-session's xset call threw
    and X exited before QEMU started. Pass -s 0 -dpms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
2026-10-31 feat: QoS — LAN IP and loading screen in machine selector, panel on port 80, /data free space (#134)
    * feat: show LAN IP in machine selector, serve panel on port 80, show /data free space
    - Machine selector prints the appliance's LAN IPv4 address(es)
    - Web panel defaults to port 80; daemon unit grants CAP_NET_BIND_SERVICE
    - New /api/system endpoint reports free bytes on the /data filesystem;
    the panel status bar shows it as 'xx MB/GB Free'
    * feat(cli): show a starting screen after choosing a VM in the selector
    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
2026-11-01 fix(hardware): clip-on DVD tray cover with a separate eject button (#136)
    The glued tray cover is replaced by one that snaps into the tray's
    original bezel clip slots, and the stiff printed eject membrane by a
    separate push button trapped between the cover and the tray.
    - Two 1 mm clips (left vertical, right horizontal) with outward barbs,
    growing from the cover's flat back, which now rests on the tray face
    (odd_cover_gap 9.96 -> 8).
    - Cover outline derived from the front's slot cutout parameters with a
    constant 0.3 mm clearance; the previous outline was wider than the
    slot and rubbed, worst on the right.
    - New printable part dvd-eject-button: 13 x 7 face, flange one layer
    thinner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
2026-11-01 fix(hardware): replace the floppy eject cap with a snap-in plunger (#135)
    The glued eject cap didn't work. Replace it with a solid plunger that fills
    the front's eject hole and snaps in from outside with the case closed: two
    slots open at the back free a top and a bottom leaf spring with bumps that
    lock behind the wall, while the full-length core presses the eject lever.
    The plunger is sized from the printed (painted) hole via ejp_hole, since
    paint and print shrink closed the modeled 11x8 hole; 9.4 x 6.6 is
    fit-tested. Remove eject_cap, fdd_latch and eject-cap.stl.
2026-11-01 feat(daemon): NFC floppy for QEMU VMs over QMP (XP Phase 5) (#138)
    Inserting an NFC floppy mounts its floppies.yaml image in a QEMU VM's A:
    drive (floppy0) and removing it ejects the image, as with 86Box. The
    daemon routes floppy commands to whichever VM socket answers (ADR 0011);
    QMP commands use one short connection each and a busy socket is retried.
2026-11-02 chore(appliance): pin QEMU retrobox-11.1.1-2 (#139)
    Picks up the vmvga fix for render-target-only X8R8G8B8 surfaces (Prince of Persia: The Sands of Time flickered washed-out on every other frame with ColorDiffusion on) and the AC97 volume fix.
2026-11-02 chore(appliance): pin 86Box v7.0.0-master.125 (#140)
